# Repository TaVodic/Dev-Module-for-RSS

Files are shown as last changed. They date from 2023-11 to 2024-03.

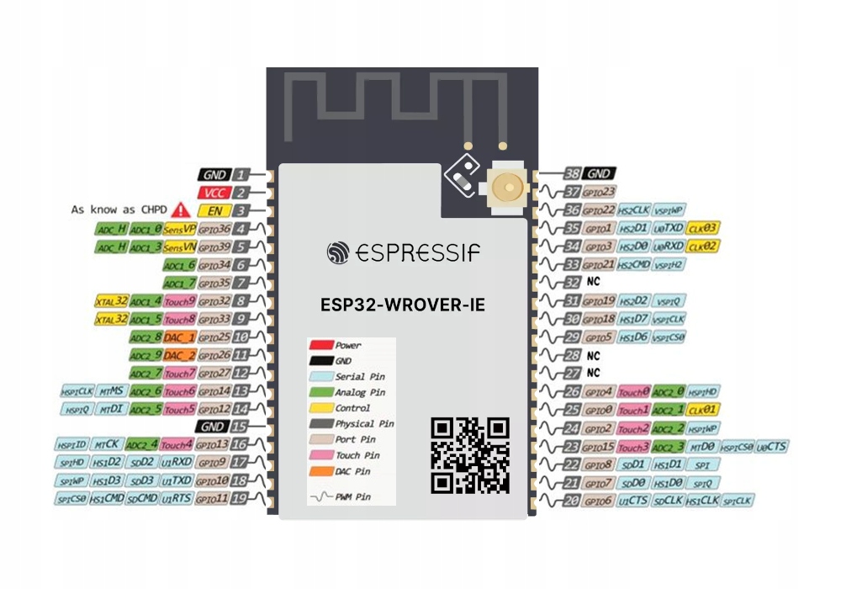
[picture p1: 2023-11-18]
Datasheets/ESP32-WROVER-IE-PINOUT.jpg

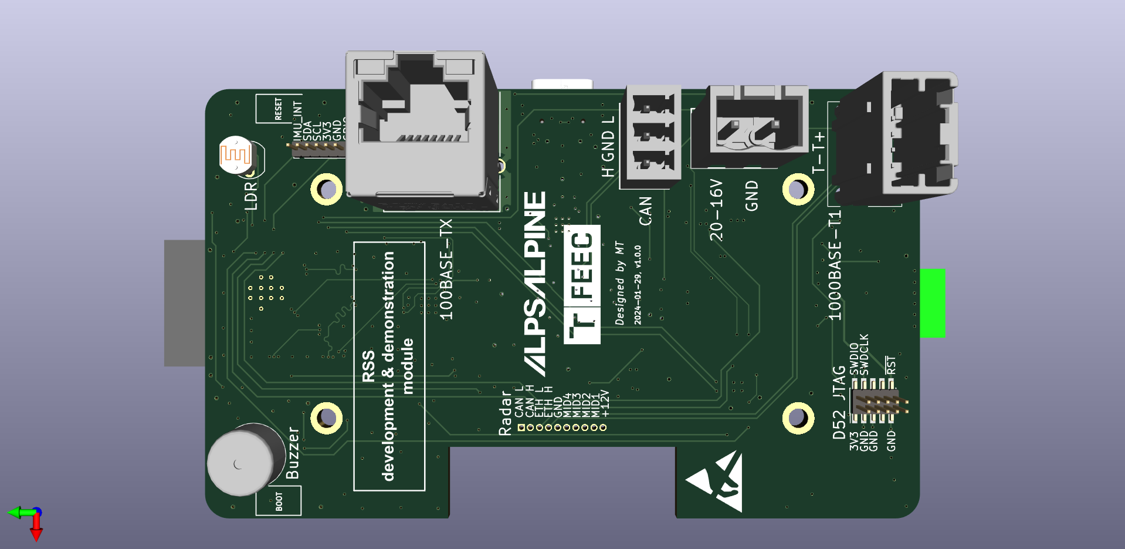
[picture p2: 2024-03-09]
documents/visuals/PCB_3D_BOTTOM_v1.0.0.png

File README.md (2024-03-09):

# Development Module for Safety Radar Sensor in Single-Track Vehicles

<!-- ### Features on PCB
* ESP32
    * BLE
    * MAC
    * 2 UARTs (flashing/debugging + radar interface)
    * $I^2C$ or SPI
* CP2102 USB-UART module
* PHY Ethernet module with connector
* IMU (6+3 DoF)
* Power management
* LED neopixel
* Buzzer
* Pogo pins – board to board connector
* ESP32 GPIO <-> radar pins (FFC conn)
* 100BASE-T1 connector
* ANT+ module -->

The RSS project includes two software repositories:

* ROS2 package as emulation of radar procesing unit and RSS demo module [(RSS_ROS2)](https://gitext.alps.cz/240703/rss_ros2)
* ESP-IDF project for ESP32 implementing uROS and all hardware peripherals [(RSS_uROS)](https://gitext.alps.cz/240703/rss_uros)

### [Schematic design](documents/RSS_schematic_v1.0.0.pdf)

### [Thesis](documents/Tavoda_semestral_thesis.pdf)

### [EEICT article](documents/Development_Module_for_Radar_Safety_Sensor_in_Single_Track_Vehicles.pdf)

### [Photo documentation](documents/visuals/)

### Block diagram



### Power management diagram



### ROS2 graph



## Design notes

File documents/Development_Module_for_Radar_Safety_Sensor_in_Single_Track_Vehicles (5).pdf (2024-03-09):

# Development Module for Radar Safety Sensor in Single-Track Vehicles

Martin Tavoda ˇ

FEEC Department of Radio Electronics Brno University of Technology Brno, Czech Republic
martin.tavoda@vutbr.cz

Abstract—This article describes the hardware and software design of the development module for the Radar Safety Sensor (RSS). RSS uses a Frequency-Modulated Continuous Wave (FMCW) radar to track moving objects behind single-track vehicles. The current radar configuration and antenna have significant object tracking deficiency when the vehicle makes a turn and the radar Field of view (FOV) tilts. The assumed solution is to add an Inertial Measurement Unit (IMU) data to the tracking algorithm. The IMU is implemented in the designed development module, which also provides an efficient development and debugging environment.
Index Terms—embedded device, cyclo-safety equipment, ROS 2, micro-ROS, FMCW radar
I. INTRODUCTION
During the development of firmware for a new product, there is a need for easy debugging and function testing.
The designed module will serve the company ALPS ALPINE Co., Ltd. in the development of Radar Safety Sensor (RSS). Together with the ALPS Generic Radar 5, it should result in a similar device as the already existing Ride Safety System RS 1000 or GARMIN Radar Tail Light. These devices are safety equipment for cyclists that offer information about vehicles behind them. If the vehicle is approaching too quickly or it is driving too close the cyclist and also the driver are warned. [1]
The designed module function is to process data from a IMU and send them to a Single Board Computer (SBC) through a Robot Operating system (ROS) domain. As an output, it collects result data from a ROS domain and triggers an alert. Additionally, it provides robust connectors, power management, ANT+ connection, and physical mount to single-track vehicles, specifically a bicycle. The whole system is supplied from an external 18 V Li-Ion accumulator.

II. PROBLEM FORMULATION
ALPS ALPINE Co., Ltd. is developing a new cyclo product using a proprietary radar system with a new tracking algorithm. However, they ran into a problem. In the default scenario, the radar is mounted under the bicycle seat and the bicycle is moving in a straight line (no tilt). The radar sees multiple points, where some of them are reflections from a static background (the blue dots in Figure 1), and the rest are reflections from actual moving targets behind the bicycle (the green dot in Figure 1).

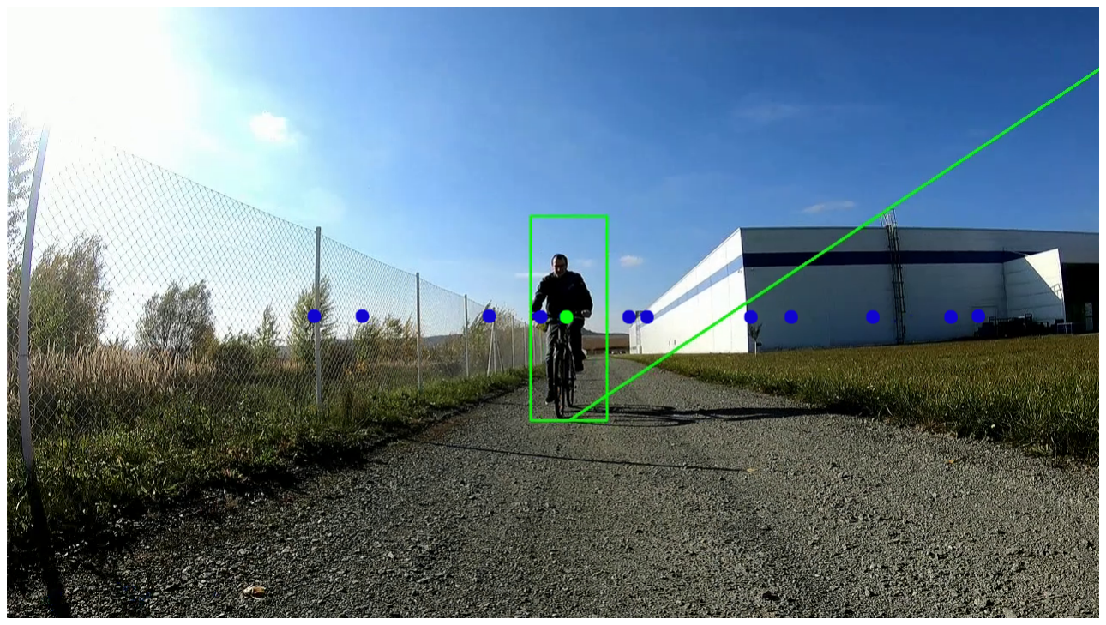
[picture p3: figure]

Fig. 1. Correct tracking - straight ride

In this scenario, these two conditions are easily distinguishable in processed radar data output and the ego-motion vector can be calculated from these reflections of static background. Ego-motion vector describes the motion of an object relative to the rigid scene. [2] In this context it consists of two elements, direction (forward or backward), and speed (approaching or receding). In the current radar configuration, the radar FOV is only a horizontal line, there is no elevation data, and the ego-motion vector is only one-dimensional. The reflections from moving targets are clustered and classified, and a tracking algorithm is used. From these data, it is possible to estimate the moving target trajectory, and speed (approaching or receding),

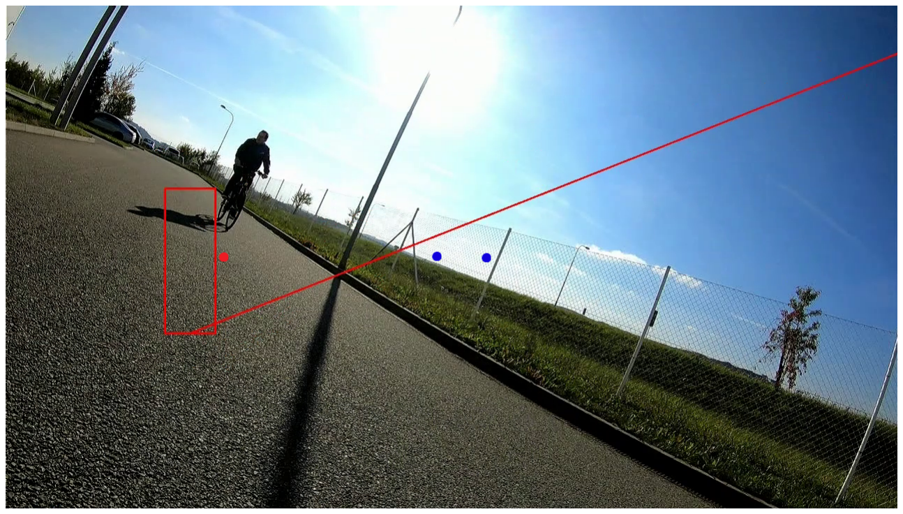
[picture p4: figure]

Fig. 2. Tracking degradation - ride in turn classify if it’s a car or truck, and calculate the possibility of a potential collision.
However, if the bicycle tilts, for example, when turning, the radar FOV also tilts with the same angle and this condition cannot be detected from radar data alone. Since the ego-motion vector is only a single dimensional and the height of the radar from the ground changes, the previously tracked object could be tracked incorrectly (see in Figure 2) or can disappear altogether.
A similar problem is described in [3], but the company requested a simpler approach. One possible solution to this problem seemed to be adjusting the tracking algorithm parameters to be more lenient, but this resulted in insufficient accuracy. The development team decided to try to add to the tracker algorithm some external information about radar tilt and position in space to enhance the tracking estimation. This information can be obtained from an IMU located in a development module.
After the successful implementation of the IMU data into the tracking algorithm by the ALPS team they need to easily show the performance of this product. For this purpose, the development module offers output peripherals such as highly luminous LEDs and loud buzzer and also the ability to connect to external devices such as wireless ANT+ fitness accessories.

III. SYSTEM DESIGN

The system design is shown in Figure 3. The development module for the RSS consists of multiple blocks. The main part is the microcontroller ESP32 which collects the raw data from the IMU using the I²C bus. These data are then processed and sent to the ROS domain via Ethernet. Ethernet connection is provided by Media access control sublayer (MAC) and Physical layer (PHY) interfaces. MAC is included in ESP32 and PHY is an external component. They communicate with each other by Reduced Media-independent interface (RMII). Ethernet was preferred over WiFi due to its lower latency. As IMU is used the MPU5060 chip and the PHY interface is provided by IP101GR.
On the SBC run multiple processes. They are ROS2 graph members, which merge the IMU and radar data and provide

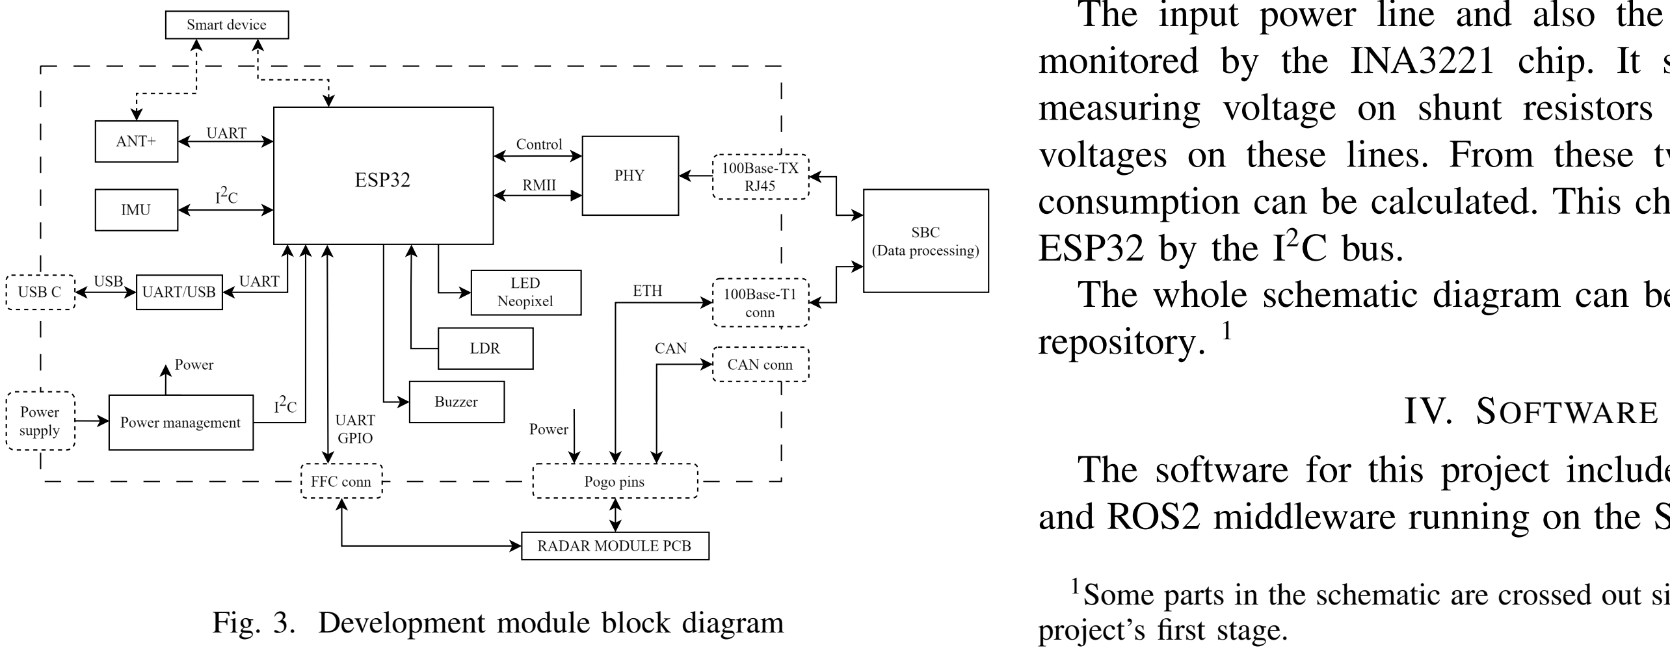
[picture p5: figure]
ESP32 by the I²C bus.; repository. 1; IV. SOFTWARE; project’s first stage.

Fig. 3. Development module block diagram

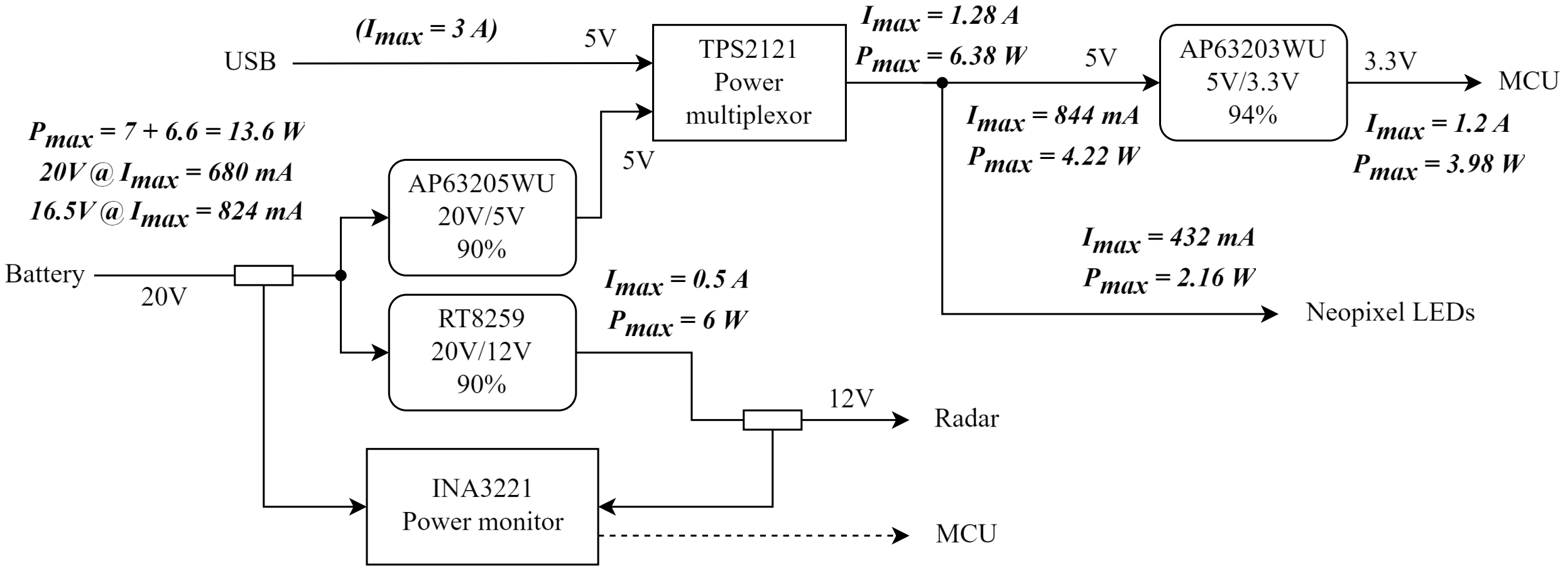
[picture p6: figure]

Fig. 4. Power management block diagram

sensor fusion. This is the tracking algorithm designed by the ALPS development team. The output of this algorithm (a threat level) is sent back to the ESP32, whose task is to provide an alert by visual or sound peripherals.
As visual output the programmable RGB LEDs WS2812B mini are used. They are placed on the perimeter of the Printed circuit board (PCB) and the brightness of these LEDs is adjusted by the software according to the amount of ambient light. This level is read from the external photoresistor by the Analog-to-digital converter (ADC) included in the ESP32. The output threat level from the tracking algorithm can be also wirelessly sent to an external smart device such as a phone or commercially available fitness accessories. This communication is provided by the WiFi peripheral inside ESP32 or the external ANT+ module D52 by GARMIN. The power management block is shown in Figure 4 and it consists of four power lines. The external accumulator has a nominal voltage of V = 18 V but the radar needs to be supplied with a voltage of V = 12 V. Therefore the RT2589 DC/DC step-down converter is used. For supplying LEDs the AP63205 DC/DC converter with fixed output voltage V = 5 V was chosen. The same converter but with a different fixed output voltage of V = 3.3 V is used to supply all chips on the PCB.
Besides the fact that the USB connector serves as a programming interface for the ESP32, it also serves as a second power source. The seamless transition between 5 V converted from the battery voltage and the voltage from the USB is provided by the TPS2121 power multiplexer. When both sources are available the USB source has priority, but when it’s not present the module is powered by the battery.
The input power line and also the 12 V power line are monitored by the INA3221 chip. It senses the current by measuring voltage on shunt resistors and it also measures voltages on these lines. From these two values, the power consumption can be calculated. This chip communicates with

The whole schematic diagram can be found in the GitHub

The software for this project includes firmware in ESP32 and ROS2 middleware running on the SBC. The whole ROS2

1Some parts in the schematic are crossed out since they are not used in the

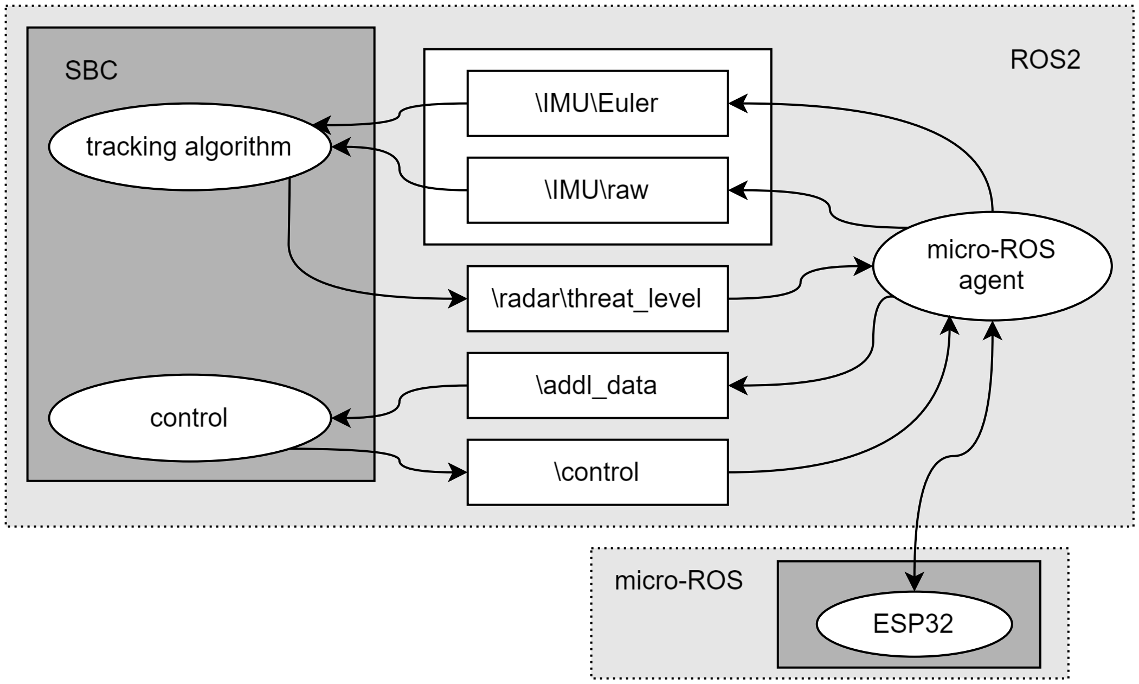
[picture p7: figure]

Fig. 5. RSS ROS2 graph (nodes are in ellipses, topics are in rectangles)

graph can be seen in Figure 5. The SBC runs two ROS2 nodes. One of them, the tracking algorithm, subscribes to topics containing the Euler angles and raw data from the IMU. As an output, it publishes the threat level. The other node, the control node, subscribes to additional information, such as temperature, power consumption, and amount of ambient light, and publishes instructions for power management ICs. All the topics use standard ROS2 messages. Development of this system was done on Microsoft WSL with running the Ubuntu distribution. All ROS2 principles were sourced from the ROS2 wiki. [4]
The firmware for ESP32 was written in C using the ESP-IDF framework. While ROS2 is a powerful tool for nonresource-constrained devices, for embedded devices it cannot be used. Fortunately, there exists a lightweight version of ROS2 for microcontrollers, called the micro-ROS. [5] It can be compiled for ESP32 but to communicate with the ROS2 graph it needs an agent, which runs also on SBC. The micro-ROS libraries were imported to the ESP-IDF environment as a component and were used to create the only node on ESP32. The whole firmware is supported by the FreeRTOS system. The ESP32 takes the raw data from the IMU as linear acceleration and angular velocity and transforms them using the Kalman filter to Euler angles. This method is described in [6]. The node publishes both the raw data and the Euler angles. On the other hand, the subscribed threat level is used to light up the LEDs or beep the buzzer. The additional information on power consumption is calculated from voltage and current values obtained from the power monitor IC. This information together with others previously mentioned is published to the \addl data topic. The voltage converter for the radar can be disabled according to the message from the \control topic.
V. HARDWARE DESIGN

The PCB was designed in KiCad freeware software. Since the design includes 50 MHz clock lines and differential pairs, the impedance control and delay matching principles had to be followed when designing the PCB. The PCB has four layers with the following stack-up: high-speed traces, GND plane,

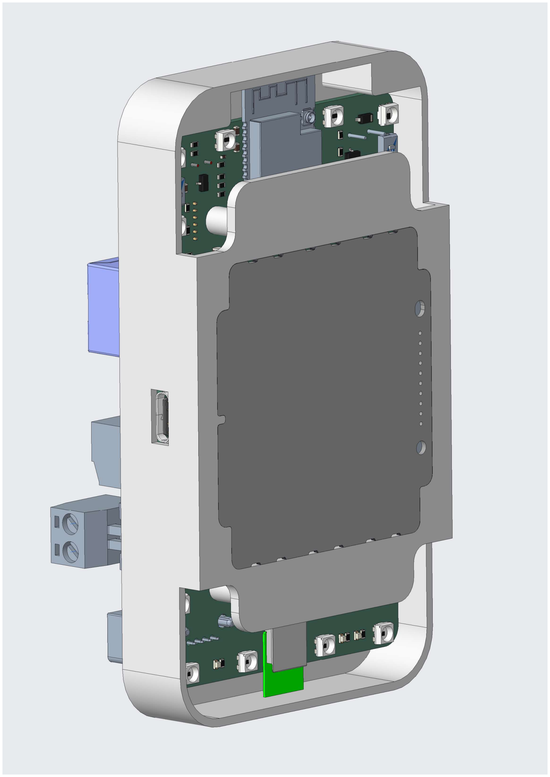
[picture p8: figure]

Fig. 6. 3D design of the enclosure with the module and radar board

power domains, and low-speed signals. The visuals of the PCB can be found in the GitHub repository. (https://github.com/TaVodic/Dev-Module-for-RSS/tree/public_files/documents/visuals)
The ALPS Generic Radar 5 is connected to the development module by spring-loaded pins and Flexible flat cable (FFC) used for future debugging. Both boards are enclosed in 3D printed covering mounted on the seat pole of a bicycle. The design of the complete device is shown in Figure 6.

VI. CONCLUSION
The development module was designed, manufactured, and assembled according to the needs of the company. The software concept was presented and needs to be programmed and verified. Finally, the ALPS development team can use this module for future development of the ALPS Generic Radar 5, but mainly to prove the concept of enhancing the tracking algorithm by the external IMU data.

REFERENCES

[1] P. Norman, “What are rearview radar bike lights and should you use one?”, Bike Radar, 2023.
[2] N. H. Khan and A. Adnan, “Ego-motion estimation concepts, algorithms and challenges: an overview”, Multimedia Tools and Applications, vol. 76, no. 15, pp. 16581-16603, 2017.
[3] L. Seongwook, S. Lee, S. Lim, and S. -C. Kim, “Machine Learning-Based Estimation for Tilted Mounting Angle of Automotive Radar Sensor”, EEE Sensors Journal, vol. 20, no. 6, pp. 2928-2937, 2020.
[4] S. Macenski, T. Foote, B. Gerkey, C. Lalancette, and W. Woodall, “Robot Operating System 2: Design, architecture, and uses in the wild”, Science Robotics, vol. 7, no. 66, May 2022.
[5] P. Nguyen, “MICRO-ROS FOR MOBILE ROBOTICS SYSTEMS”, Master thesis, Vaster ¨ as, 2022. ˚
[6] H. Ferdinando, H. Khoswanto, and D. Purwanto, “Embedded Kalman Filter for Inertial Measurement Unit (IMU) on the ATMega8535”, in 2012 International Symposium on Innovations in Intelligent Systems and Applications, 2012, pp. 1-5.

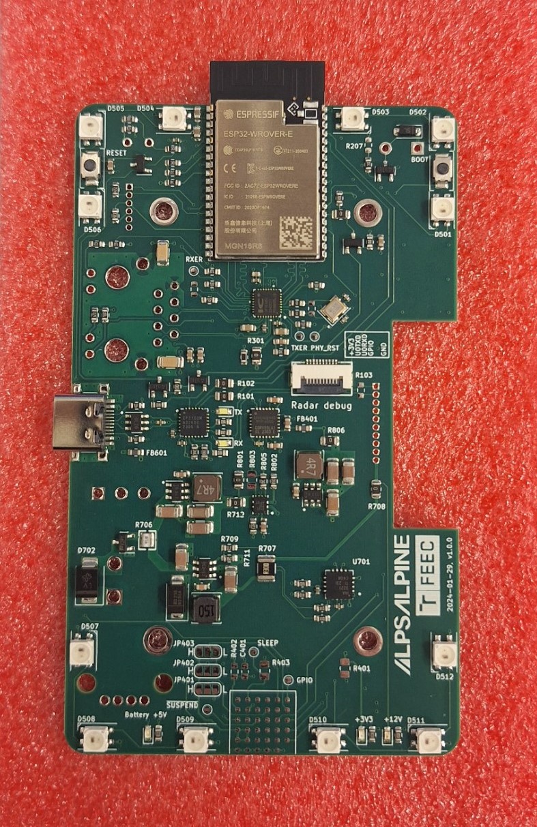
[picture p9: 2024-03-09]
documents/visuals/TOP.jpeg

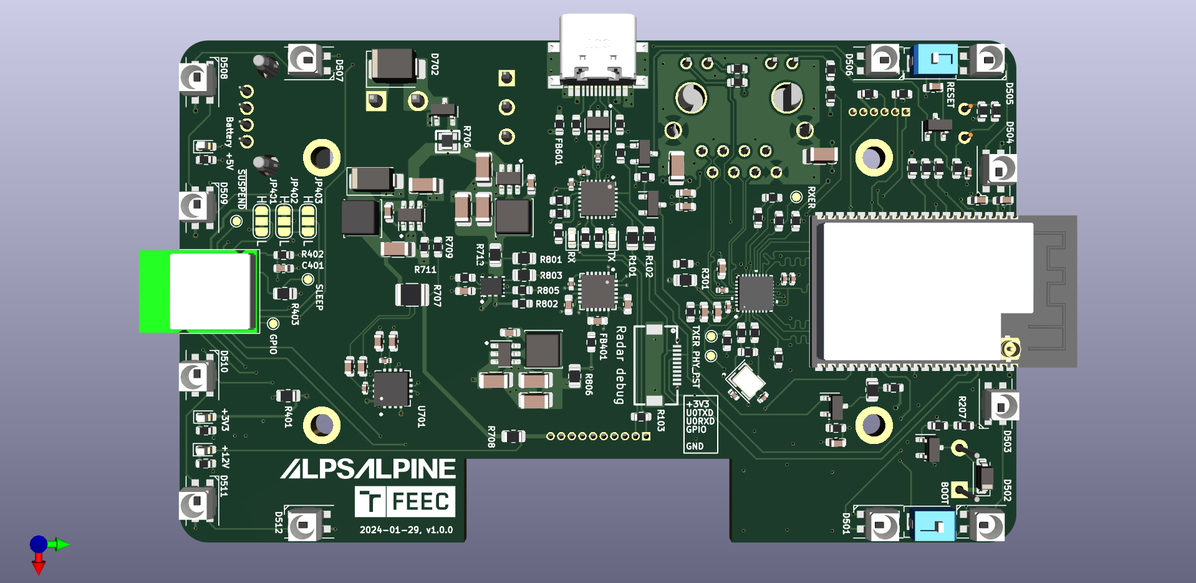
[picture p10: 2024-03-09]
documents/visuals/PCB_3D_TOP_v1.0.0.png

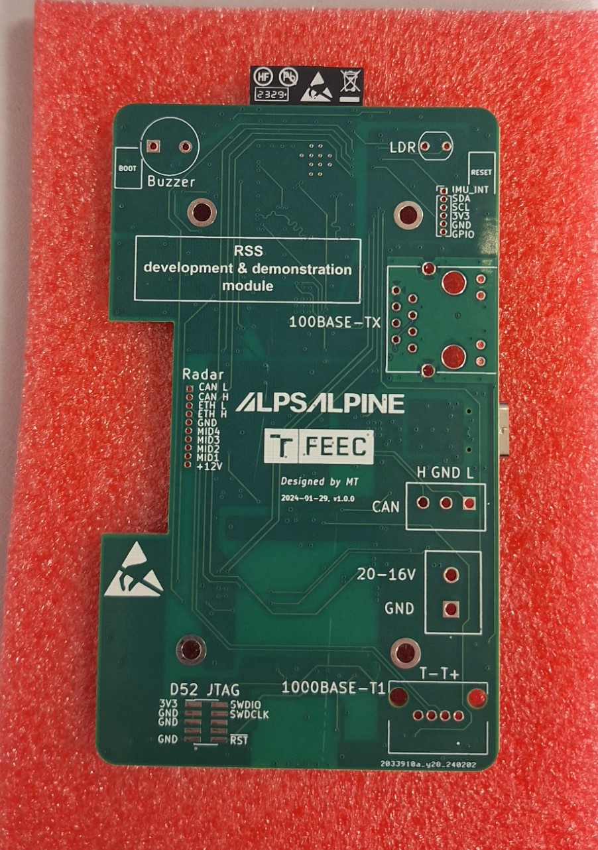
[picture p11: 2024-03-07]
documents/visuals/BOTTOM.jpeg

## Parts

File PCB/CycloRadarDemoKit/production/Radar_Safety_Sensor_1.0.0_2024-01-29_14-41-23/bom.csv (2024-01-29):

Designator | Footprint | Quantity | Value | LCSC Part #
BZ501 | Buzzer_D9mm_P5mm | 1 | Buzzer
C201, C202 | 0603 | 2 | 10uF | C19702
C203, C303, C304, C306, C601, C602, C701, C702 | 0402 | 8 | 1uF/25V(10%) | C52923
C204, C205, C301, C310, C311, C403, C404, C706, C801, C802 | 0603 | 10 | 100nF/50V(10%) | C14663
C302 | 0402 | 1 | 10uF/25V(20%) | C15525
C305, C307 | 0603 | 2 | 10uF/25V(20%) | C96446
C308, C309 | 0402 | 2 | 20pF/50V(5%) | C182483
C312, C313 | 1206 | 2 | 4.7nF/2kV(10%) | C41017
C402 | 0402 | 1 | 10nF/50V(10%) | C15195
C405 | 0603 | 1 | 2.2nF/50V(10%) | C1604
C603 | 0402 | 1 | 100nF
C703 | 0603 | 1 | 10nF/50V(10%) | C57112
C704, C707, C709, C803, C805 | 1206 | 5 | 22uF/16V(20%) | C12891
C705, C708, C804 | 1206 | 3 | 10uF/50V(20%) | C13585
D201, D202 | SOT-23 | 2 | BAT54A | C283256
D501, D502, D503, D504, D505, D506, D507, D508, D509, D510, D511, D512 | LED_SK6812MINI_PLCC4_3.5x3.5mm_P1.75mm | 12 | WS2812B | C527089
D513 | D_SOD-123 | 1 | B5819W | C8598
D601, D602 | 0603 | 2 | LED_TX | C3028830
D701 | 0603 | 1 | LED_12V | C284922
D702 | D_SMB | 1 | SMBJ20A | C3001979
D703 | D_SMA | 1 | B230A-13-F | C12889
D704 | 0603 | 1 | LED_5V | C87326
D801 | 0603 | 1 | LED_3V3 | C497937
FB401, FB601 | 0603 | 2 | YI160808Z101-3R0T | C3011210
J101 | PinHeader_1x06_P1.27mm_Vertical | 1 | I2C conn
J103 | Molex_39501-1003 | 1 | CAN
J104 | Molex_347920040 | 1 | 100BASE-T1
J105 | AFC30-S10FCC-00 | 1 | Radar debug | C395235
J301 | RJ45_Taoglas_TMJD0012BENL | 1 | TMJD0012BENL
J601 | TYPE-C-SMD_YIYUAN_YTC-TC16-273A1 | 1 | USB_C_Receptacle_USB2.0 | C5260486
J701 | Molex_39521-1002 | 1 | 20-16V Supply Voltage
L701 | L_Changjiang_FNR4018S | 1 | 15uH/1A | C167809
L702, L801 | L_Sunlord_SWPA4020S | 2 | 4.7uH/2.85A | C98363
Q501, Q601, Q602 | SOT-23 | 3 | L8050QLT1G | C49581
Q701 | SOT-23 | 1 | SI2309CDS | C3021112
R101, R102, R301, R505, R708, R712, R801, R806 | 0805 | 8 | 0R | C17477
R201, R502 | 0603 | 2 | 20K(1%) | C4184
R202, R203, R204, R307, R503, R701, R805 | 0603 | 7 | 10K(1%) | C25804
R205, R206 | 0603 | 2 | 4.7K | C23162
R208, R601 | 0603 | 2 | 1K(1%) | C21190
R302, R303, R304, R305, R306, R309, R315, R608, R609 | 0603 | 9 | 5.1K(1%) | C23186
R308 | 0603 | 1 | 6.19K(1%) | C403300
R310, R314 | 0603 | 2 | 0R | C21189
R311 | 0603 | 1 | 270R | C22966
R313 | 0603 | 1 | 220R | C22962
R501 | R_LDR_5.1x4.3mm_P3.4mm_Vertical | 1 | LDR
R504 | 0603 | 1 | 820R | C23253
R602, R604 | 0603 | 2 | 100K(1%) | C25803
R603 | 0603 | 1 | 22.1K(1%) | C25961
R605 | 0603 | 1 | 47.5K(1%) | C23061
R606, R607 | 0603 | 2 | 100R | C22775
R702, R703, R704, R705 | 0603 | 4 | 10R(1%) | C22859
R706 | R_Shunt_LTR10EVHJLR18 | 1 | 0.18R(5%) | C253348
R707 | 1210 | 1 | 0.3R(5%) | C188102
R709 | 0603 | 1 | 51K(1%) | C23196
R710, R713 | 0603 | 2 | 2K | C22975
R711 | 0603 | 1 | 3.6K(1%) | C22980
R802 | 0603 | 1 | 1.1K(1%) | C22764
R804 | 0603 | 1 | 47k(1%) | C25819
R807 | 0603 | 1 | 200R | C8218
SW201 | SW_SPST_TS-1088R | 1 | RESET | C455280
SW202 | SW_SPST_TS-1088R | 1 | BOOT MODE | C455280
U201 | ESP32-WROVER-E_ThermalVias | 1 | ESP32-WROVER-E-N16R8 | C529589
U301 | QFN_IP101GRI_WIZ | 1 | IP101GRI | C703537
U402 | InvenSense_QFN-24_4x4mm_P0.5mm | 1 | MPU-6050 | C24112
U601 | QFN-24-1EP_4x4mm_P0.5mm_EP2.6x2.6mm | 1 | CP2102N-Axx-xQFN24 | C969151
U602 | SOT-23-6 | 1 | USBLC6-2SC6 | C7519
U701 | Texas_RGV_S-PVQFN-N16_EP2.1x2.1mm | 1 | INA3221 | C181255
U702 | TSOT-23-6 | 1 | RT8259 | C425775
U703 | TSOT-23-6 | 1 | AP63205WU | C2071056
U801 | TPS2121 | 1 | TPS2121RUXR | C485916
U802 | TSOT-23-6 | 1 | AP63203WU | C780769
Y301 | Crystal_SMD_3225-4Pin_3.2x2.5mm | 1 | 25MHz | C3003239

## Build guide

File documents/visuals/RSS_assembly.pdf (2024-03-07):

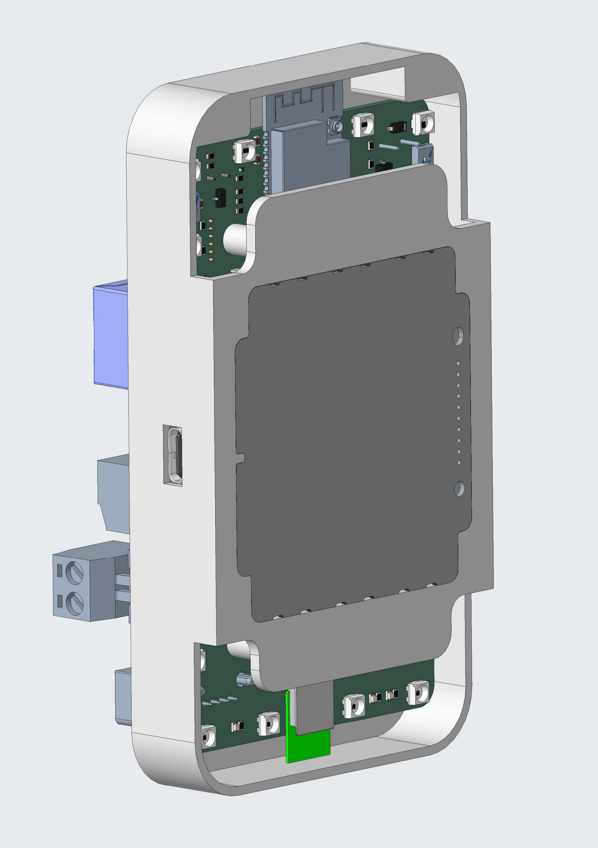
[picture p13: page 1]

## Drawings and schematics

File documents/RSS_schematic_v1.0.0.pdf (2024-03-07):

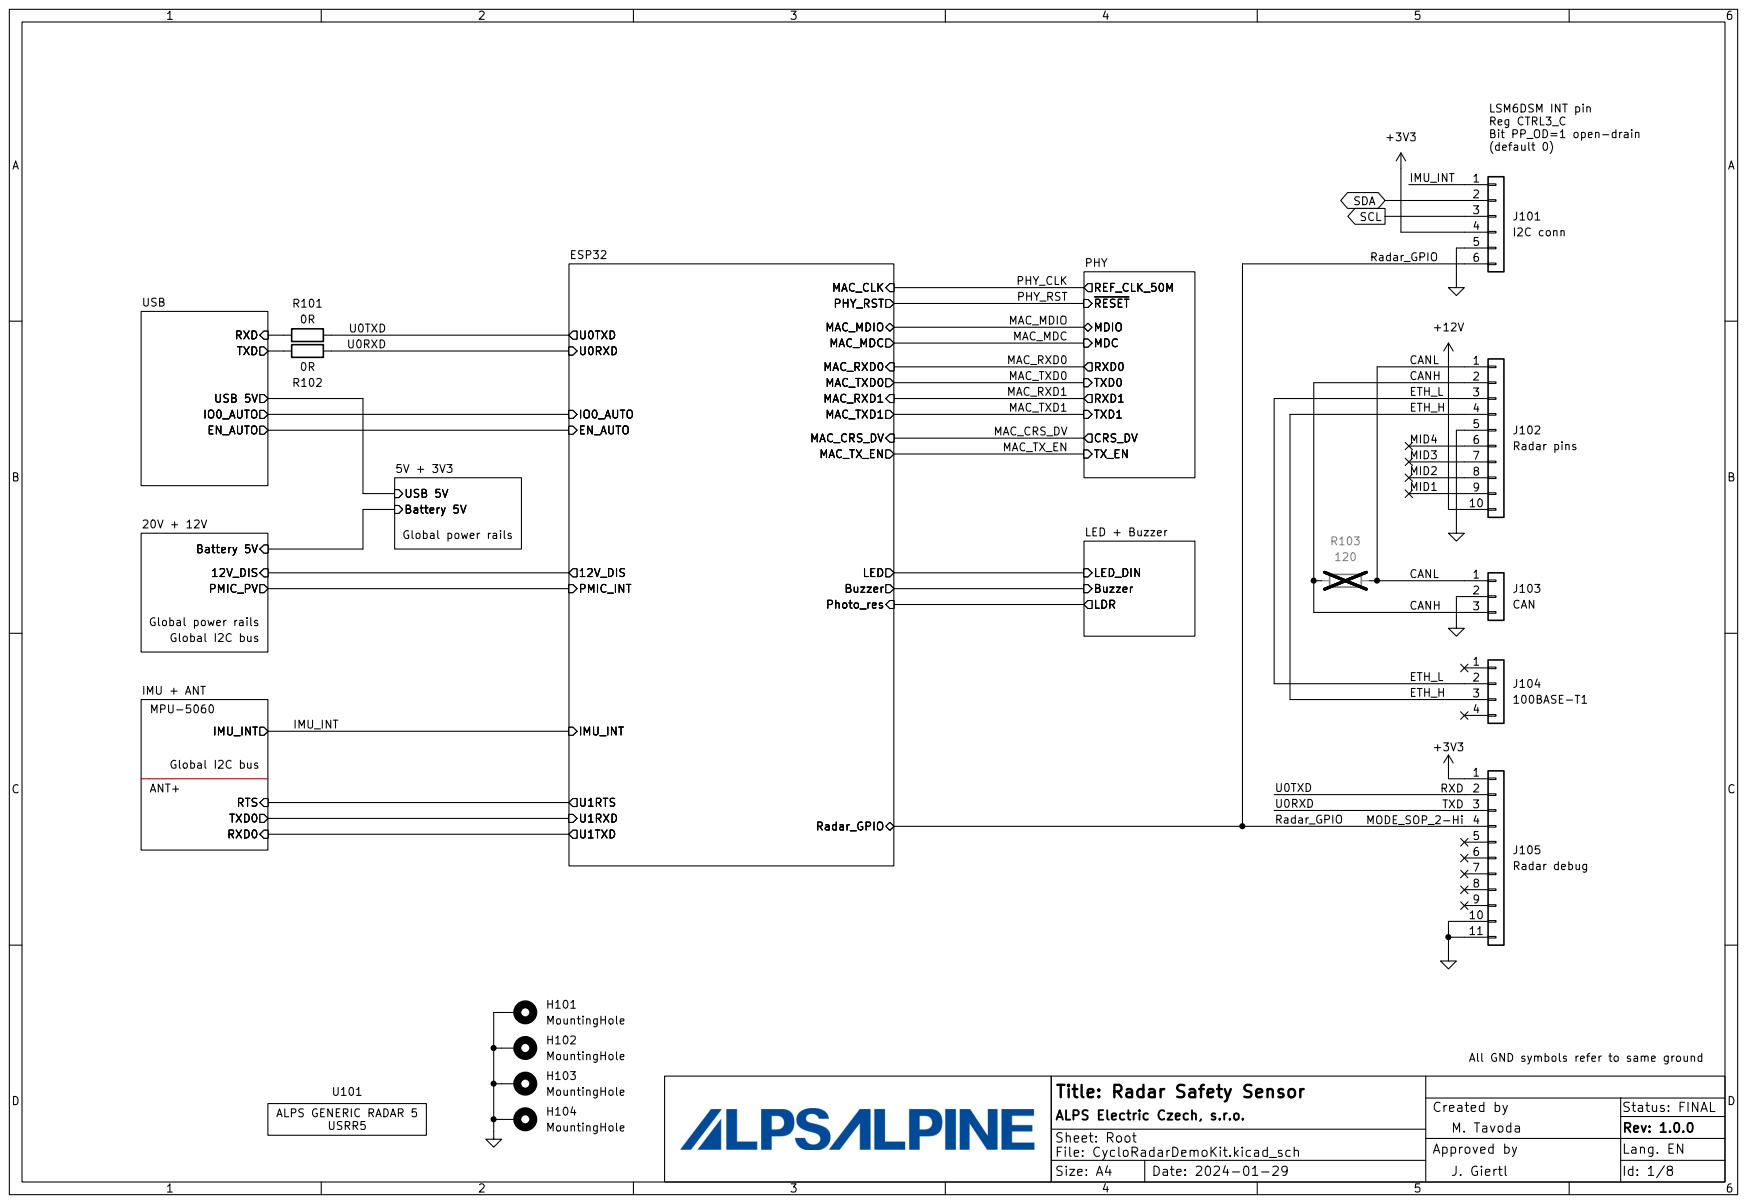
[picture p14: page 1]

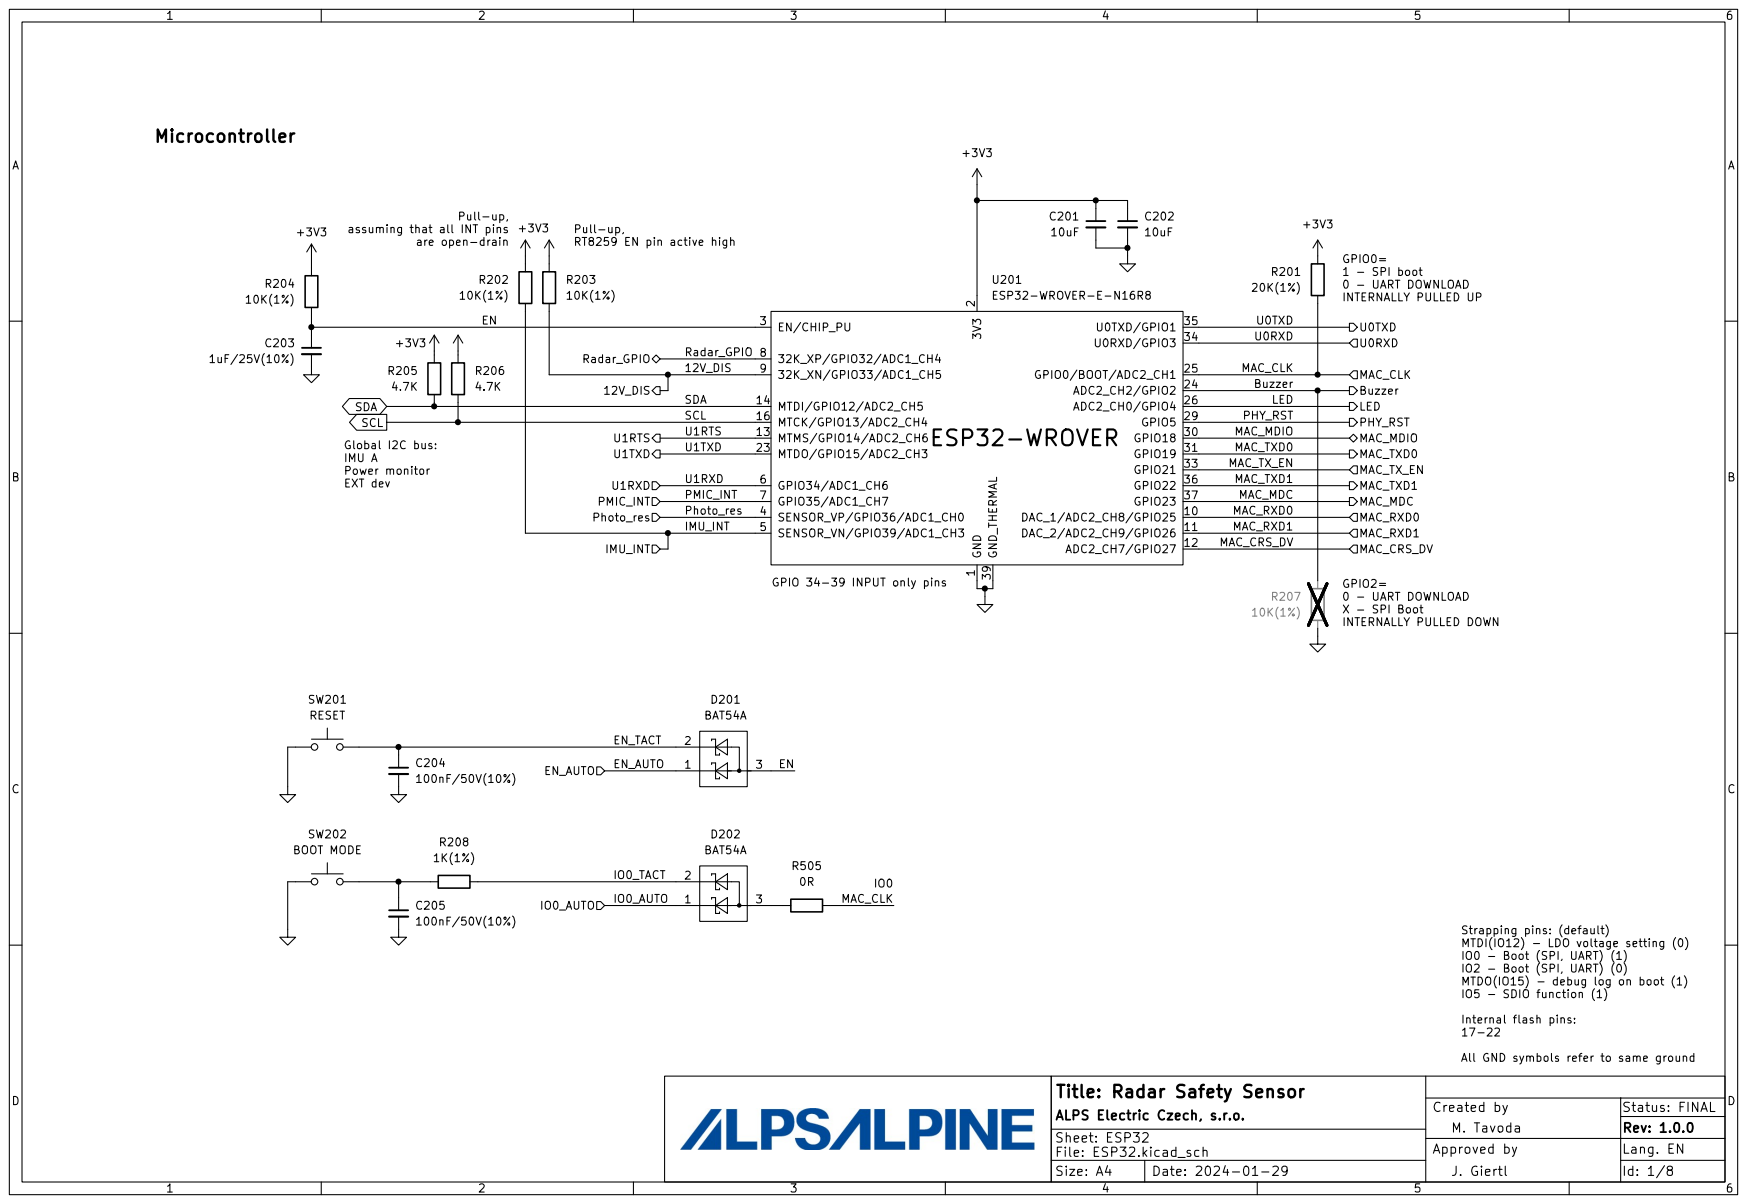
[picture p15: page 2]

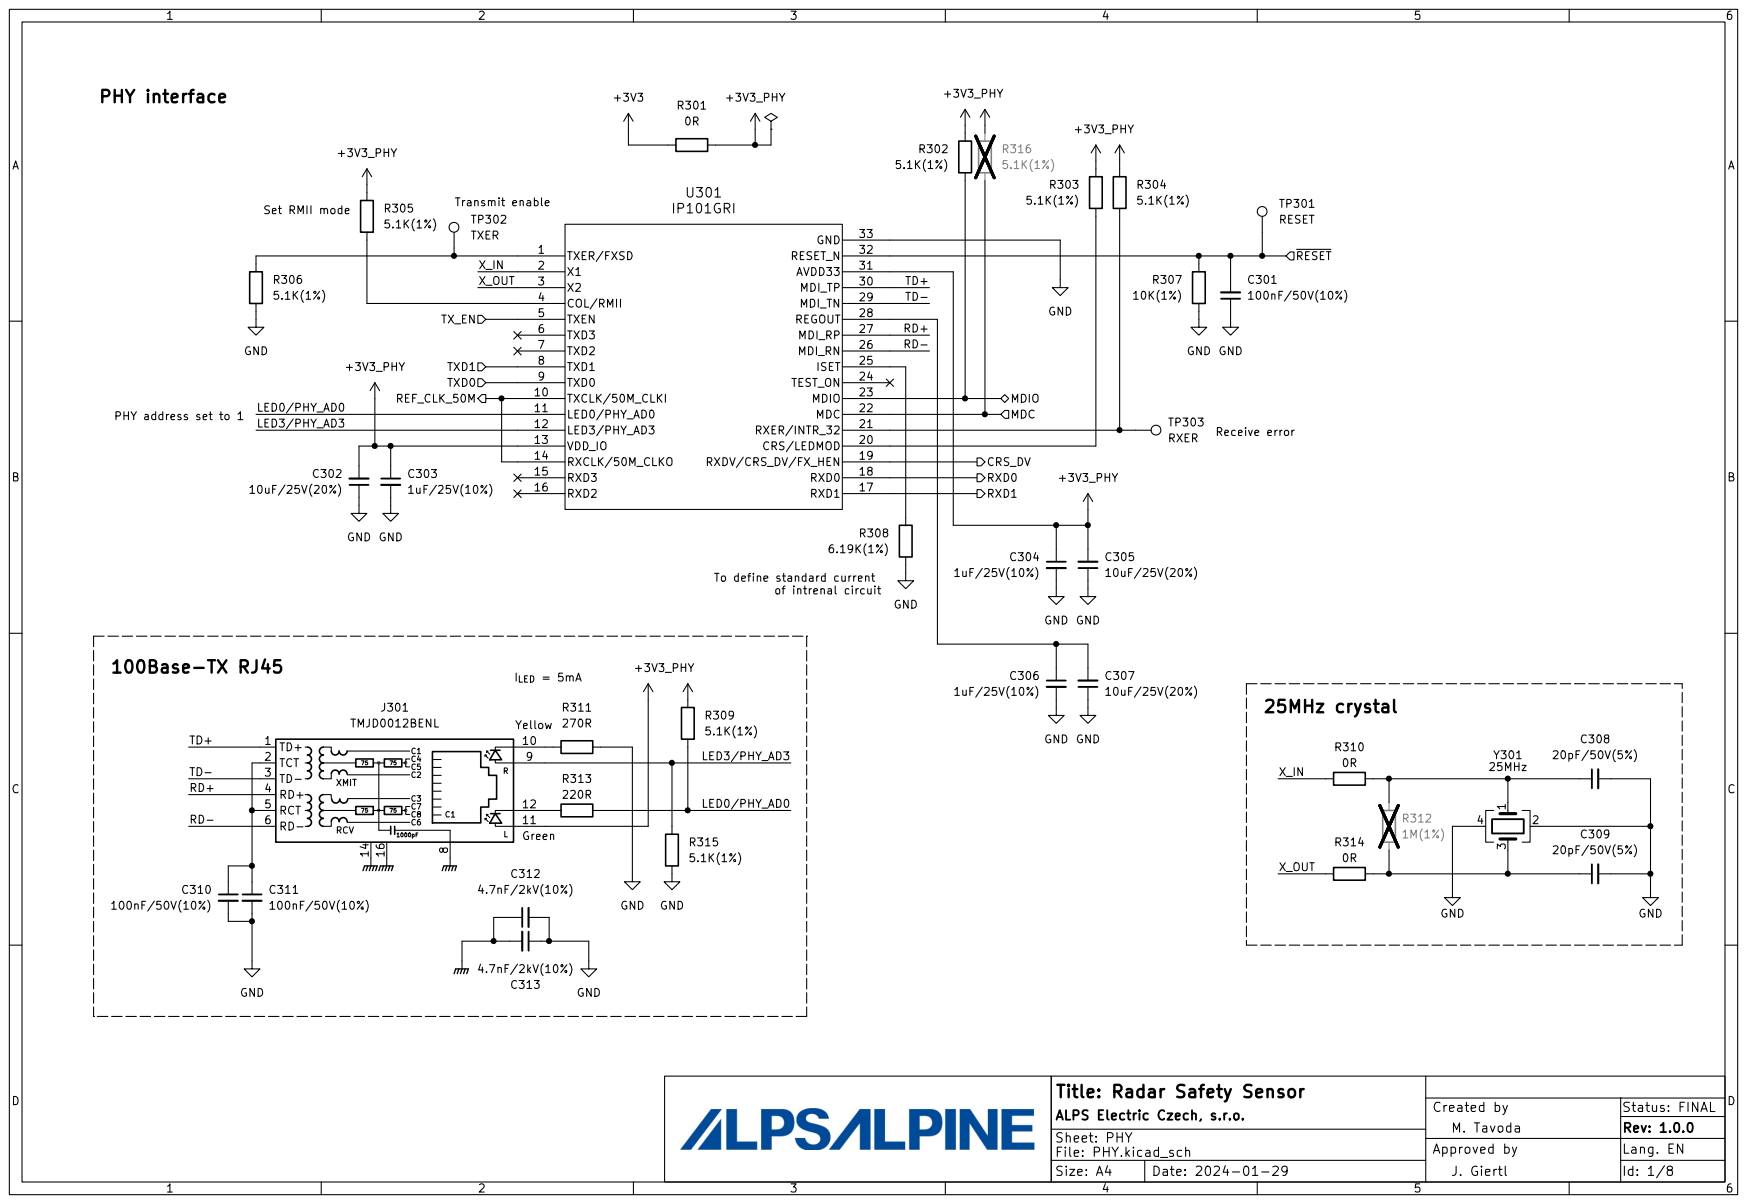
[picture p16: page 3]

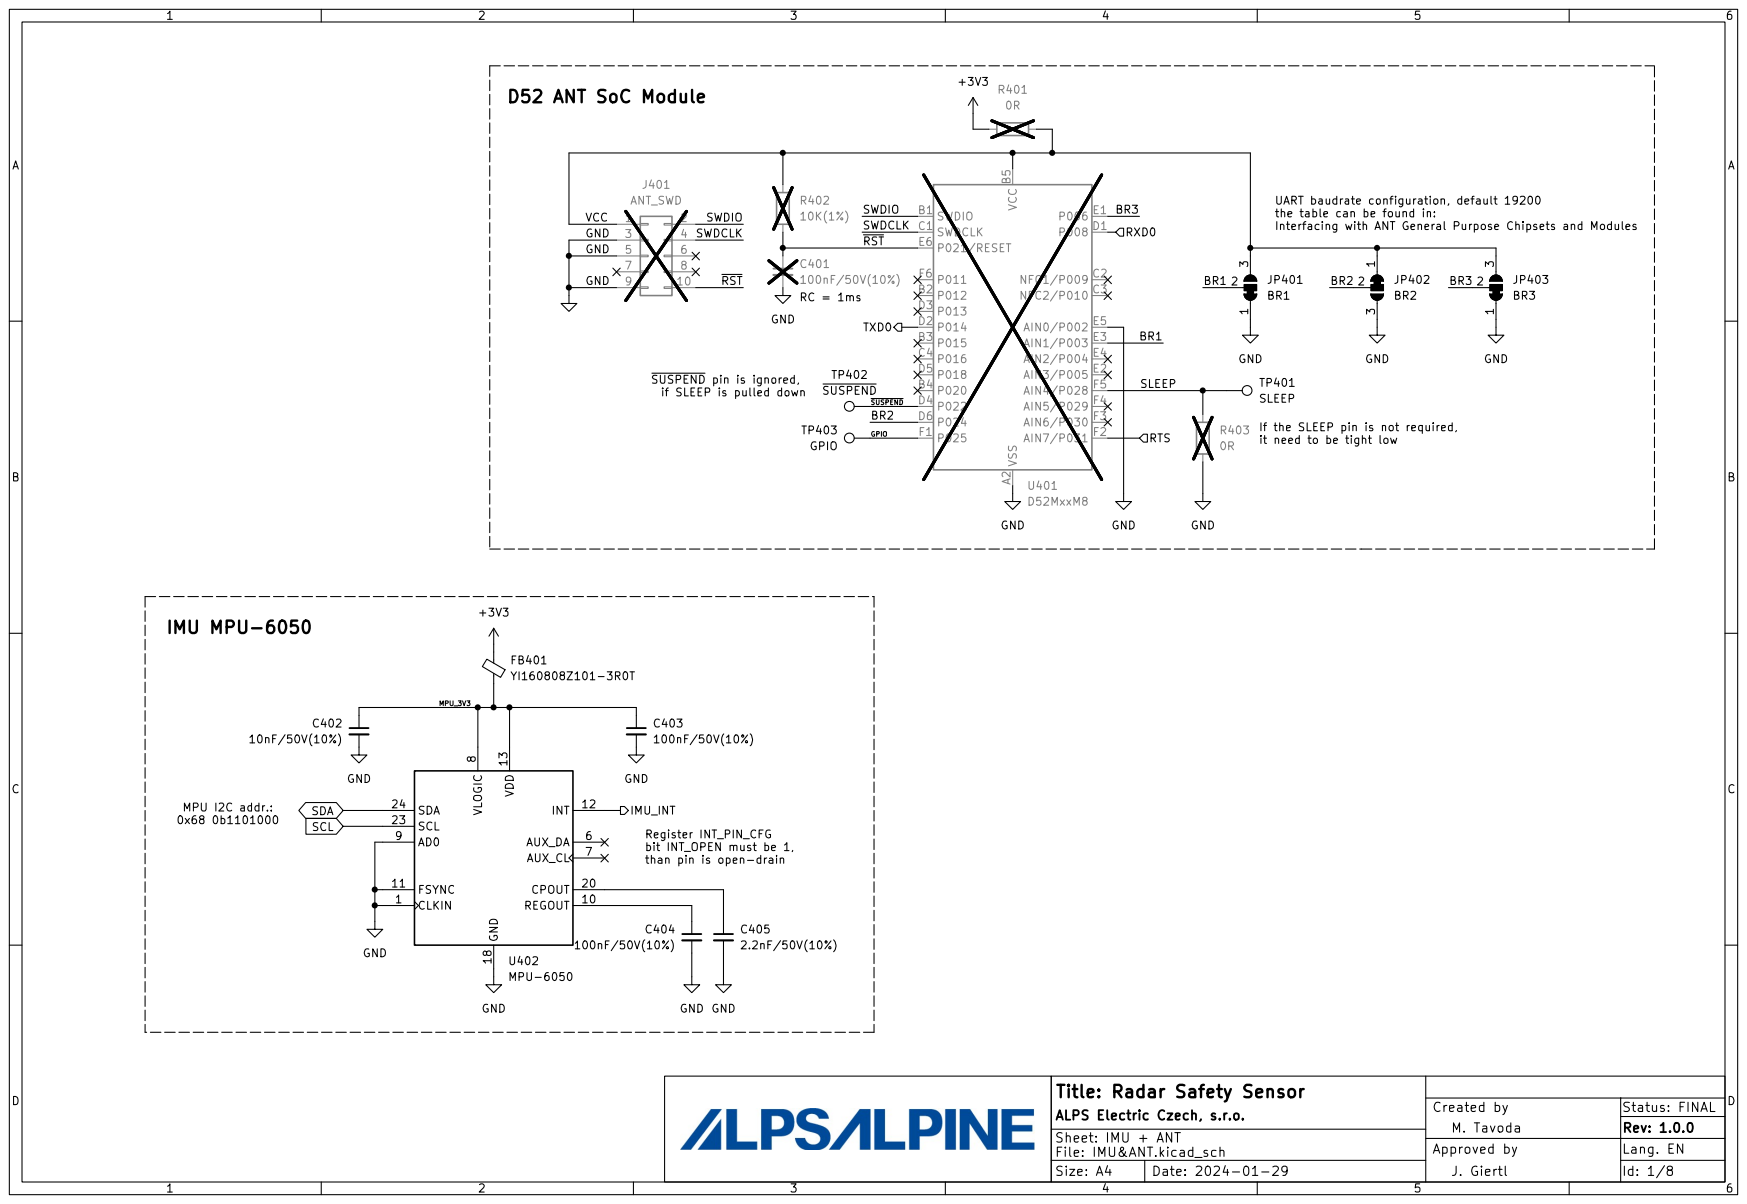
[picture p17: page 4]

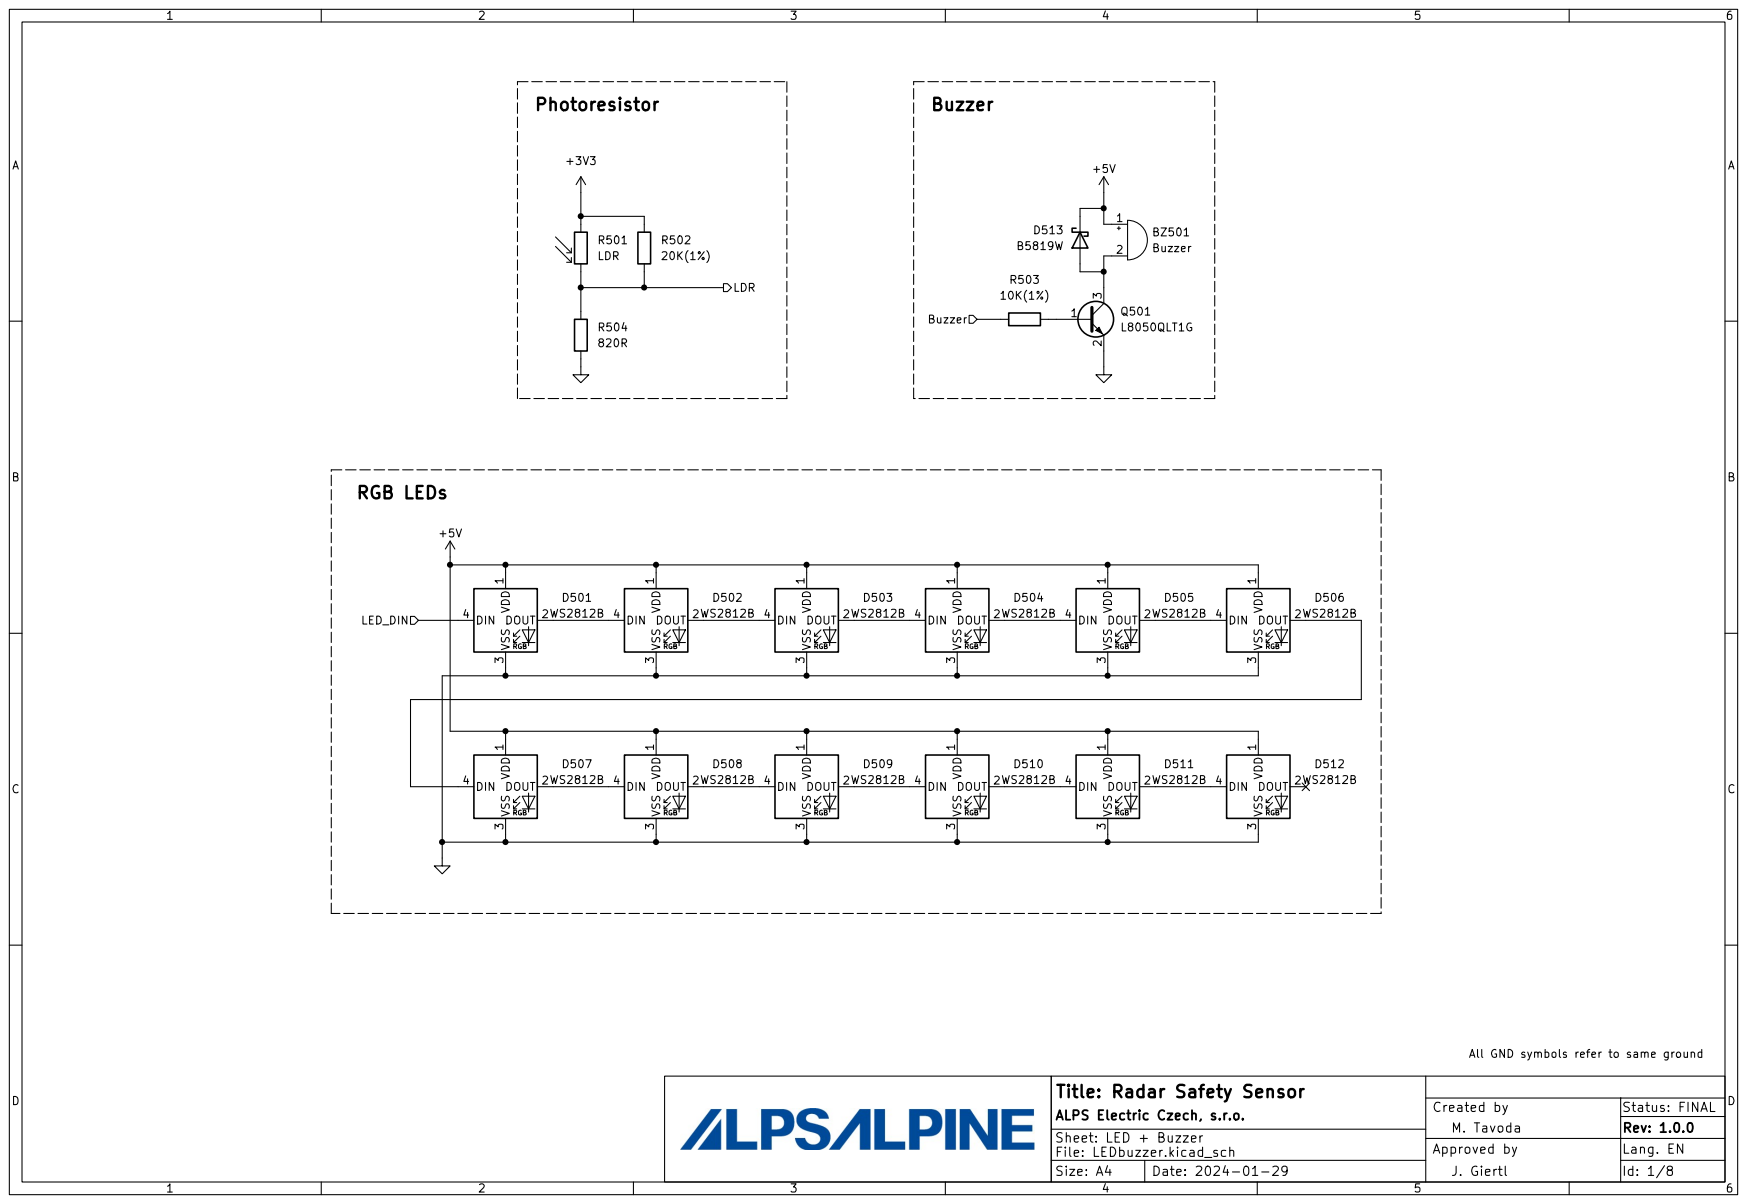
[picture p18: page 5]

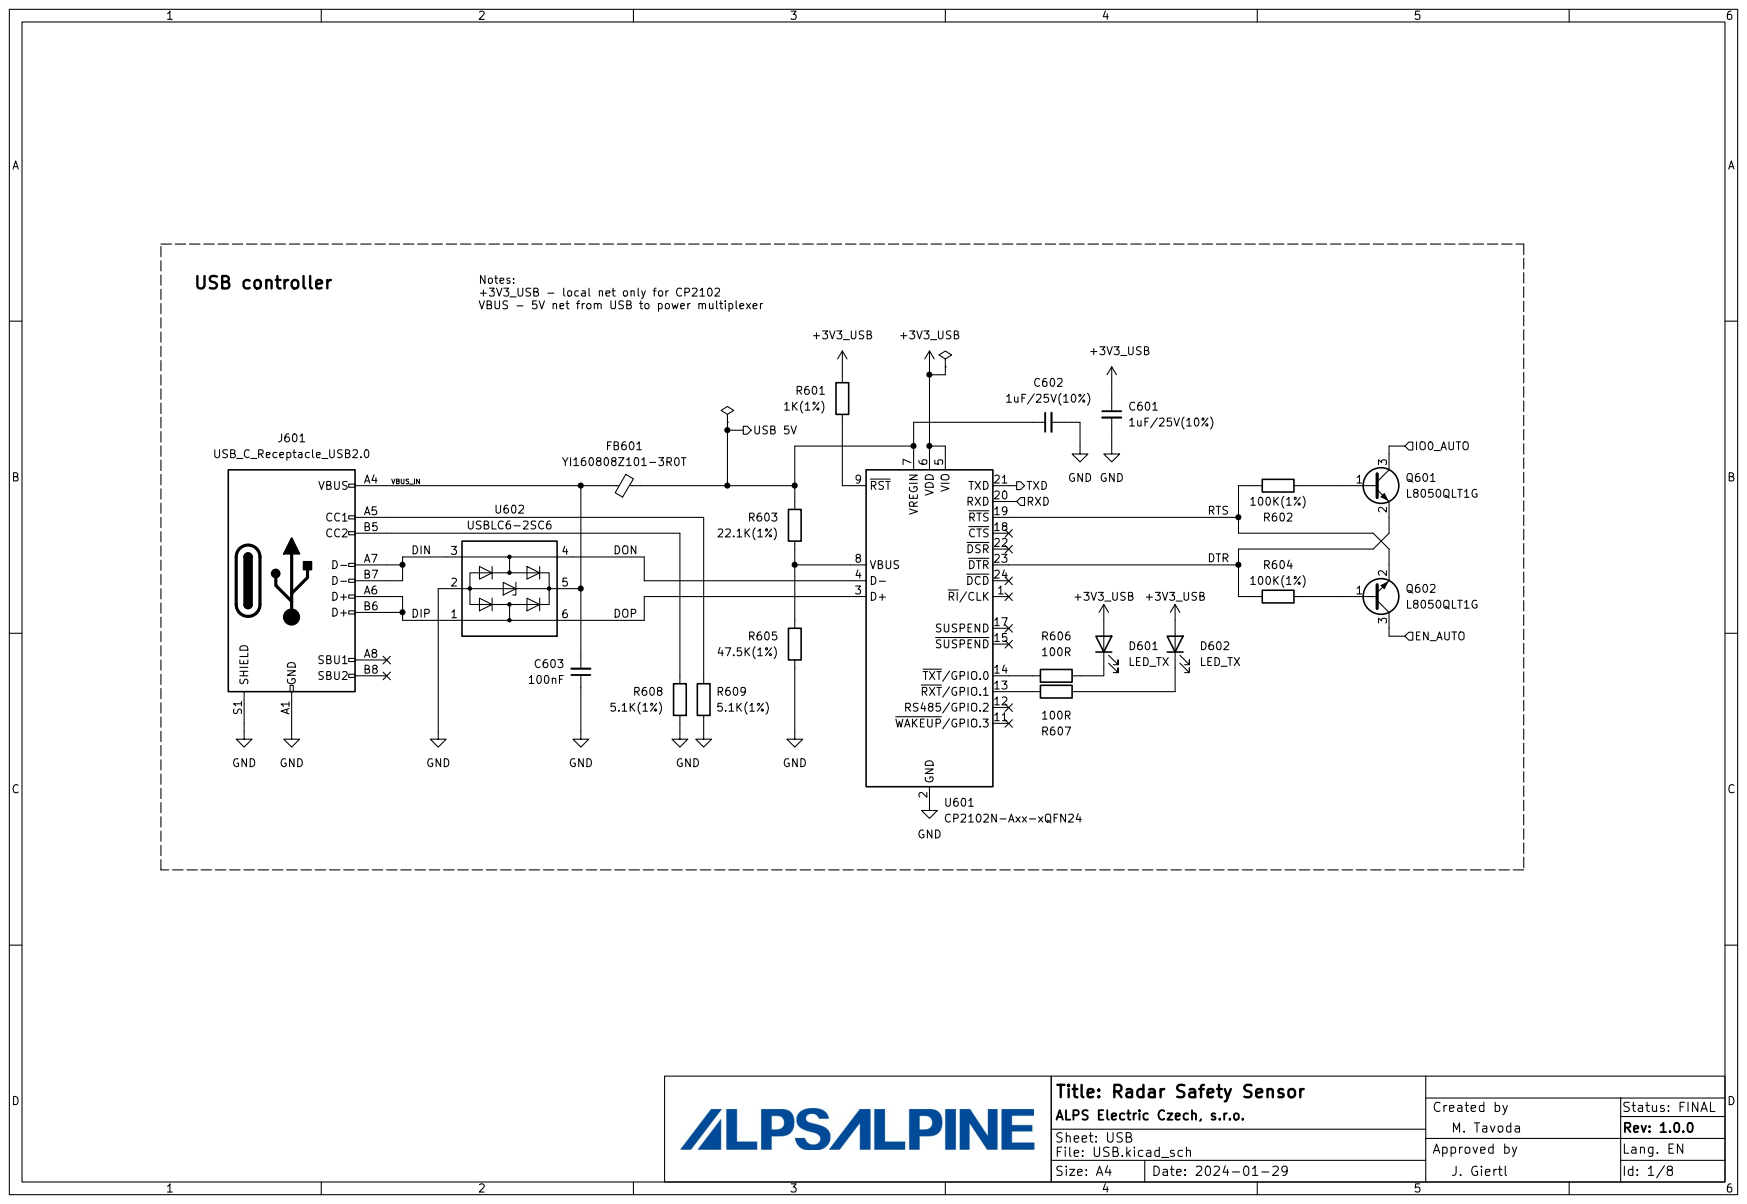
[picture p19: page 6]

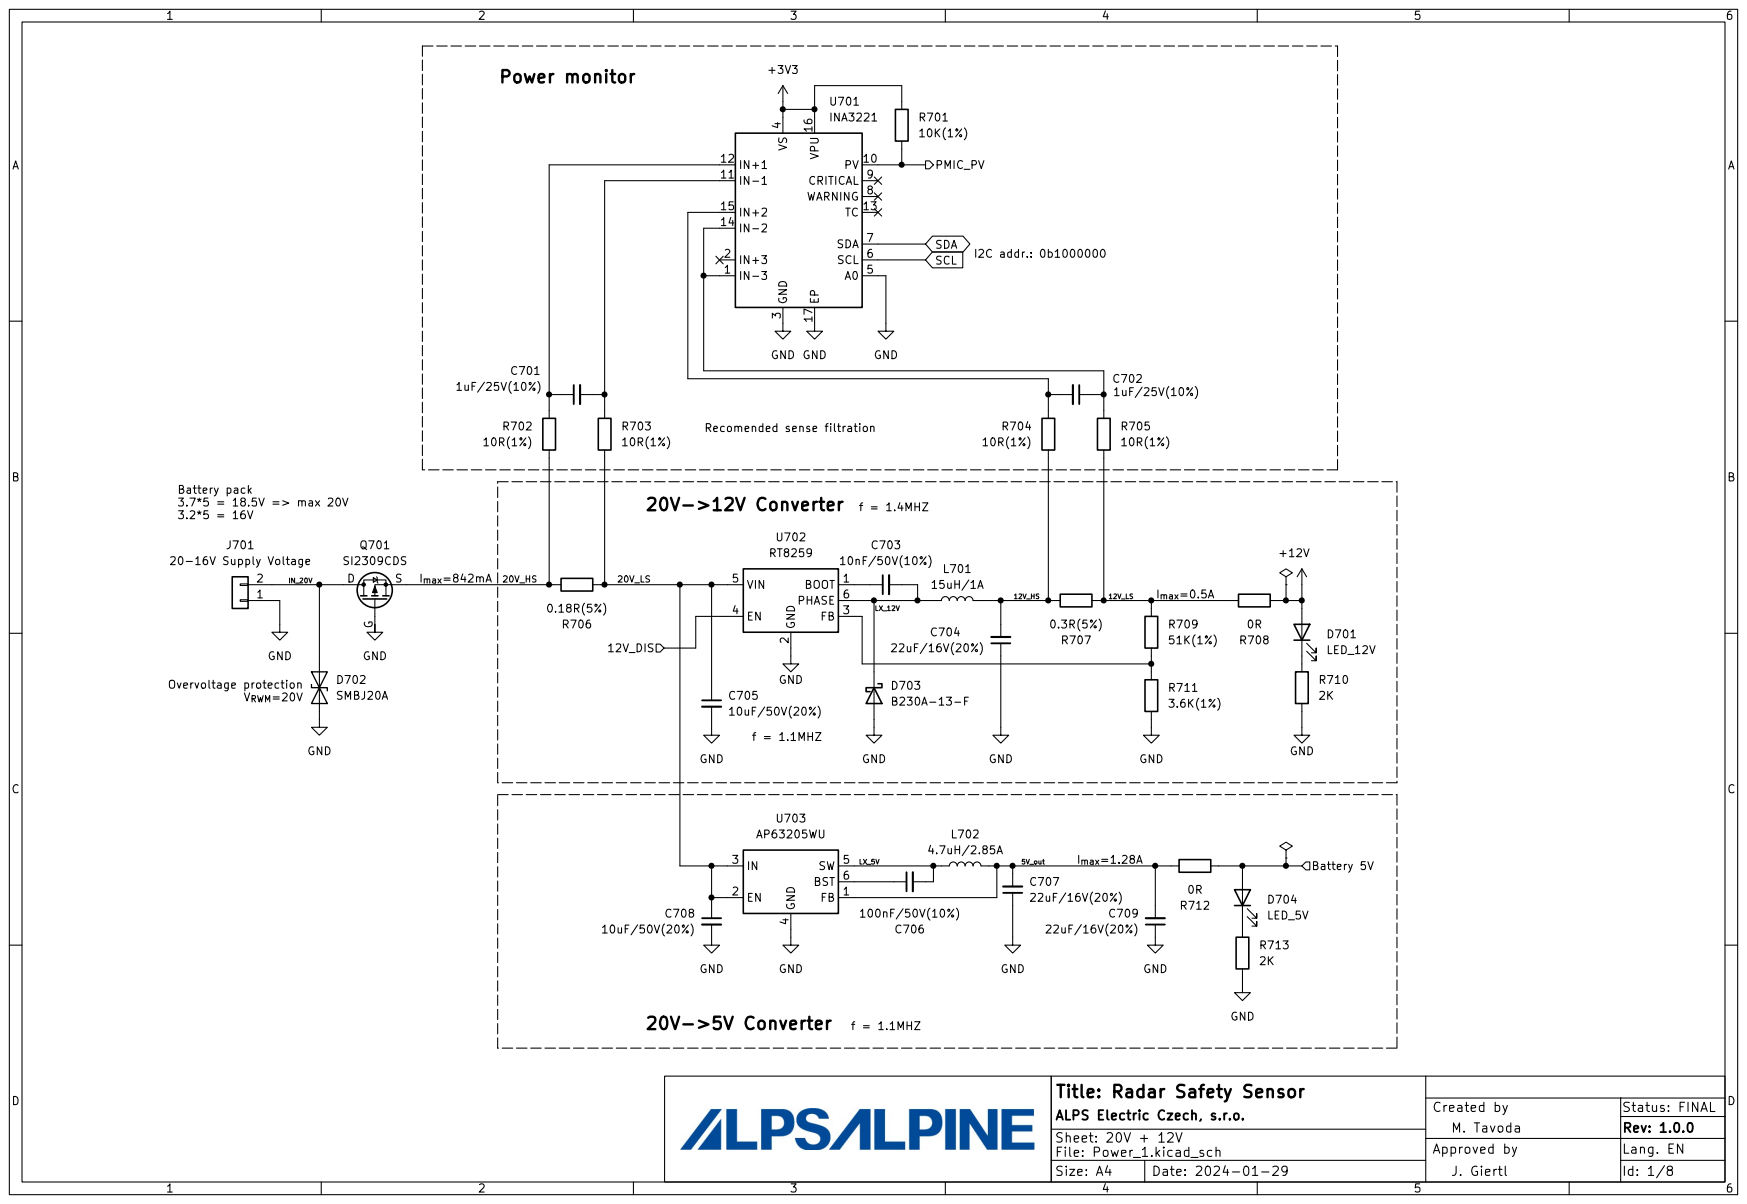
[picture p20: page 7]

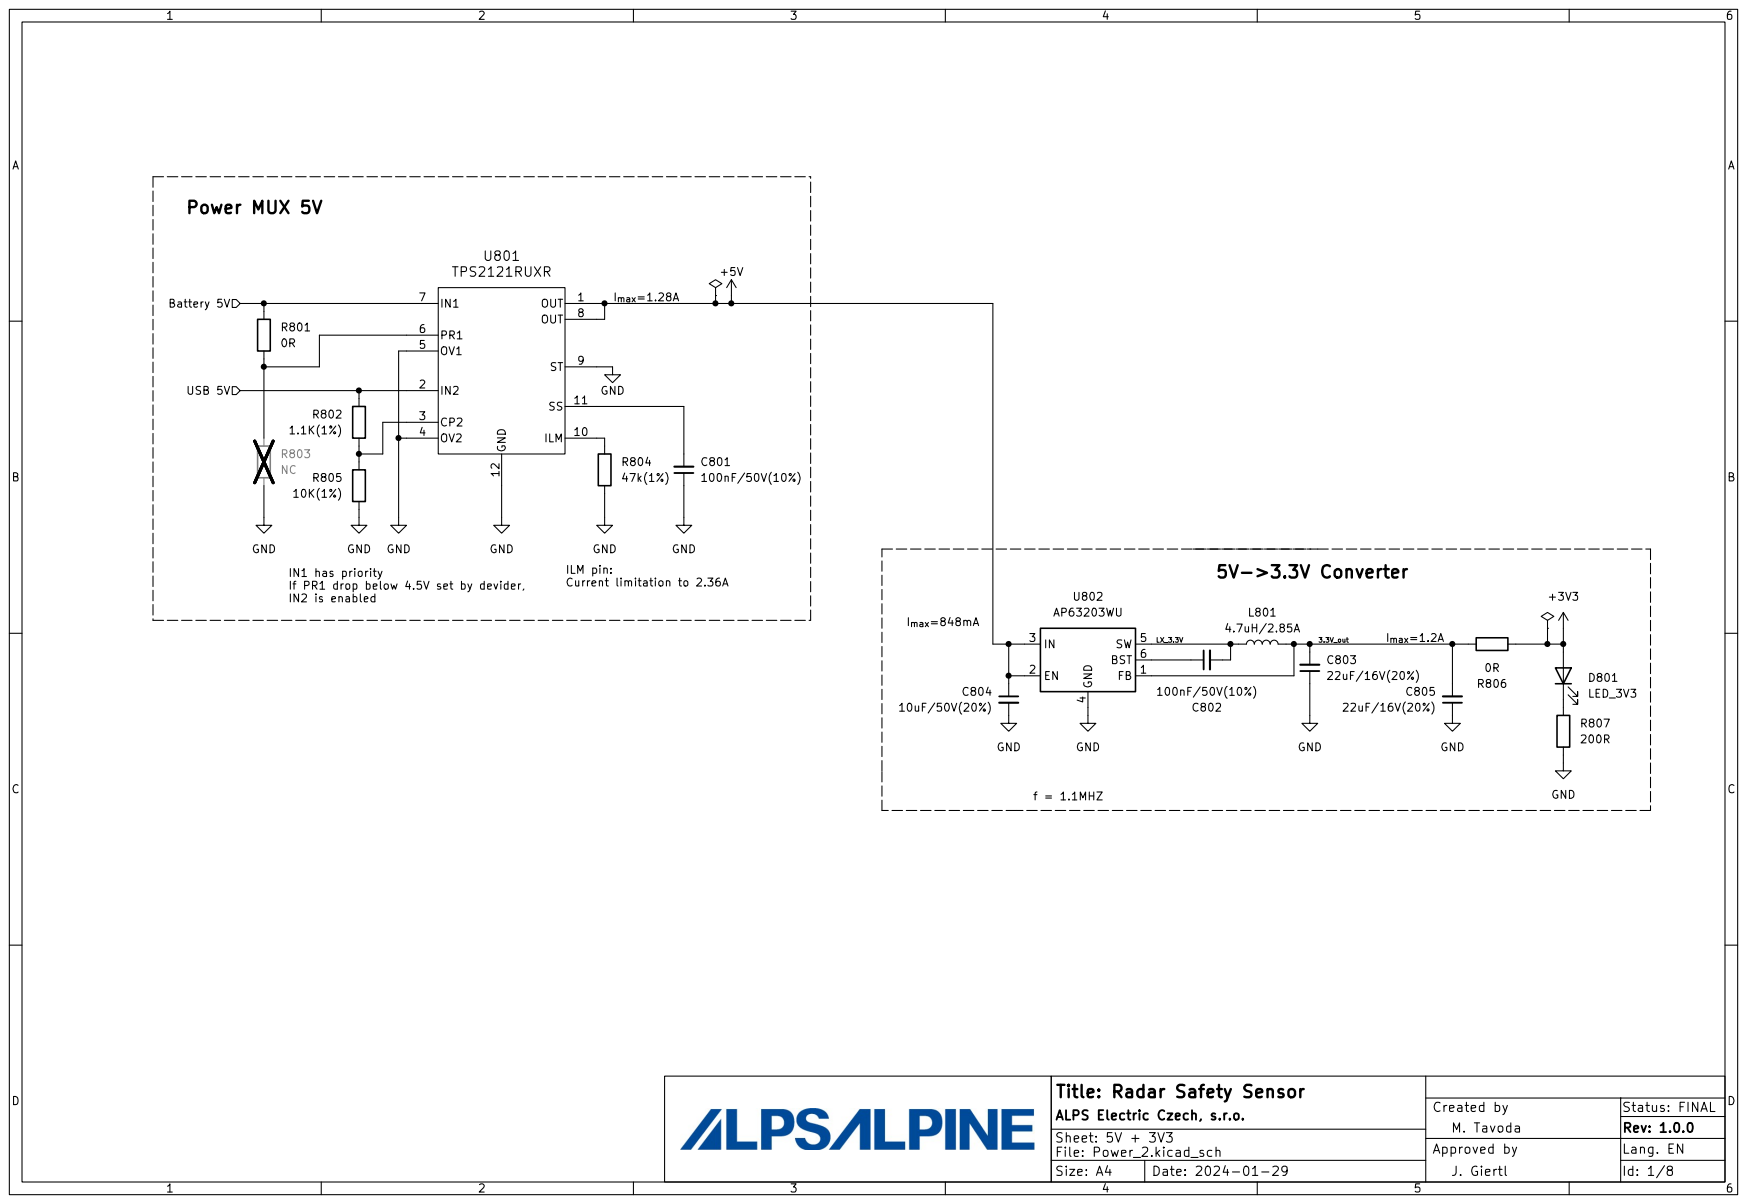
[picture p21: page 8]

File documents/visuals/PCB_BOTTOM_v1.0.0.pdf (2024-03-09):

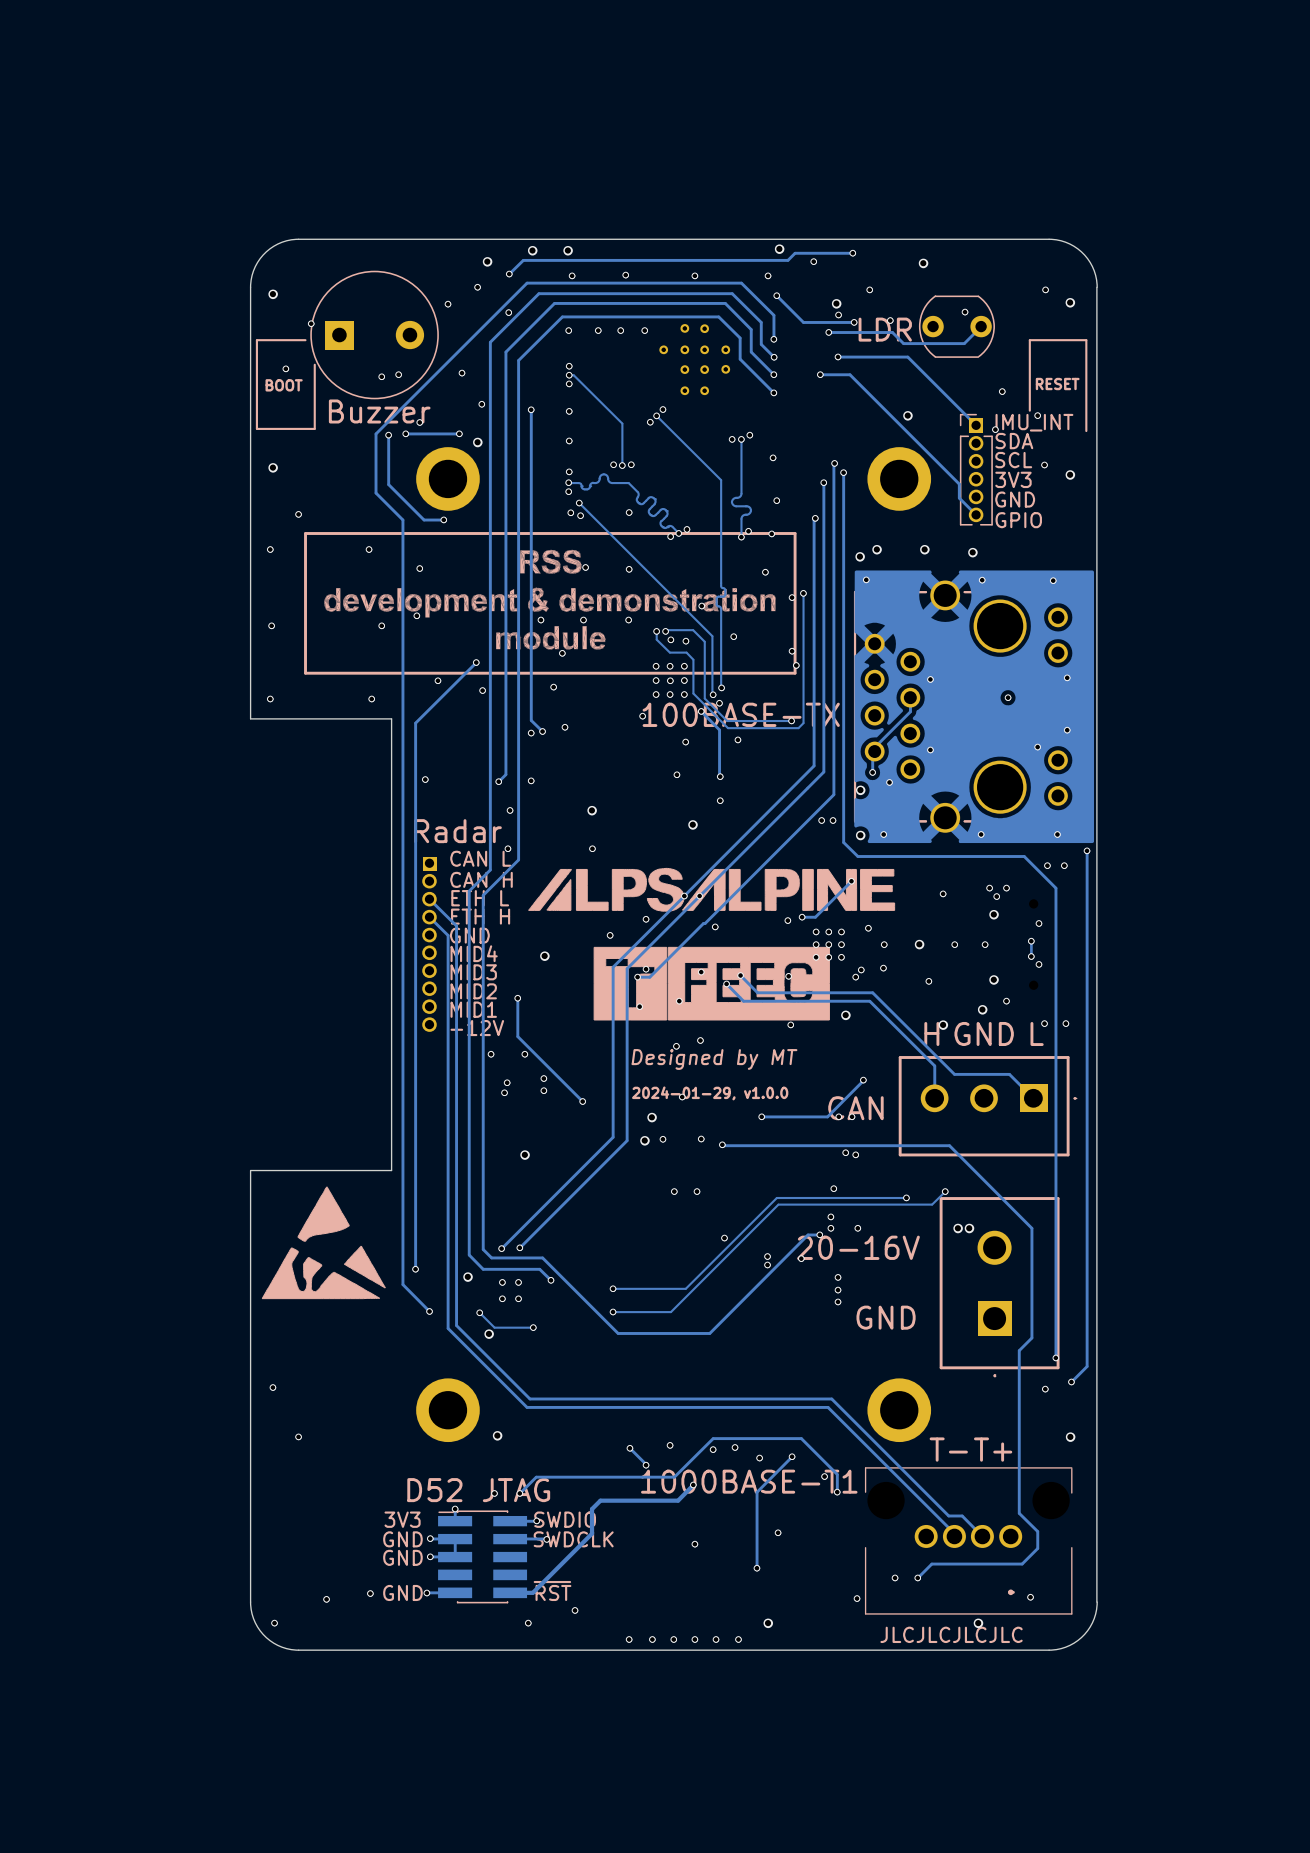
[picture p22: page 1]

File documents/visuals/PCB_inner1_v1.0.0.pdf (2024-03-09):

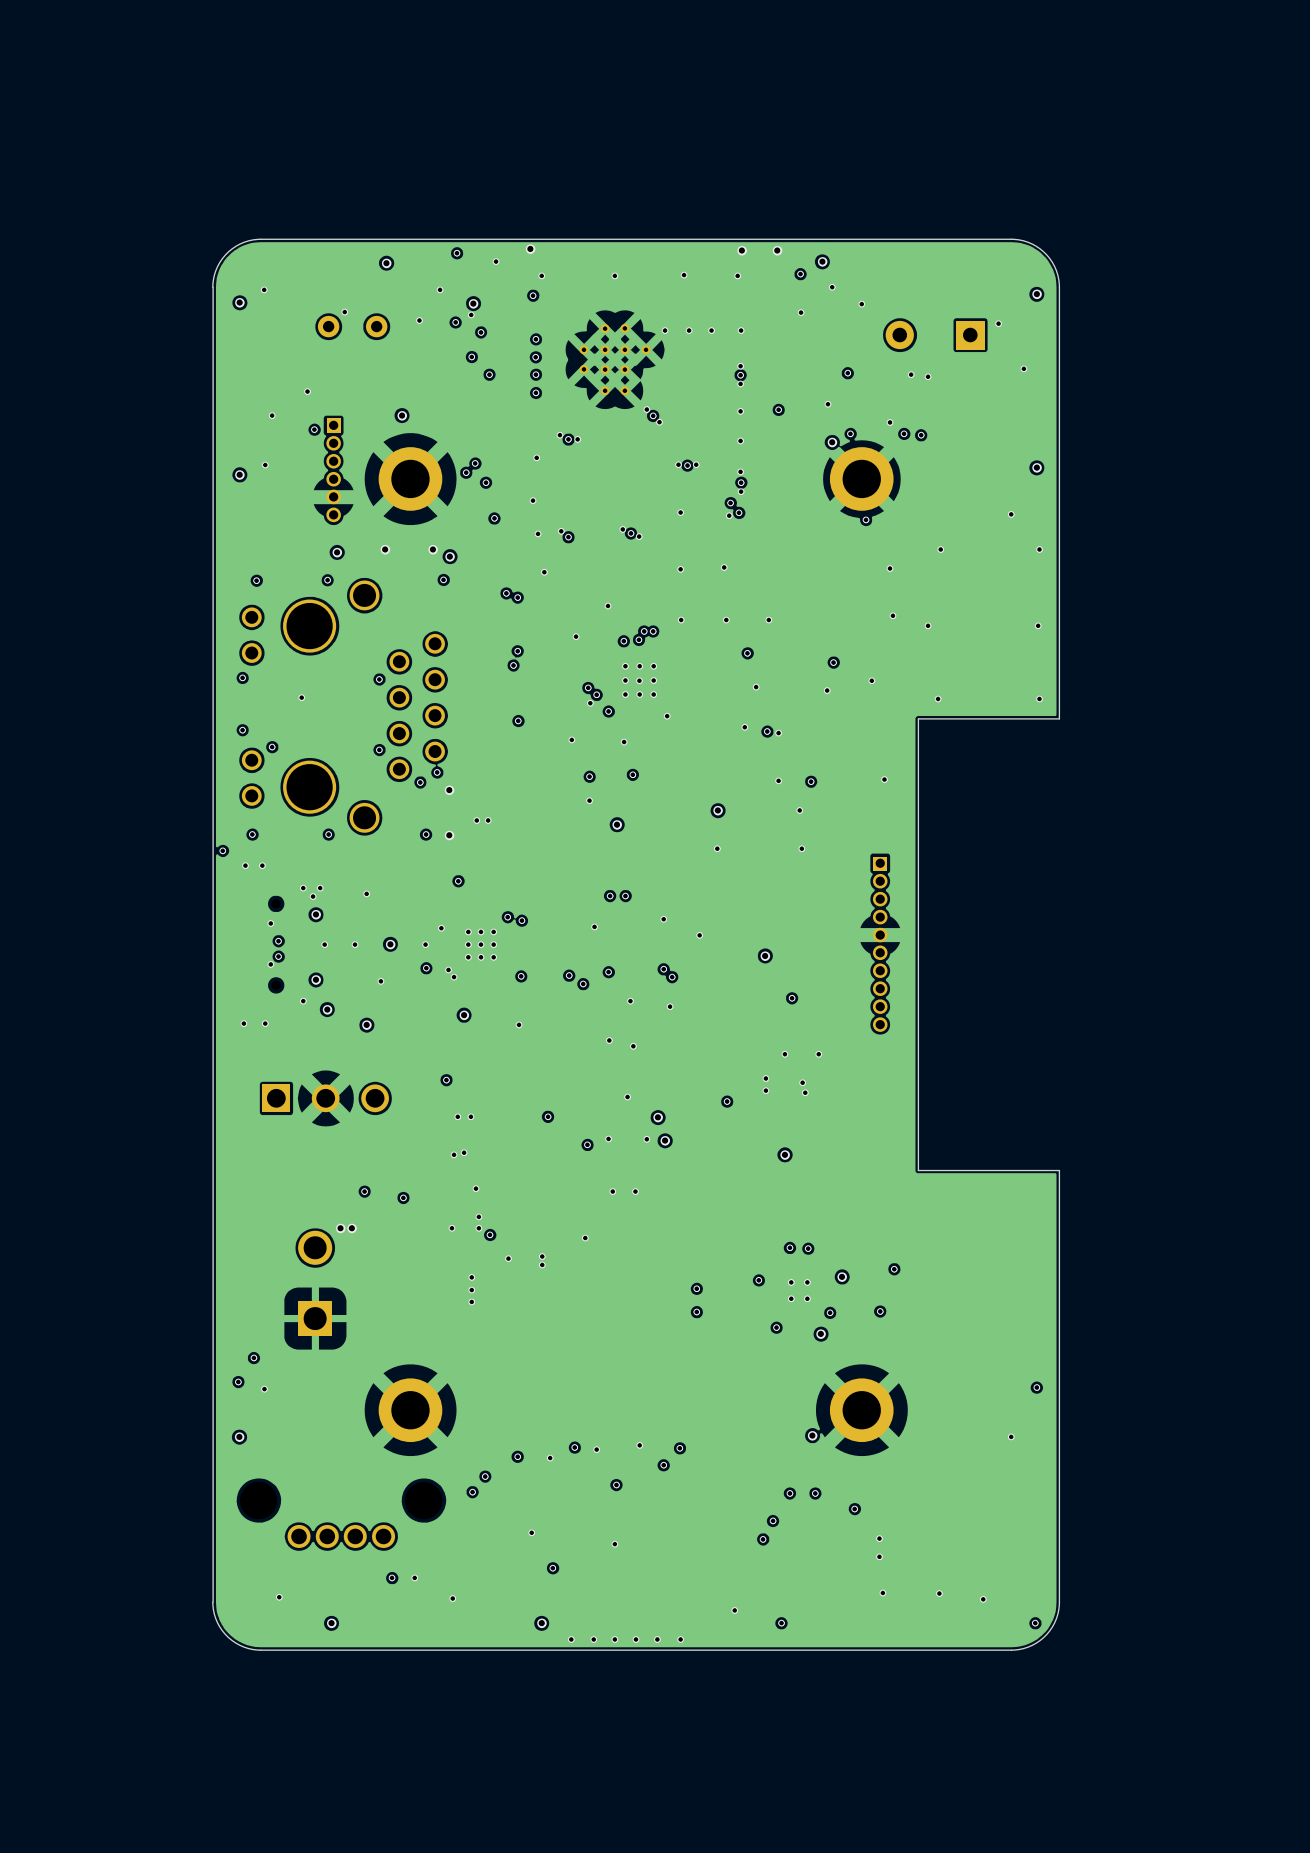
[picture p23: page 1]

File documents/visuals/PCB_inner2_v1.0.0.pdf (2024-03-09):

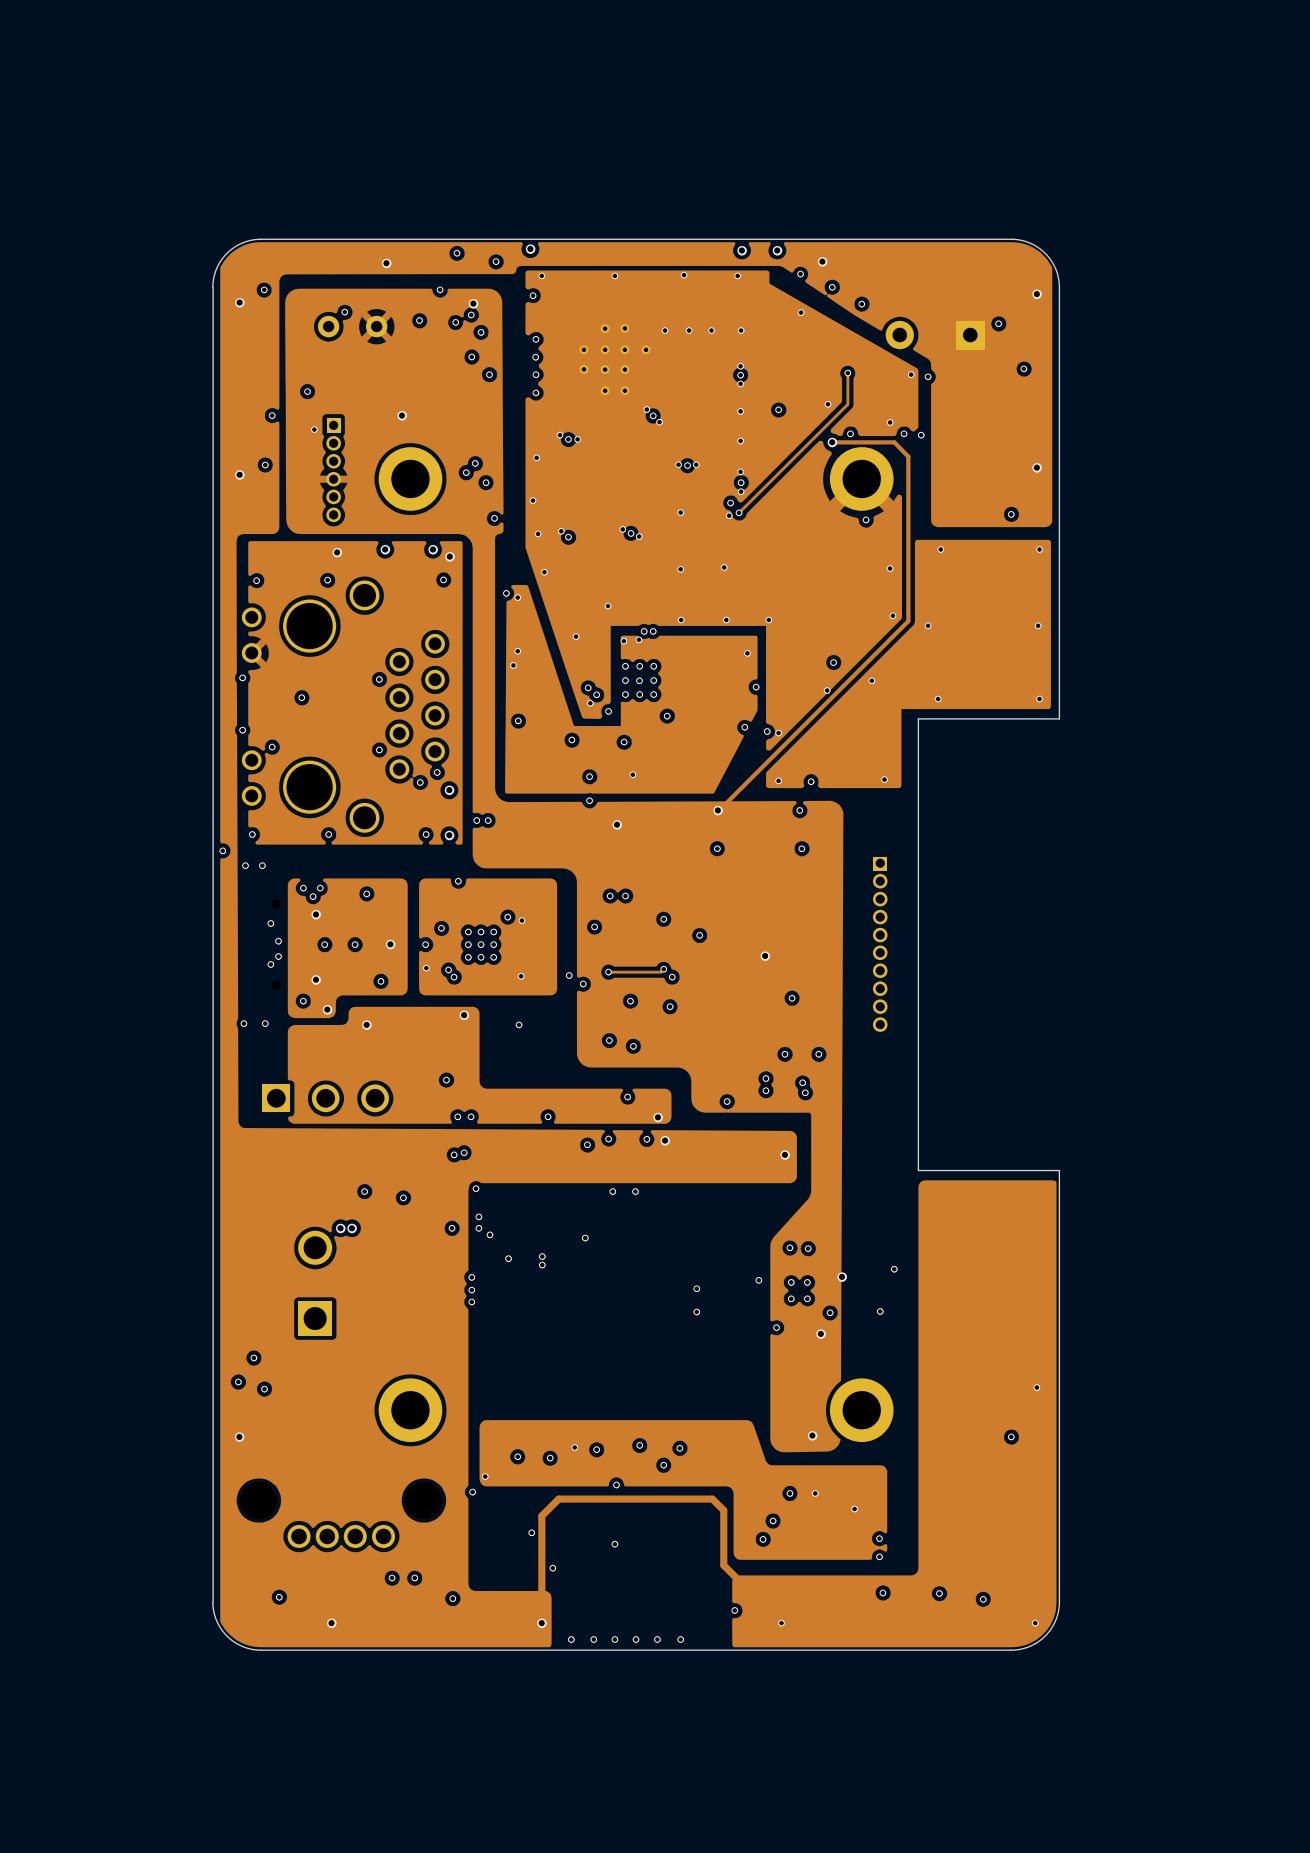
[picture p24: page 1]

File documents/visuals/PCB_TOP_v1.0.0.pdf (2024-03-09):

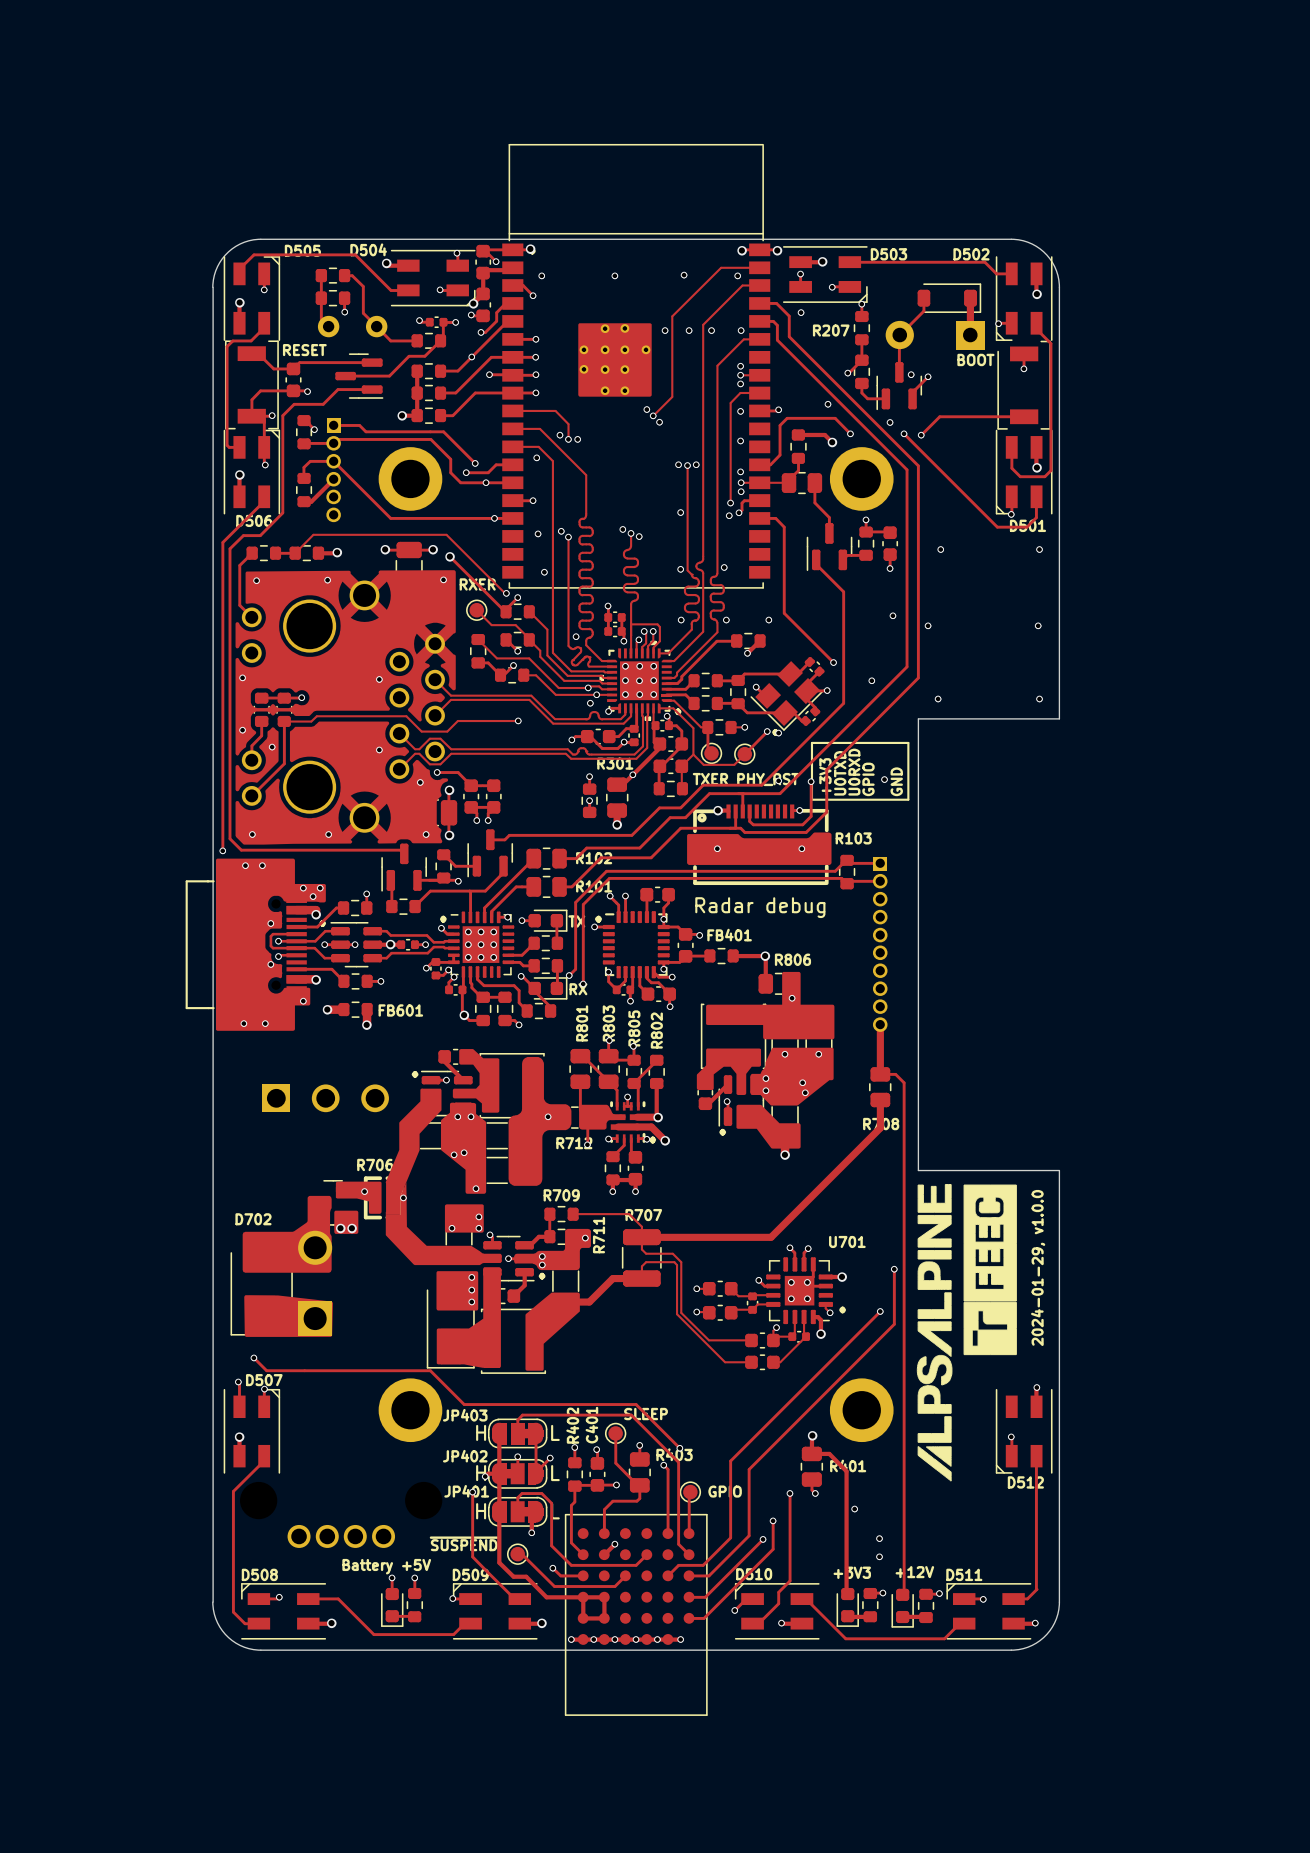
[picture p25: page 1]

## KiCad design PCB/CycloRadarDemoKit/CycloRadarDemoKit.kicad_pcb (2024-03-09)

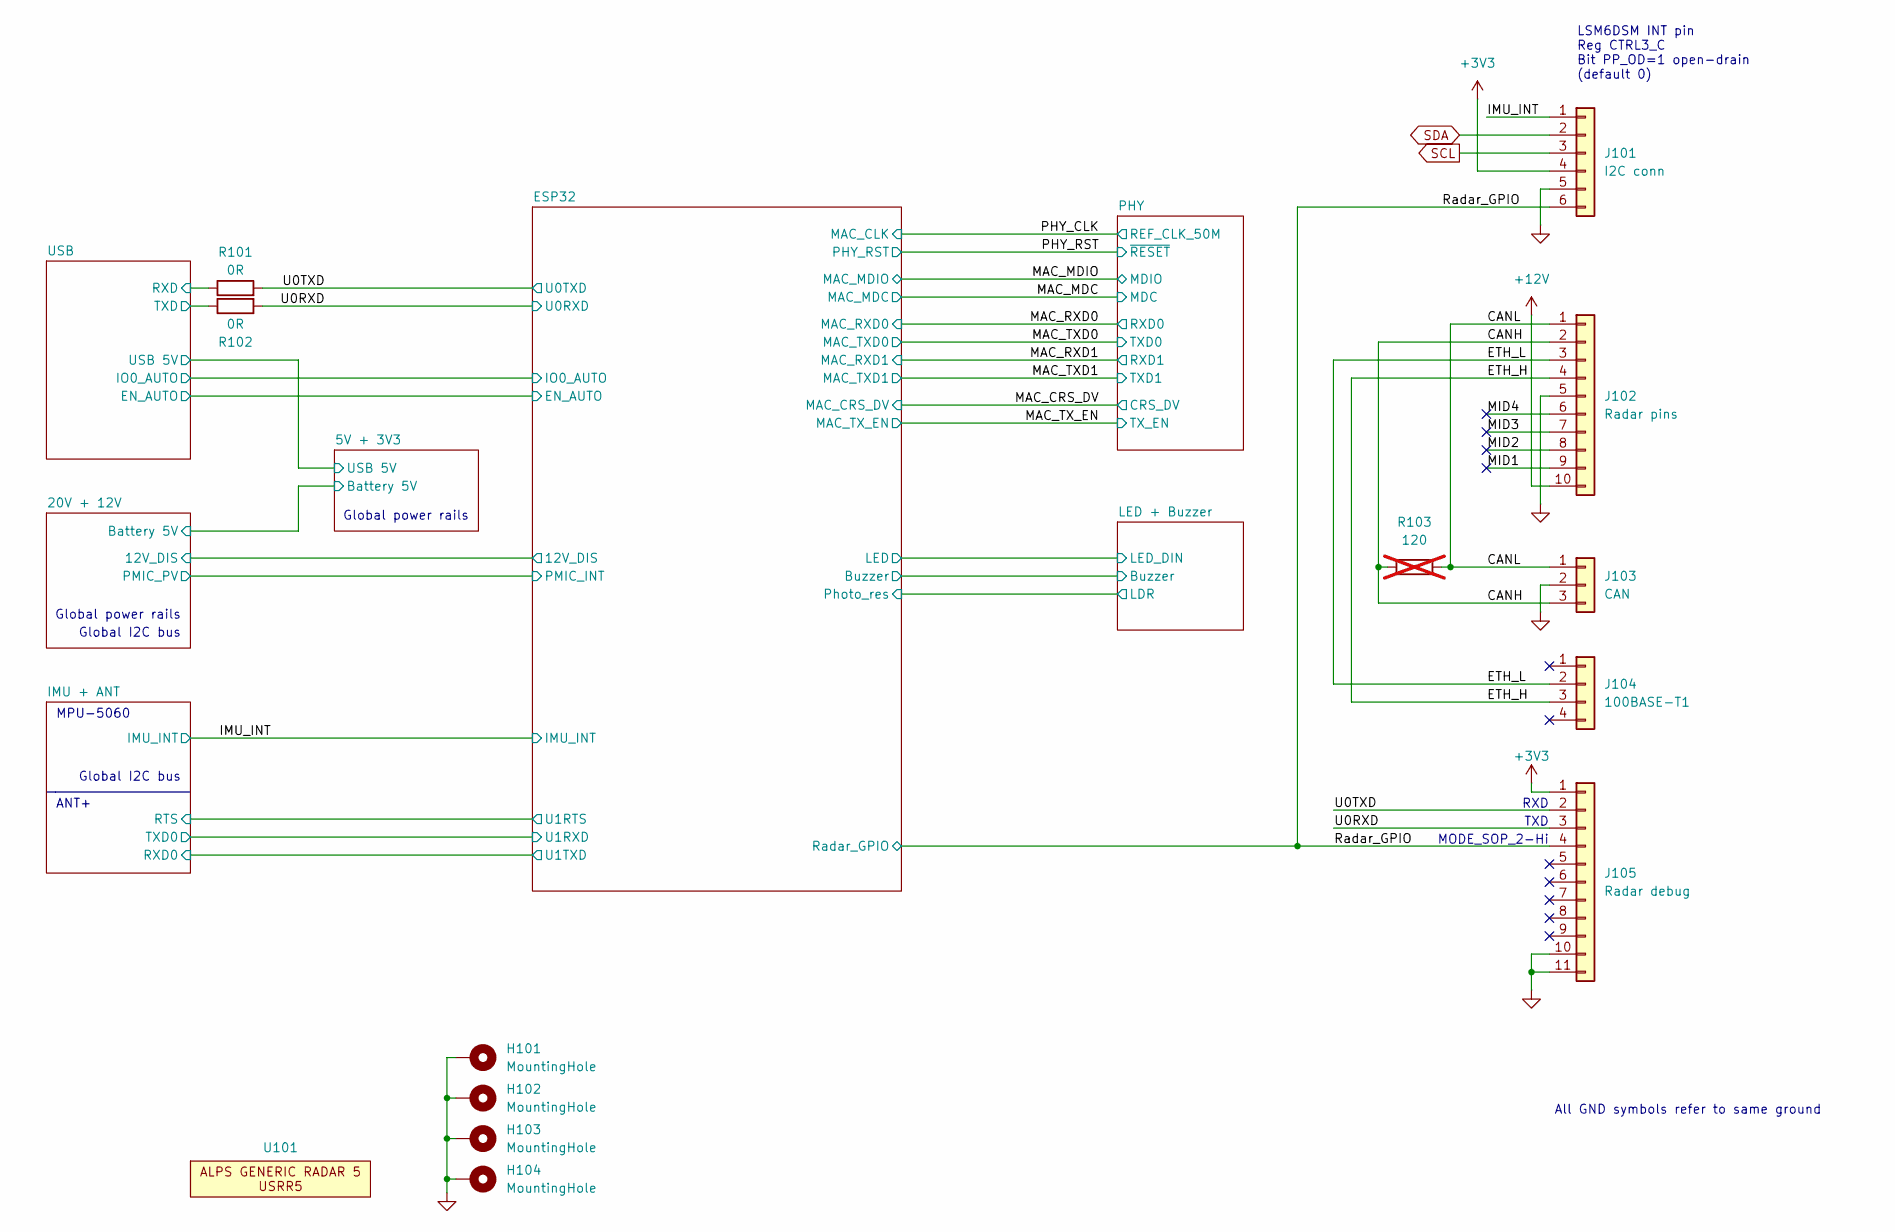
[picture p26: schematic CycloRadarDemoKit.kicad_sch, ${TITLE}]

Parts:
H101, H102, H103, H104: MountingHole; MountingHole_2.7mm_M2.5_ISO7380_Pad
J101: I2C conn; PinHeader_1x06_P1.27mm_Vertical
J102: Radar pins; PinHeader_1x10_P1.27mm_Vertical
J103: CAN; Molex_39501-1003; Mouser 538-39501-1003
J104: 100BASE-T1; Molex_347920040; Mouser 538-34792-0040
J105: Radar debug; AFC30-S10FCC-00; LCSC C395235
R101, R102: 0R; R_0805_2012Metric; LCSC C17477
R103: 120; R_0603_1608Metric; not fitted
U101: ALPS_USRR5_woPins

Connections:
+3V3: J101.4, J105.1; also elsewhere on the board
+12V: J102.10; also elsewhere on the board
/CANH: J102.2, J103.3, R103.1
/CANL: J102.1, J103.1, R103.2
/ETH_H: J102.4, J104.3
/ETH_L: J102.3, J104.2
/IMU_INT: J101.1; also elsewhere on the board
/MID1: J102.9
/MID2: J102.8
/MID3: J102.7
/MID4: J102.6
/Radar_GPIO: J101.6, J105.4; also elsewhere on the board
/U0RXD: J105.3, R102.2; also elsewhere on the board
/U0TXD: J105.2, R101.2; also elsewhere on the board
/USB/RXD: R101.1; also elsewhere on the board
/USB/TXD: R102.1; also elsewhere on the board
GND: H101.1, H102.1, H103.1, H104.1, J101.5, J102.5, J103.2, J105.10, J105.11; also elsewhere on the board
SCL: J101.3; also elsewhere on the board
SDA: J101.2; also elsewhere on the board

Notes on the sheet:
RXD
MPU-5060
ANT+
Global I2C bus
LSM6DSM INT pin Reg CTRL3_C Bit PP_OD=1 open-drain (default 0)
Global power rails
TXD
MODE_SOP_2-Hi
All GND symbols refer to same ground

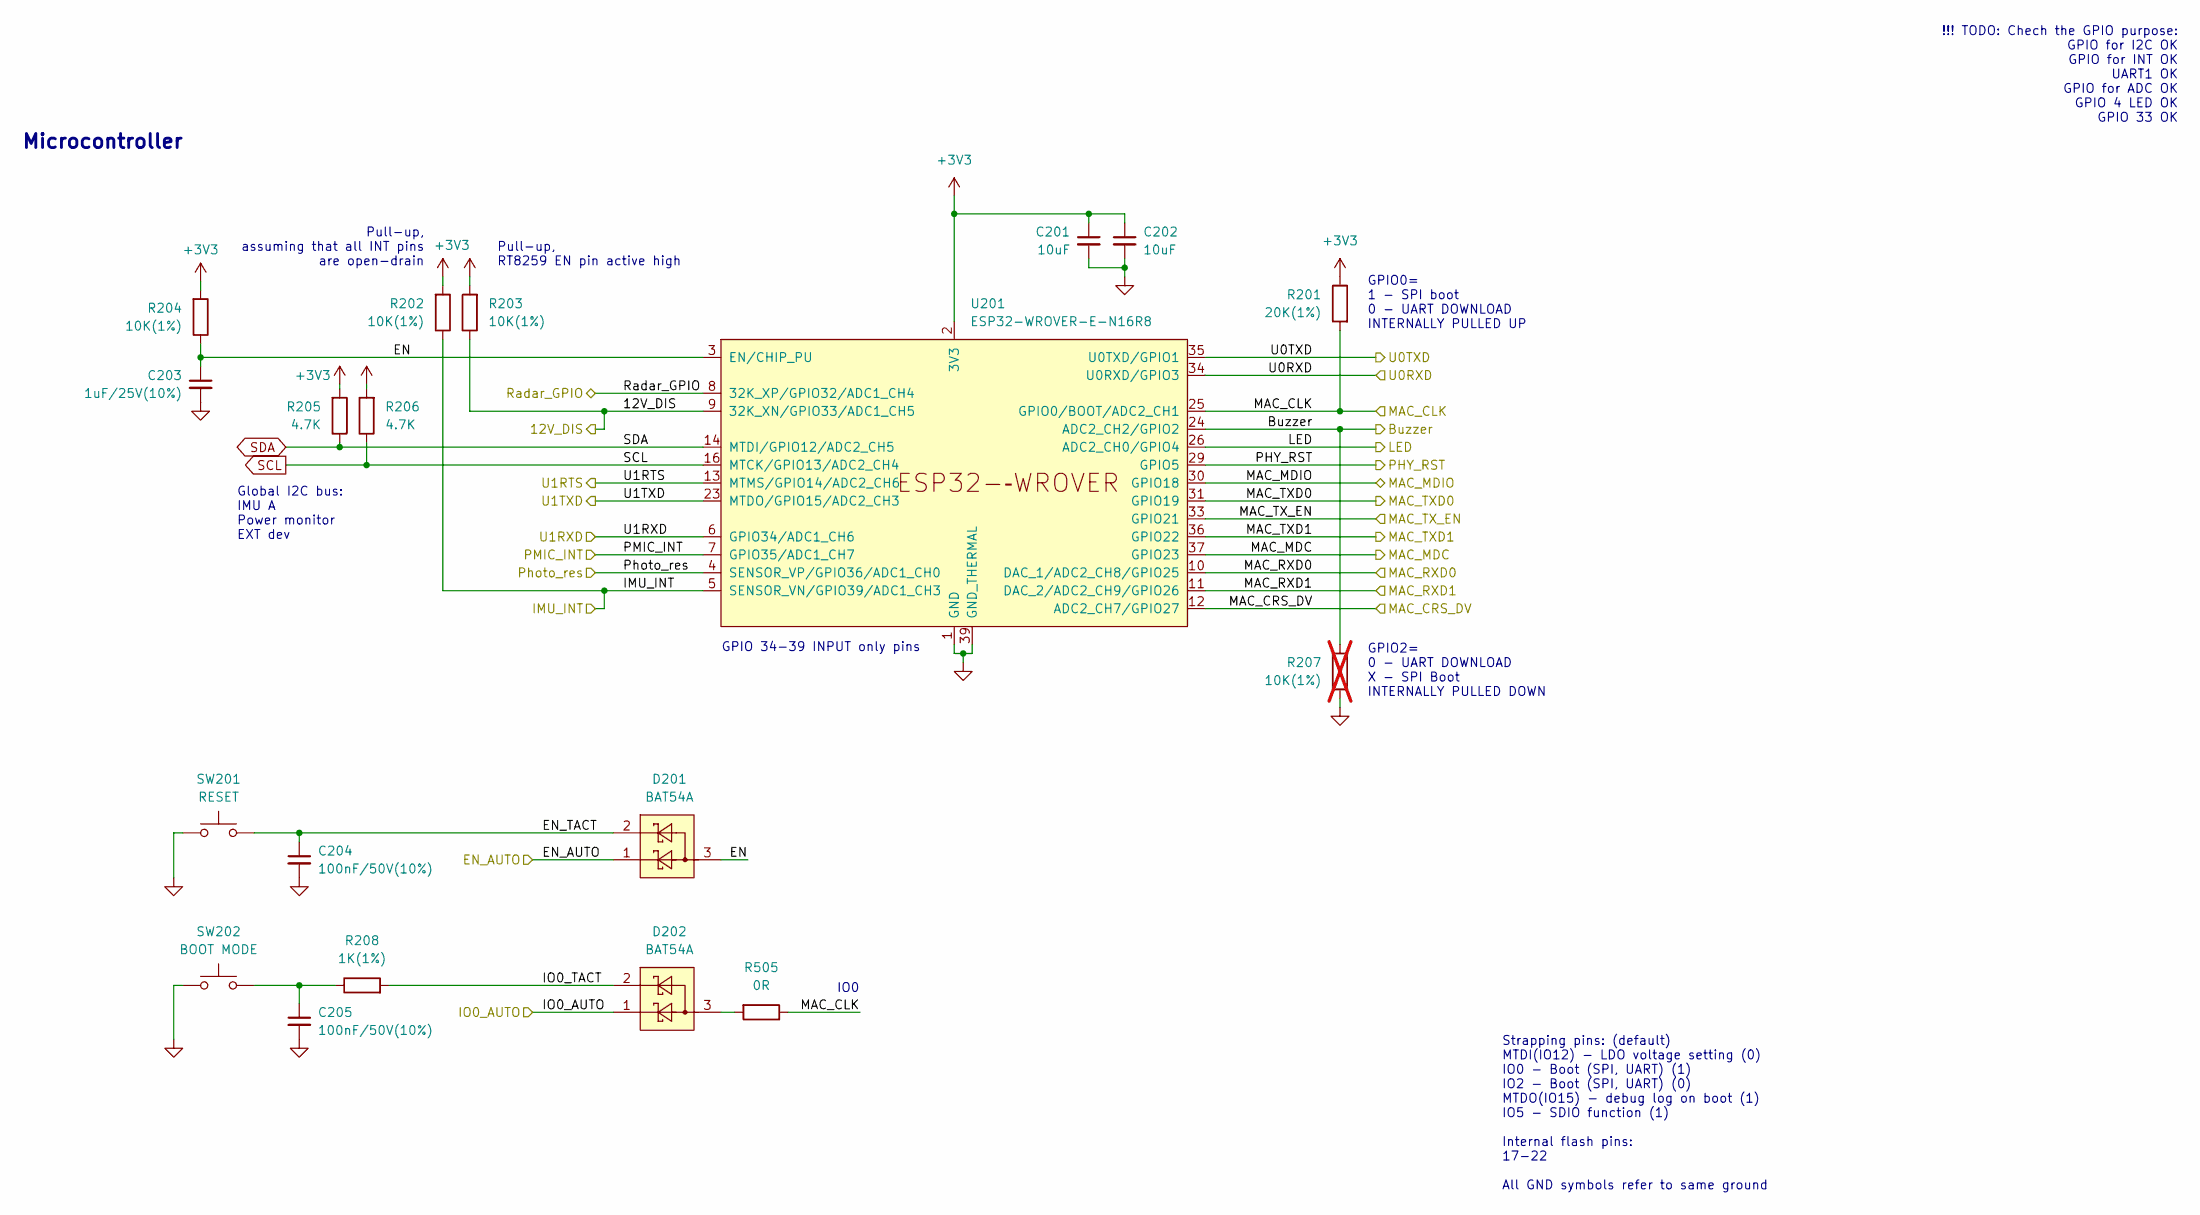
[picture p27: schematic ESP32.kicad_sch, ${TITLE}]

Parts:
C201, C202: 10uF; C_0603_1608Metric; LCSC C19702
C203: 1uF/25V(10%); C_0402_1005Metric; LCSC C52923
C204, C205: 100nF/50V(10%); C_0603_1608Metric; LCSC C14663
D201, D202: BAT54A; SOT-23; LCSC C283256
R201: 20K(1%); R_0603_1608Metric; LCSC C4184
R202, R203, R204: 10K(1%); R_0603_1608Metric; LCSC C25804
R205, R206: 4.7K; R_0603_1608Metric; LCSC C23162
R207: 10K(1%); R_0603_1608Metric; not fitted
R208: 1K(1%); R_0603_1608Metric; LCSC C21190
R505: 0R; R_0805_2012Metric; LCSC C17477
SW201: RESET; SW_SPST_TS-1088R; LCSC C455280
SW202: BOOT MODE; SW_SPST_TS-1088R; LCSC C455280
U201: ESP32-WROVER-E-N16R8; ESP32-WROVER-E_ThermalVias; LCSC C529589

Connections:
+3V3: C201.1, C202.1, R201.1, R202.2, R203.2, R204.2, R205.2, R206.2, U201.2 (3V3); also elsewhere on the board
/ESP32/12V_DIS: R203.1, U201.9 (32K_XN/GPIO33/ADC1_CH5); also elsewhere on the board
/ESP32/Buzzer: R207.1, U201.24 (ADC2_CH2/GPIO2); also elsewhere on the board
/ESP32/EN: C203.1, D201.3, R204.1, U201.3 (EN/CHIP_PU)
/ESP32/EN_AUTO: D201.1; also elsewhere on the board
/ESP32/EN_TACT: C204.1, D201.2, SW201.2
/ESP32/IO0_AUTO: D202.1; also elsewhere on the board
/ESP32/IO0_TACT: D202.2, R208.2
/ESP32/LED: U201.26 (ADC2_CH0/GPIO4); also elsewhere on the board
/ESP32/PMIC_INT: U201.7 (GPIO35/ADC1_CH7); also elsewhere on the board
/ESP32/Photo_res: U201.4 (SENSOR_VP/GPIO36/ADC1_CH0); also elsewhere on the board
/ESP32/U1RTS: U201.13 (MTMS/GPIO14/ADC2_CH6); also elsewhere on the board
/ESP32/U1RXD: U201.6 (GPIO34/ADC1_CH6); also elsewhere on the board
/ESP32/U1TXD: U201.23 (MTDO/GPIO15/ADC2_CH3); also elsewhere on the board
/IMU_INT: R202.1, U201.5 (SENSOR_VN/GPIO39/ADC1_CH3); also elsewhere on the board
/MAC_CRS_DV: U201.12 (ADC2_CH7/GPIO27); also elsewhere on the board
/MAC_MDC: U201.37 (GPIO23); also elsewhere on the board
/MAC_MDIO: U201.30 (GPIO18); also elsewhere on the board
/MAC_RXD0: U201.10 (DAC_1/ADC2_CH8/GPIO25); also elsewhere on the board
/MAC_RXD1: U201.11 (DAC_2/ADC2_CH9/GPIO26); also elsewhere on the board
/MAC_TXD0: U201.31 (GPIO19); also elsewhere on the board
/MAC_TXD1: U201.36 (GPIO22); also elsewhere on the board
/MAC_TX_EN: U201.33 (GPIO21); also elsewhere on the board
/PHY_CLK: R201.2, R505.1, U201.25 (GPIO0/BOOT/ADC2_CH1); also elsewhere on the board
/PHY_RST: U201.29 (GPIO5); also elsewhere on the board
/Radar_GPIO: U201.8 (32K_XP/GPIO32/ADC1_CH4); also elsewhere on the board
/U0RXD: U201.34 (U0RXD/GPIO3); also elsewhere on the board
/U0TXD: U201.35 (U0TXD/GPIO1); also elsewhere on the board
GND: C201.2, C202.2, C203.2, C204.2, C205.2, R207.2, SW201.1, SW202.1, U201.1 (GND), U201.15 (GND), U201.38 (GND), U201.39 (GND_THERMAL); also elsewhere on the board
unnamed: C205.1, R208.1, SW202.2
unnamed: D202.3, R505.2
SCL: R206.1, U201.16 (MTCK/GPIO13/ADC2_CH4); also elsewhere on the board
SDA: R205.1, U201.14 (MTDI/GPIO12/ADC2_CH5); also elsewhere on the board

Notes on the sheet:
GPIO2= 0 - UART DOWNLOAD X - SPI Boot INTERNALLY PULLED DOWN
Microcontroller
!!! TODO: Chech the GPIO purpose: GPIO for I2C OK GPIO for INT OK UART1 OK GPIO for ADC OK GPIO 4 LED OK GPIO 33 OK
Pull-up, RT8259 EN pin active high
GPIO0= 1 - SPI boot 0 - UART DOWNLOAD INTERNALLY PULLED UP
GPIO 34-39 INPUT only pins
Global I2C bus: IMU A Power monitor EXT dev
IO0
Strapping pins: (default) MTDI(IO12) - LDO voltage setting (0) IO0 - Boot (SPI, UART) (1) IO2 - Boot (SPI, UART) (0) MTDO(IO15) - debug log on boot (1) IO5 - SDIO function (1) Internal flash pins: 17-22 All GND symbols refer to same ground
Pull-up, assuming that all INT pins are open-drain

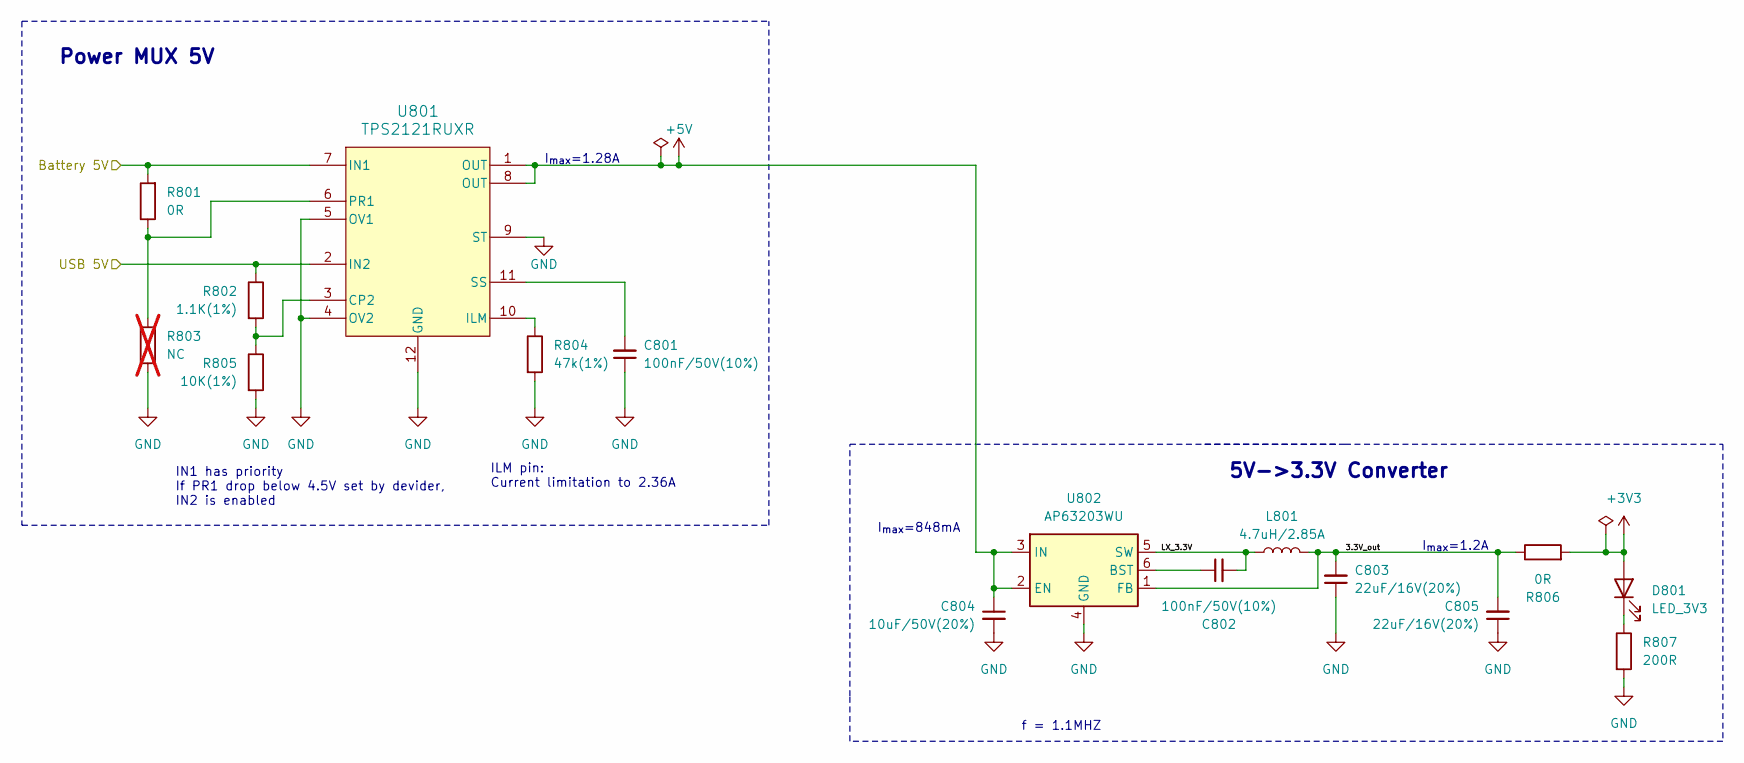
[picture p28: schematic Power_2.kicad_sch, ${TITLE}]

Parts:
C801, C802: 100nF/50V(10%); C_0603_1608Metric; LCSC C14663
C803, C805: 22uF/16V(20%); C_1206_3216Metric; LCSC C12891
C804: 10uF/50V(20%); C_1206_3216Metric; LCSC C13585
D801: LED_3V3; LED_0603_1608Metric; LCSC C497937
L801: 4.7uH/2.85A; L_Sunlord_SWPA4020S; LCSC C98363
R801, R806: 0R; R_0805_2012Metric; LCSC C17477
R802: 1.1K(1%); R_0603_1608Metric; LCSC C22764
R803: NC; R_0805_2012Metric; not fitted
R804: 47k(1%); R_0603_1608Metric; LCSC C25819
R805: 10K(1%); R_0603_1608Metric; LCSC C25804
R807: 200R; R_0603_1608Metric; LCSC C8218
U801: TPS2121RUXR; TPS2121; LCSC C485916
U802: AP63203WU; TSOT-23-6; LCSC C780769

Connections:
+3V3: D801.2 (A), R806.2; also elsewhere on the board
+5V: C804.1, U801.1 (OUT), U801.8 (OUT), U802.2 (EN), U802.3 (IN); also elsewhere on the board
/5V + 3V3/3.3V_out: C803.2, C805.2, L801.2, R806.1, U802.1 (FB)
/5V + 3V3/LX_3.3V: C802.2, L801.1, U802.5 (SW)
/5V + 3V3/USB 5V: R802.1, U801.2 (IN2); also elsewhere on the board
/20V + 12V/Battery 5V: R801.2, U801.7 (IN1); also elsewhere on the board
GND: C801.1, C803.1, C804.2, C805.1, R803.1, R804.2, R805.2, R807.2, U801.4 (OV2), U801.5 (OV1), U801.9 (ST), U801.12 (GND), U802.4 (GND); also elsewhere on the board
unnamed: D801.1 (K), R807.1
unnamed: R802.2, R805.1, U801.3 (CP2)
unnamed: R804.1, U801.10 (ILM)
unnamed: R801.1, R803.2, U801.6 (PR1)
unnamed: C801.2, U801.11 (SS)
unnamed: C802.1, U802.6 (BST)

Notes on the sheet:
ILM pin: Current limitation to 2.36A
IN1 has priority If PR1 drop below 4.5V set by devider, IN2 is enabled
I_{max}=1.2A
I_{max}=848mA
5V->3.3V Converter
I_{max}=1.28A
Power MUX 5V
f = 1.1MHZ

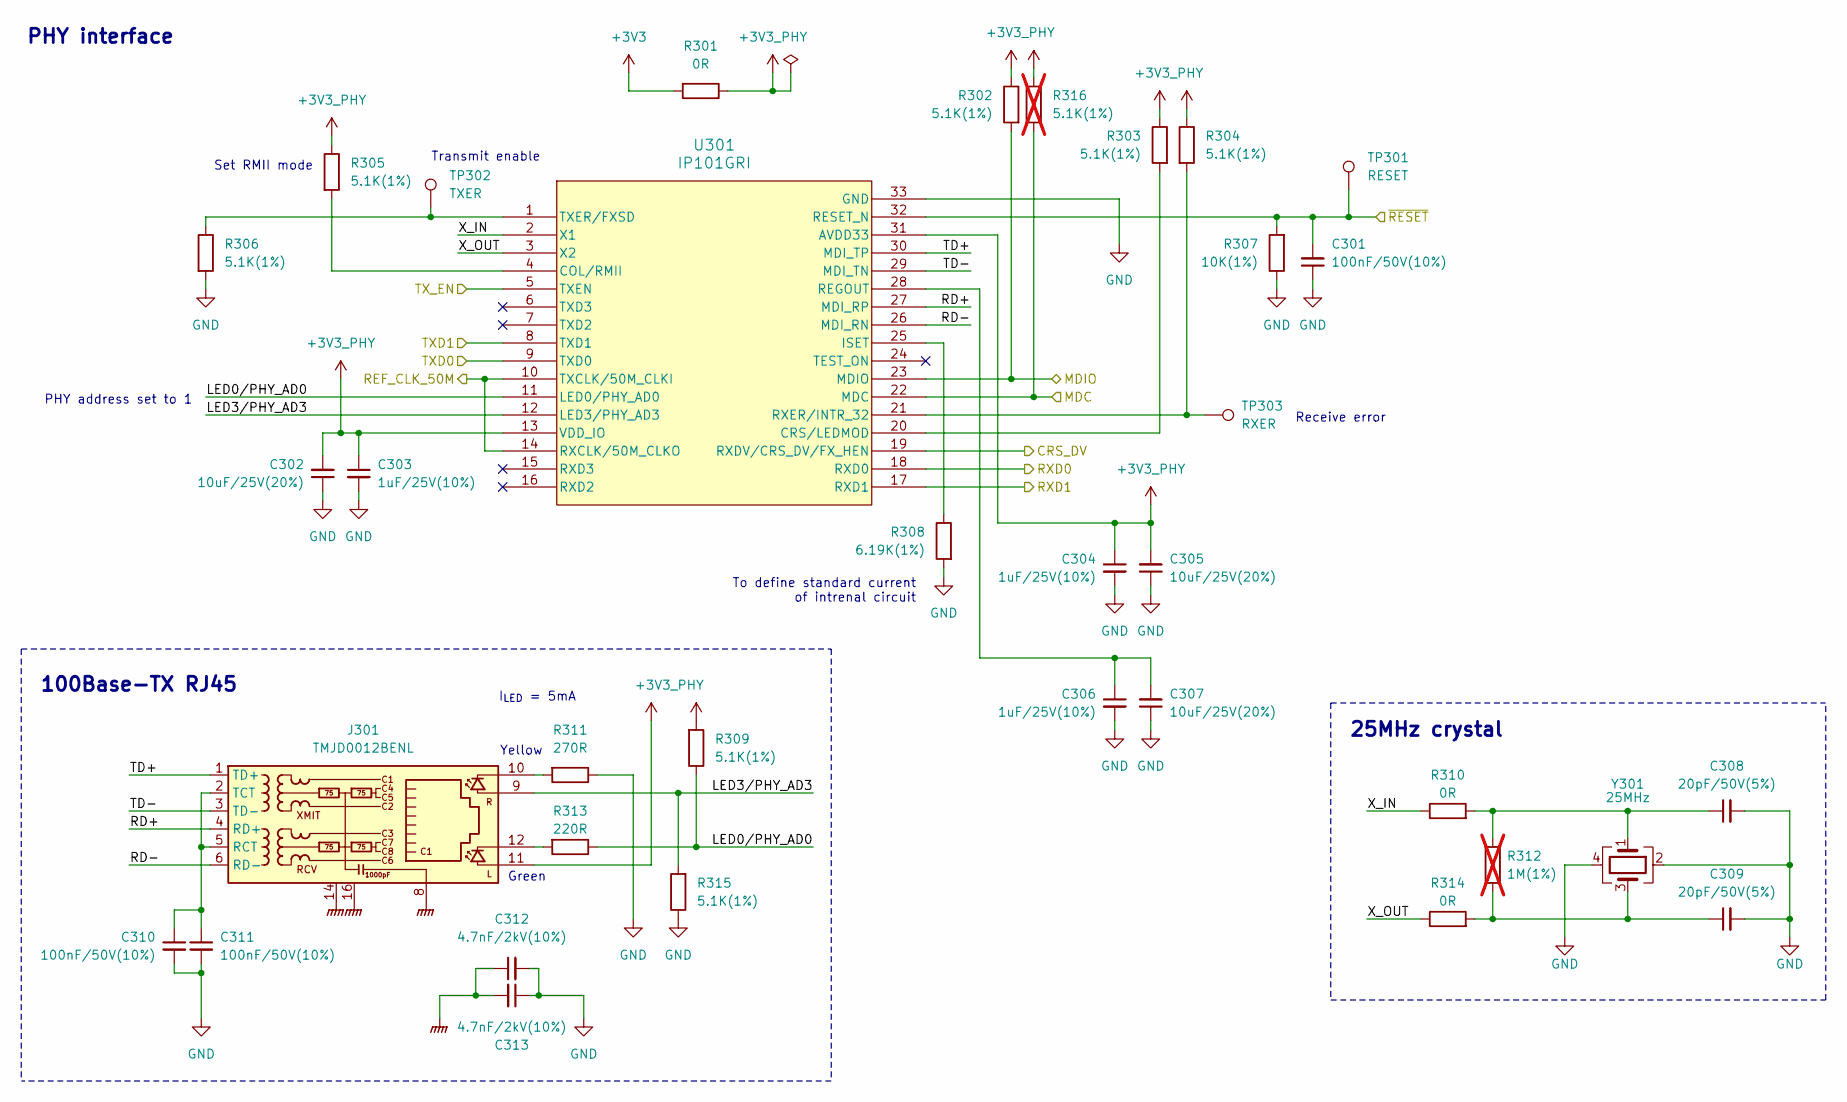
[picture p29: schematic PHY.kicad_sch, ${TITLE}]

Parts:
C301, C310, C311: 100nF/50V(10%); C_0603_1608Metric; LCSC C14663
C302: 10uF/25V(20%); C_0402_1005Metric; LCSC C15525
C303, C304, C306: 1uF/25V(10%); C_0402_1005Metric; LCSC C52923
C305, C307: 10uF/25V(20%); C_0603_1608Metric; LCSC C96446
C308, C309: 20pF/50V(5%); C_0402_1005Metric; LCSC C182483
C312, C313: 4.7nF/2kV(10%); C_1206_3216Metric; LCSC C41017
J301: TMJD0012BENL; RJ45_Taoglas_TMJD0012BENL; Mouser 960-TMJD0012BENL
R301: 0R; R_0805_2012Metric; LCSC C17477
R302, R303, R304, R305, R306, R309, R315: 5.1K(1%); R_0603_1608Metric; LCSC C23186
R307: 10K(1%); R_0603_1608Metric; LCSC C25804
R308: 6.19K(1%); R_0603_1608Metric; LCSC C403300
R310, R314: 0R; R_0603_1608Metric; LCSC C21189
R311: 270R; R_0603_1608Metric; LCSC C22966
R312: 1M(1%); R_0603_1608Metric; not fitted
R313: 220R; R_0603_1608Metric; LCSC C22962
R316: 5.1K(1%); R_0603_1608Metric; not fitted
TP301: RESET; TestPoint_Pad_D1.0mm
TP302: TXER; TestPoint_Pad_D1.0mm
TP303: RXER; TestPoint_Pad_D1.0mm
U301: IP101GRI; QFN_IP101GRI_WIZ; LCSC C703537
Y301: 25MHz; Crystal_SMD_3225-4Pin_3.2x2.5mm; LCSC C3003239

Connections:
+3V3: R301.2; also elsewhere on the board
+3V3_PHY: C302.2, C303.1, C304.1, C305.2, J301.11, R301.1, R302.1, R303.1, R304.1, R305.1, R309.2, R316.1, U301.13 (VDD_IO), U301.31 (AVDD33)
/MAC_CRS_DV: U301.19 (RXDV/CRS_DV/FX_HEN); also elsewhere on the board
/MAC_MDC: R316.2, U301.22 (MDC); also elsewhere on the board
/MAC_MDIO: R302.2, U301.23 (MDIO); also elsewhere on the board
/MAC_RXD0: U301.18 (RXD0); also elsewhere on the board
/MAC_RXD1: U301.17 (RXD1); also elsewhere on the board
/MAC_TXD0: U301.9 (TXD0); also elsewhere on the board
/MAC_TXD1: U301.8 (TXD1); also elsewhere on the board
/MAC_TX_EN: U301.5 (TXEN); also elsewhere on the board
/PHY/LED0/PHY_AD0: R309.1, R313.1, U301.11 (LED0/PHY_AD0)
/PHY/LED3/PHY_AD3: J301.9, R315.2, U301.12 (LED3/PHY_AD3)
/PHY/RD+: J301.4 (RD+), U301.27 (MDI_RP)
/PHY/RD-: J301.6 (RD-), U301.26 (MDI_RN)
/PHY/TD+: J301.1 (TD+), U301.30 (MDI_TP)
/PHY/TD-: J301.3 (TD-), U301.29 (MDI_TN)
/PHY/X_IN: R310.1, U301.2 (X1)
/PHY/X_OUT: R314.1, U301.3 (X2)
/PHY_CLK: U301.10 (TXCLK/50M_CLKI), U301.14 (RXCLK/50M_CLKO); also elsewhere on the board
/PHY_RST: C301.2, R307.2, TP301.1, U301.32 (RESET_N); also elsewhere on the board
GND: C301.1, C302.1, C303.2, C304.2, C305.1, C306.2, C307.1, C308.2, C309.2, C310.2, C311.2, C312.2, C313.1, R306.2, R307.1, R308.2, R311.1, R315.1, U301.33 (GND), Y301.2, Y301.4; also elsewhere on the board
GNDPWR: C312.1, C313.2, J301.8, J301.14, J301.16
unnamed: C308.1, R310.2, R312.2, Y301.1
unnamed: C309.1, R312.1, R314.2, Y301.3
unnamed: J301.10, R311.2
unnamed: J301.12, R313.2
unnamed: C310.1, C311.1, J301.2 (TCT), J301.5 (RCT)
unnamed: R305.2, U301.4 (COL/RMII)
unnamed: R303.2, U301.20 (CRS/LEDMOD)
unnamed: R308.1, U301.25 (ISET)
unnamed: C306.1, C307.2, U301.28 (REGOUT)
unnamed: R304.2, TP303.1, U301.21 (RXER/INTR_32)
unnamed: R306.1, TP302.1, U301.1 (TXER/FXSD)

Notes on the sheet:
Green
100Base-TX RJ45
I_{LED} = 5mA
25MHz crystal
PHY interface
Receive error
Set RMII mode
Yellow
Transmit enable
PHY address set to 1
To define standard current of intrenal circuit

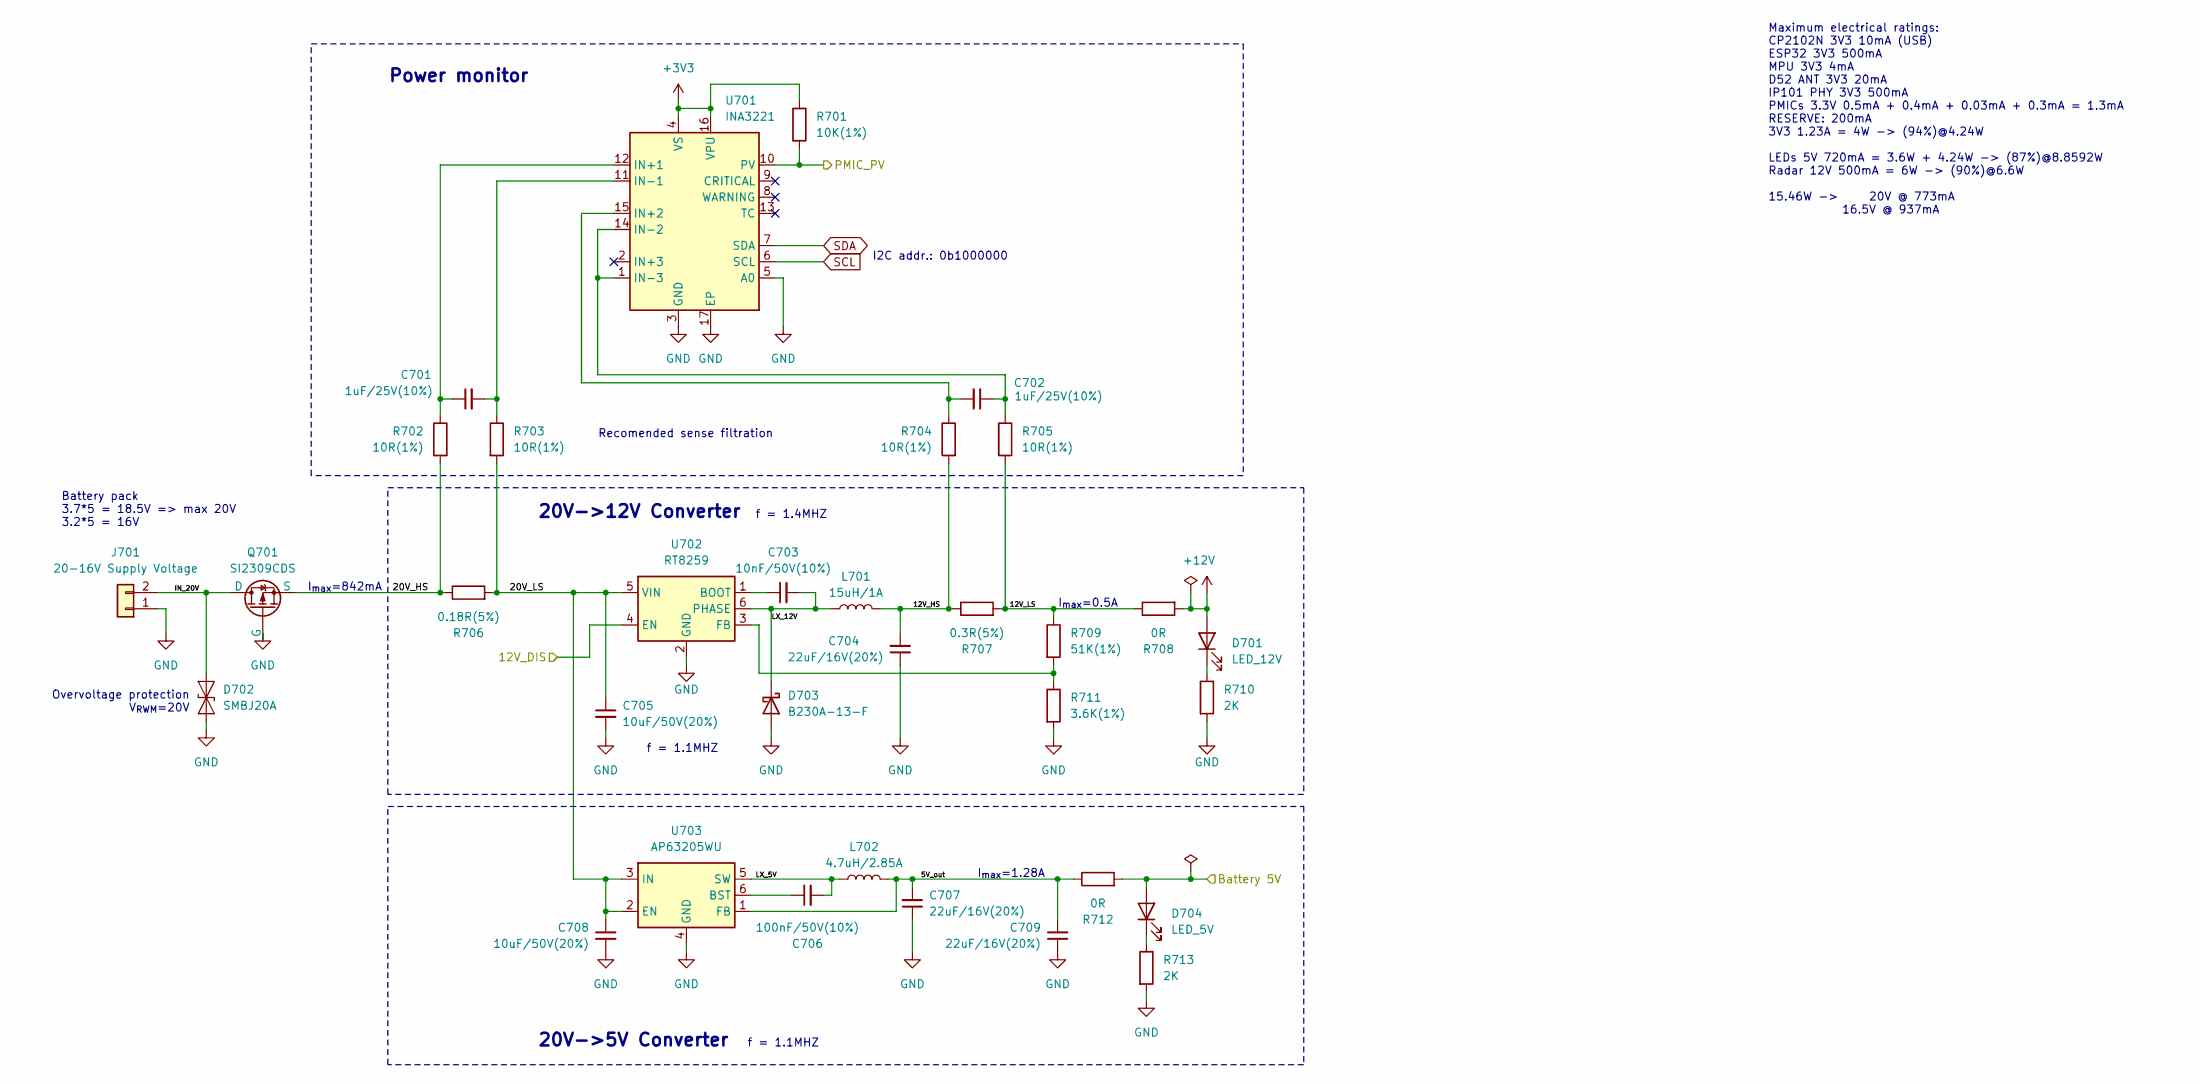
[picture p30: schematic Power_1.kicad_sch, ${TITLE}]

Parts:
C701, C702: 1uF/25V(10%); C_0402_1005Metric; LCSC C52923
C703: 10nF/50V(10%); C_0603_1608Metric; LCSC C57112
C704, C707, C709: 22uF/16V(20%); C_1206_3216Metric; LCSC C12891
C705, C708: 10uF/50V(20%); C_1206_3216Metric; LCSC C13585
C706: 100nF/50V(10%); C_0603_1608Metric; LCSC C14663
D701: LED_12V; LED_0603_1608Metric; LCSC C284922
D702: SMBJ20A; D_SMB; LCSC C3001979
D703: B230A-13-F; D_SMA; LCSC C12889
D704: LED_5V; LED_0603_1608Metric; LCSC C87326
J701: 20-16V Supply Voltage; Molex_39521-1002; Mouser 538-39521-1002
L701: 15uH/1A; L_Changjiang_FNR4018S; LCSC C167809
L702: 4.7uH/2.85A; L_Sunlord_SWPA4020S; LCSC C98363
Q701: SI2309CDS; SOT-23; LCSC C3021112
R701: 10K(1%); R_0603_1608Metric; LCSC C25804
R702, R703, R704, R705: 10R(1%); C_0603_1608Metric; LCSC C22859
R706: 0.18R(5%); R_Shunt_LTR10EVHJLR18; LCSC C253348
R707: 0.3R(5%); R_1210_3225Metric; LCSC C188102
R708, R712: 0R; R_0805_2012Metric; LCSC C17477
R709: 51K(1%); R_0603_1608Metric; LCSC C23196
R710, R713: 2K; R_0603_1608Metric; LCSC C22975
R711: 3.6K(1%); R_0603_1608Metric; LCSC C22980
U701: INA3221; Texas_RGV_S-PVQFN-N16_EP2.1x2.1mm; LCSC C181255
U702: RT8259; TSOT-23-6; LCSC C425775
U703: AP63205WU; TSOT-23-6; LCSC C2071056

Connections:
+3V3: R701.1, U701.4 (VS), U701.16 (VPU); also elsewhere on the board
+12V: D701.2 (A), R708.2; also elsewhere on the board
/20V + 12V/5V_out: C707.2, C709.2, L702.2, R712.1, U703.1 (FB)
/20V + 12V/12V_HS: C704.2, L701.2, R704.2, R707.1
/20V + 12V/12V_LS: R705.2, R707.2, R708.1, R709.1
/20V + 12V/20V_HS: Q701.3 (S), R702.2, R706.1
/20V + 12V/20V_LS: C705.1, C708.1, R703.2, R706.2, U702.5 (VIN), U703.2 (EN), U703.3 (IN)
/20V + 12V/Battery 5V: D704.2 (A), R712.2; also elsewhere on the board
/20V + 12V/IN_20V: D702.2 (A2), J701.2, Q701.1 (D)
/20V + 12V/LX_5V: C706.2, L702.1, U703.5 (SW)
/20V + 12V/LX_12V: C703.2, D703.1 (K), L701.1, U702.6 (PHASE)
/ESP32/12V_DIS: U702.4 (EN); also elsewhere on the board
/ESP32/PMIC_INT: R701.2, U701.10 (PV); also elsewhere on the board
GND: C704.1, C705.2, C707.1, C708.2, C709.1, D702.1 (A1), D703.2 (A), J701.1, Q701.2 (G), R710.2, R711.2, R713.2, U701.3 (GND), U701.5 (A0), U701.17 (EP), U702.2 (GND), U703.4 (GND); also elsewhere on the board
unnamed: D701.1 (K), R710.1
unnamed: D704.1 (K), R713.1
unnamed: C701.1, R702.1, U701.12 (IN+1)
unnamed: C702.2, R704.1, U701.15 (IN+2)
unnamed: C701.2, R703.1, U701.11 (IN-1)
unnamed: C702.1, R705.1, U701.1 (IN-3), U701.14 (IN-2)
unnamed: C703.1, U702.1 (BOOT)
unnamed: R709.2, R711.1, U702.3 (FB)
unnamed: C706.1, U703.6 (BST)
SCL: U701.6 (SCL); also elsewhere on the board
SDA: U701.7 (SDA); also elsewhere on the board

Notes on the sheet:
20V->5V Converter
20V->12V Converter
Overvoltage protection V_{RWM}=20V
f = 1.4MHZ
Maximum electrical ratings: CP2102N 3V3 10mA (USB) ESP32 3V3 500mA MPU 3V3 4mA D52 ANT 3V3 20mA IP101 PHY 3V3 500mA PMICs 3.3V 0.5mA + 0.4mA + 0.03mA + 0.3mA = 1.3mA RESERVE: 200mA 3V3 1.23A = 4W -> (94%)@4.24W LEDs 5V 720mA = 3.6W + 4.24W -> (87%)@8.8592W Radar 12V 500mA = 6W -> (90%)@6.6W 15.46W 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
I_{max}=842mA
I2C addr.: 0b1000000
Battery pack 3.7*5 = 18.5V => max 20V 3.2*5 = 16V
I_{max}=1.28A
Power monitor
f = 1.1MHZ
Recomended sense filtration
I_{max}=0.5A

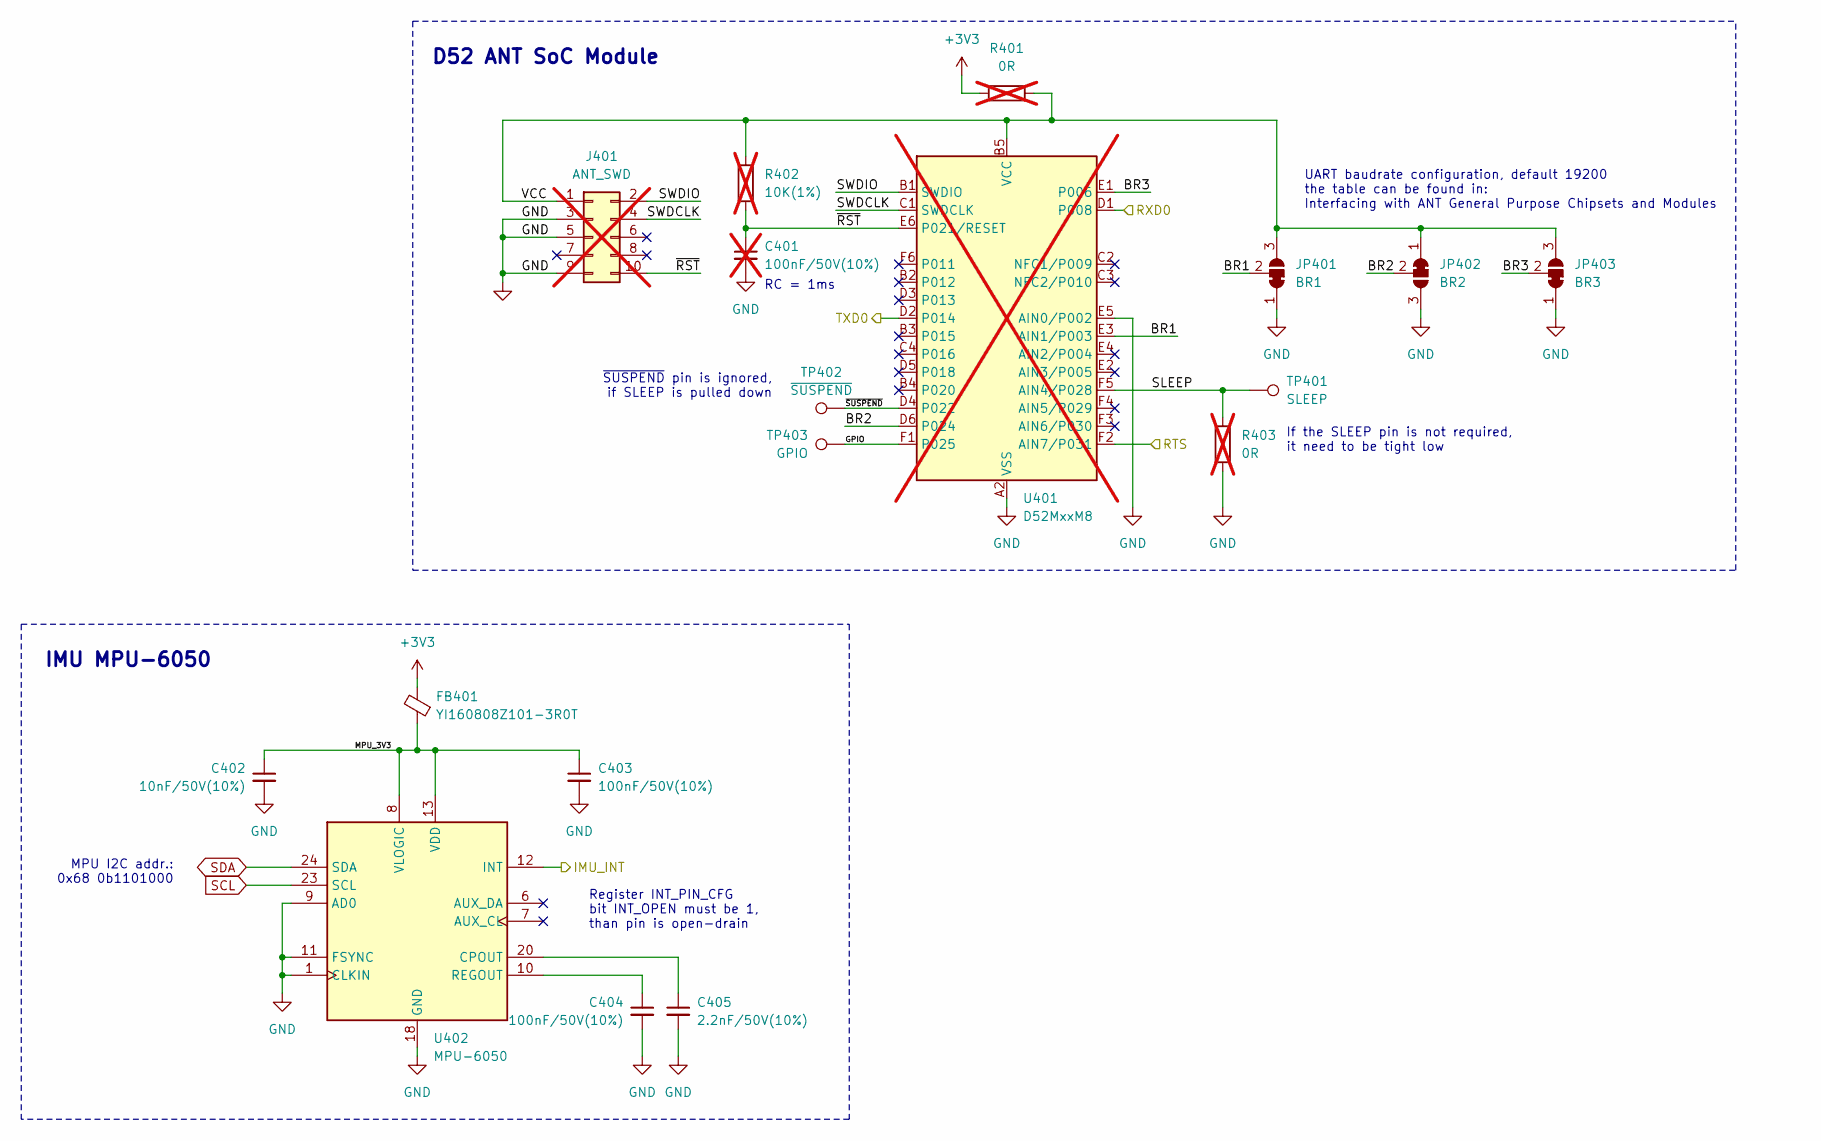
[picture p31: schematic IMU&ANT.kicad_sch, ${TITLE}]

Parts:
C401: 100nF/50V(10%); C_0603_1608Metric; not fitted
C402: 10nF/50V(10%); C_0402_1005Metric; LCSC C15195
C403, C404: 100nF/50V(10%); C_0603_1608Metric; LCSC C14663
C405: 2.2nF/50V(10%); C_0603_1608Metric; LCSC C1604
FB401: YI160808Z101-3R0T; R_0603_1608Metric; LCSC C3011210
J401: ANT_SWD; PinHeader_2x05_P1.27mm_Vertical_SMD; not fitted
JP401: BR1; SolderJumper-3_P1.3mm_Bridged12_RoundedPad1.0x1.5mm_NumberL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
JP402: BR2; SolderJumper-3_P1.3mm_Bridged12_RoundedPad1.0x1.5mm_NumberL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
JP403: BR3; SolderJumper-3_P1.3mm_Bridged12_RoundedPad1.0x1.5mm_NumberL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
R401, R403: 0R; R_0805_2012Metric; LCSC C17477; not fitted
R402: 10K(1%); R_0603_1608Metric; LCSC C25804; not fitted
TP401: SLEEP; TestPoint_Pad_D1.0mm
TP402: ~{SUSPEND}; TestPoint_Pad_D1.0mm
TP403: GPIO; TestPoint_Pad_D1.0mm
U401: D52MxxM8; Garmin_M8-35_9.8x14.0mm_Layout6x6_P1.5mm; DigiKey 1094-1028-ND; not fitted
U402: MPU-6050; InvenSense_QFN-24_4x4mm_P0.5mm; LCSC C24112

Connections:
+3V3: FB401.2, R401.1; also elsewhere on the board
/ESP32/U1RTS: U401.F2 (AIN7/P031); also elsewhere on the board
/ESP32/U1RXD: U401.D2 (P014); also elsewhere on the board
/ESP32/U1TXD: U401.D1 (P008); also elsewhere on the board
/IMU + ANT/BR1: JP401.2 (C), U401.E3 (AIN1/P003)
/IMU + ANT/BR2: JP402.2 (C), U401.D6 (P024)
/IMU + ANT/BR3: JP403.2 (C), U401.E1 (P006)
/IMU + ANT/GPIO: TP403.1, U401.F1 (P025)
/IMU + ANT/MPU_3V3: C402.1, C403.1, FB401.1, U402.8 (VLOGIC), U402.13 (VDD)
/IMU + ANT/SLEEP: R403.1, TP401.1, U401.F5 (AIN4/P028)
/IMU + ANT/SWDCLK: J401.4, U401.C1 (SWDCLK)
/IMU + ANT/SWDIO: J401.2, U401.B1 (SWDIO)
/IMU + ANT/VCC: J401.1, JP401.3 (B), JP402.1 (A), JP403.3 (B), R401.2, R402.2, U401.B5 (VCC), U401.B6 (VCC), U401.C5 (VCC), U401.C6 (VCC)
/IMU + ANT/~RST: C401.1, J401.10, R402.1, U401.E6 (P021/RESET)
/IMU + ANT/~SUSPEND: TP402.1, U401.D4 (P022)
/IMU_INT: U402.12 (INT); also elsewhere on the board
GND: C401.2, C402.2, C403.2, C404.2, C405.2, J401.3, J401.5, J401.9, JP401.1 (A), JP402.3 (B), JP403.1 (A), R403.2, U401.A2 (VSS), U401.A3 (VSS), U401.A4 (VSS), U401.A5 (VSS), U401.A6 (VSS), U401.E5 (AIN0/P002), U402.1 (CLKIN), U402.9 (AD0), U402.11 (FSYNC), U402.18 (GND); also elsewhere on the board
unnamed: C405.1, U402.20 (CPOUT)
unnamed: C404.1, U402.10 (REGOUT)
SCL: U402.23 (SCL); also elsewhere on the board
SDA: U402.24 (SDA); also elsewhere on the board

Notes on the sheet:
UART baudrate configuration, default 19200 the table can be found in: Interfacing with ANT General Purpose Chipsets and Modules
MPU I2C addr.: 0x68 0b1101000
D52 ANT SoC Module
~{SUSPEND} pin is ignored, if SLEEP is pulled down
Register INT_PIN_CFG bit INT_OPEN must be 1, than pin is open-drain
IMU MPU-6050
RC = 1ms
If the SLEEP pin is not required, it need to be tight low

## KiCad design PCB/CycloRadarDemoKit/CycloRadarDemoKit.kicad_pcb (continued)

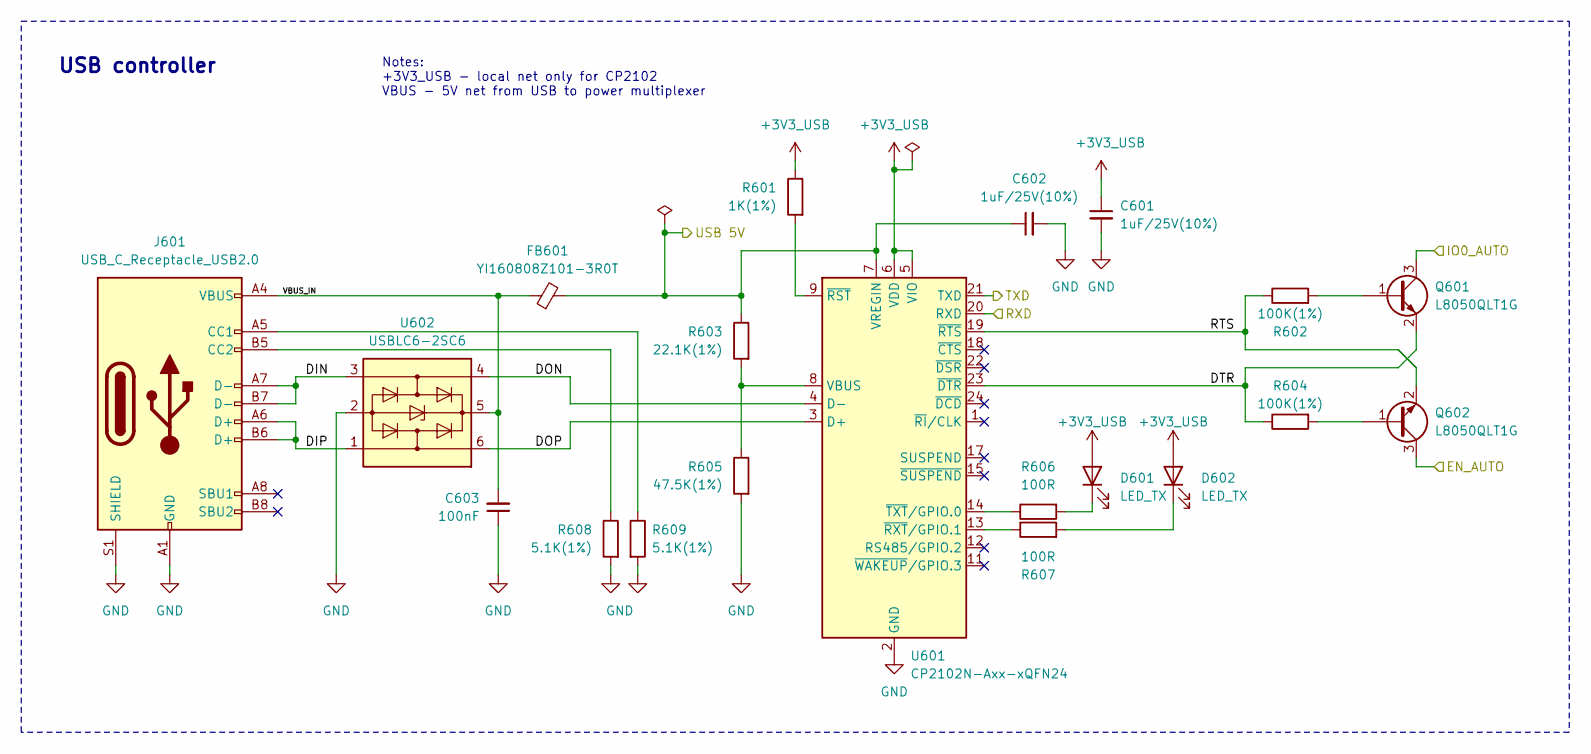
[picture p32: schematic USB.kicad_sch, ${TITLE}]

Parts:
C601, C602: 1uF/25V(10%); C_0402_1005Metric; LCSC C52923
C603: 100nF; C_0402_1005Metric
D601, D602: LED_TX; LED_0603_1608Metric; LCSC C3028830
FB601: YI160808Z101-3R0T; R_0603_1608Metric; LCSC C3011210
J601: USB_C_Receptacle_USB2.0; TYPE-C-SMD_YIYUAN_YTC-TC16-273A1; LCSC C5260486
Q601, Q602: L8050QLT1G; SOT-23; LCSC C49581
R601: 1K(1%); R_0603_1608Metric; LCSC C21190
R602, R604: 100K(1%); R_0603_1608Metric; LCSC C25803
R603: 22.1K(1%); R_0603_1608Metric; LCSC C25961
R605: 47.5K(1%); R_0603_1608Metric; LCSC C23061
R606, R607: 100R; R_0603_1608Metric; LCSC C22775
R608, R609: 5.1K(1%); R_0603_1608Metric; LCSC C23186
U601: CP2102N-Axx-xQFN24; QFN-24-1EP_4x4mm_P0.5mm_EP2.6x2.6mm; LCSC C969151
U602: USBLC6-2SC6; SOT-23-6; LCSC C7519

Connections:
+3V3_USB: C601.1, D601.2 (A), D602.2 (A), R601.1, U601.5 (VIO), U601.6 (VDD)
/5V + 3V3/USB 5V: C602.1, FB601.2, R603.1, U601.7 (VREGIN); also elsewhere on the board
/ESP32/EN_AUTO: Q602.3 (C); also elsewhere on the board
/ESP32/IO0_AUTO: Q601.3 (C); also elsewhere on the board
/USB/DIN: J601.A7 (D-), J601.B7 (D-), U602.3 (I/O2)
/USB/DIP: J601.A6 (D+), J601.B6 (D+), U602.1 (I/O1)
/USB/DON: U601.4 (D-), U602.4 (I/O2)
/USB/DOP: U601.3 (D+), U602.6 (I/O1)
/USB/DTR: Q601.2 (E), R604.1, U601.23 (~DTR)
/USB/RTS: Q602.2 (E), R602.1, U601.19 (~RTS)
/USB/RXD: U601.20 (RXD); also elsewhere on the board
/USB/TXD: U601.21 (TXD); also elsewhere on the board
/USB/VBUS_IN: C603.2, FB601.1, J601.A4 (VBUS), J601.A9 (VBUS), J601.B4 (VBUS), J601.B9 (VBUS), U602.5 (VBUS)
GND: C601.2, C602.2, C603.1, J601.A1 (GND), J601.A12 (GND), J601.B1 (GND), J601.B12 (GND), J601.S1 (SHIELD), R605.2, R608.2, R609.2, U601.2 (GND), U601.25 (GND), U602.2 (GND); also elsewhere on the board
unnamed: D601.1 (K), R606.2
unnamed: D602.1 (K), R607.2
unnamed: J601.A5 (CC1), R609.1
unnamed: J601.B5 (CC2), R608.1
unnamed: Q601.1 (B), R602.2
unnamed: Q602.1 (B), R604.2
unnamed: R603.2, R605.1, U601.8 (VBUS)
unnamed: R601.2, U601.9 (~RST)
unnamed: R607.1, U601.13 (~RXT/GPIO.1)
unnamed: R606.1, U601.14 (~TXT/GPIO.0)

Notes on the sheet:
Notes: +3V3_USB - local net only for CP2102 VBUS - 5V net from USB to power multiplexer
USB controller

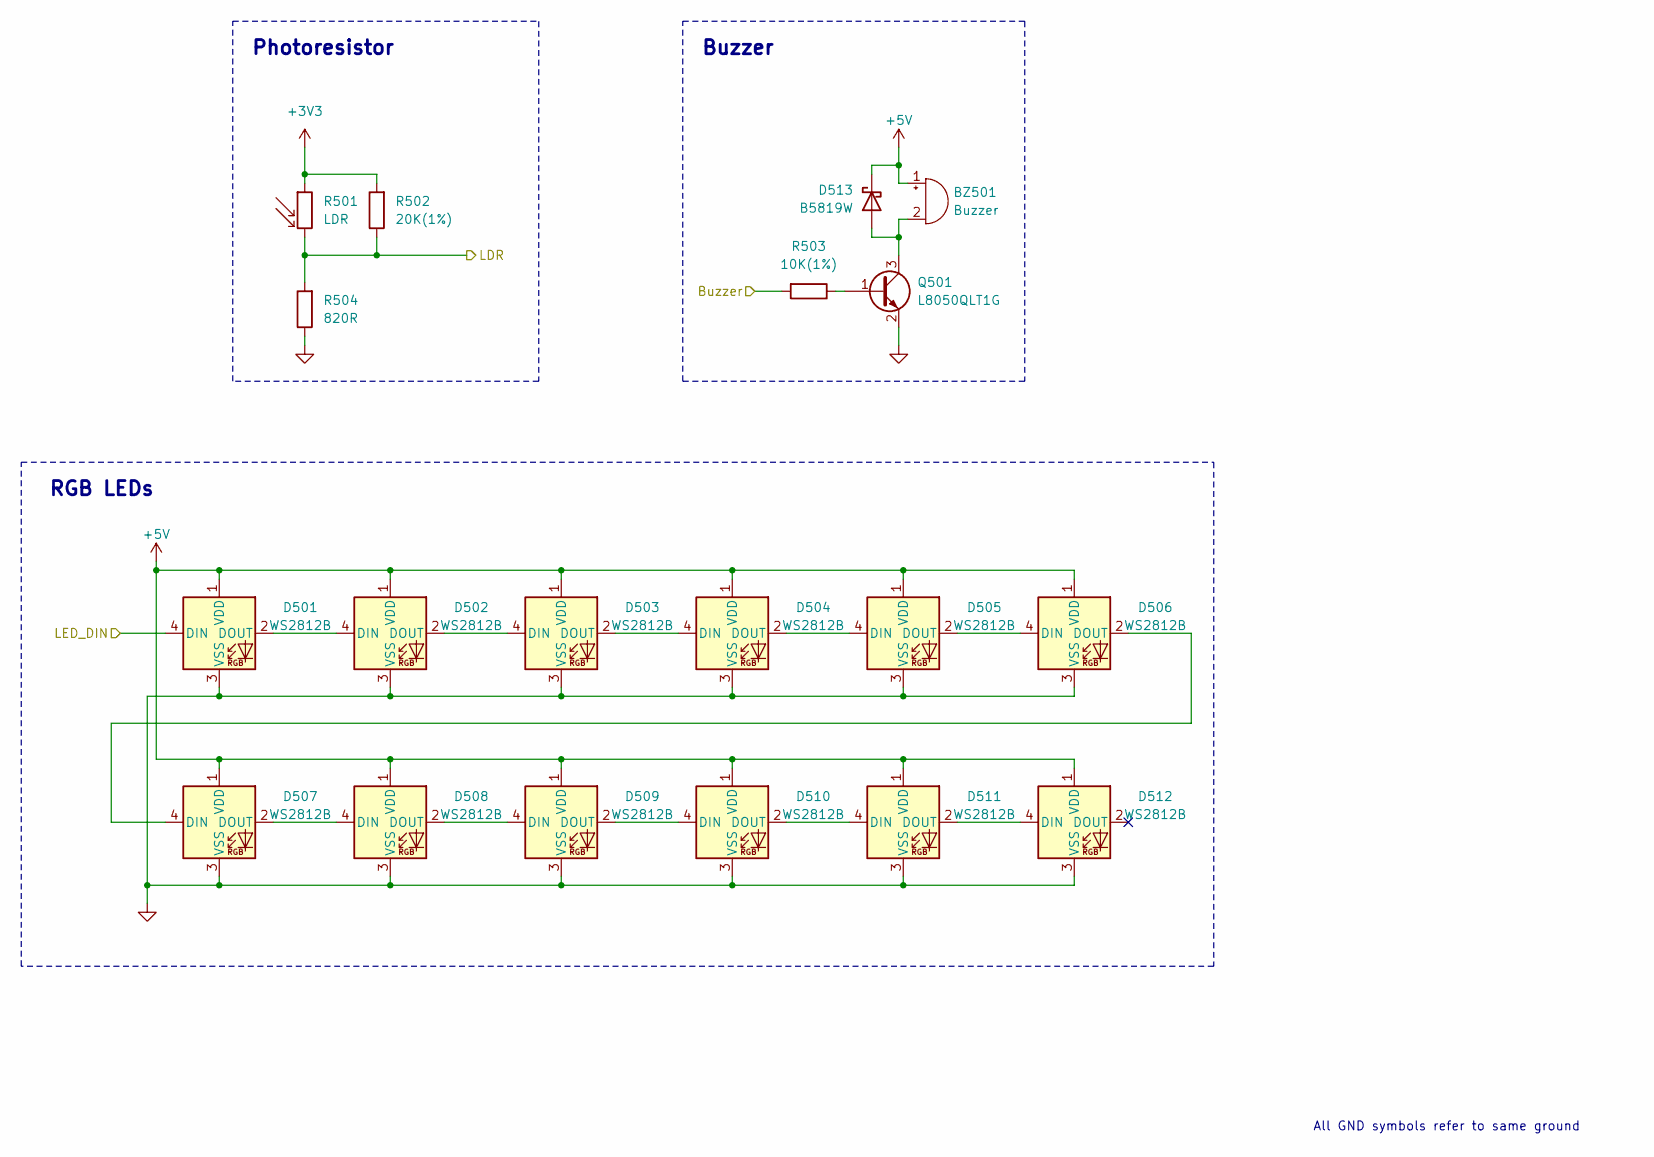
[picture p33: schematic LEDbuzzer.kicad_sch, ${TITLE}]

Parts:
BZ501: Buzzer; Buzzer_D9mm_P5mm; Mouser 253-AX905P3
D501, D502, D503, D504, D505, D506, D507, D508, D509, D510, D511, D512: WS2812B; LED_SK6812MINI_PLCC4_3.5x3.5mm_P1.75mm; LCSC C527089
D513: B5819W; D_SOD-123; LCSC C8598
Q501: L8050QLT1G; SOT-23; LCSC C49581
R501: LDR; R_LDR_5.1x4.3mm_P3.4mm_Vertical
R502: 20K(1%); R_0603_1608Metric; LCSC C4184
R503: 10K(1%); R_0603_1608Metric; LCSC C25804
R504: 820R; R_0603_1608Metric; LCSC C23253

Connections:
+3V3: R501.1, R502.2; also elsewhere on the board
+5V: BZ501.1 (-), D501.1 (VDD), D502.1 (VDD), D503.1 (VDD), D504.1 (VDD), D505.1 (VDD), D506.1 (VDD), D507.1 (VDD), D508.1 (VDD), D509.1 (VDD), D510.1 (VDD), D511.1 (VDD), D512.1 (VDD), D513.1 (K); also elsewhere on the board
/ESP32/Buzzer: R503.2; also elsewhere on the board
/ESP32/LED: D501.4 (DIN); also elsewhere on the board
/ESP32/Photo_res: R501.2, R502.1, R504.2; also elsewhere on the board
GND: D501.3 (VSS), D502.3 (VSS), D503.3 (VSS), D504.3 (VSS), D505.3 (VSS), D506.3 (VSS), D507.3 (VSS), D508.3 (VSS), D509.3 (VSS), D510.3 (VSS), D511.3 (VSS), D512.3 (VSS), Q501.2 (E), R504.1; also elsewhere on the board
unnamed: BZ501.2 (+), D513.2 (A), Q501.3 (C)
unnamed: D501.2 (DOUT), D502.4 (DIN)
unnamed: D502.2 (DOUT), D503.4 (DIN)
unnamed: D503.2 (DOUT), D504.4 (DIN)
unnamed: D504.2 (DOUT), D505.4 (DIN)
unnamed: D505.2 (DOUT), D506.4 (DIN)
unnamed: D506.2 (DOUT), D507.4 (DIN)
unnamed: D507.2 (DOUT), D508.4 (DIN)
unnamed: D508.2 (DOUT), D509.4 (DIN)
unnamed: D509.2 (DOUT), D510.4 (DIN)
unnamed: D510.2 (DOUT), D511.4 (DIN)
unnamed: D511.2 (DOUT), D512.4 (DIN)
unnamed: Q501.1 (B), R503.1

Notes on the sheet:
RGB LEDs
All GND symbols refer to same ground
Photoresistor
Buzzer

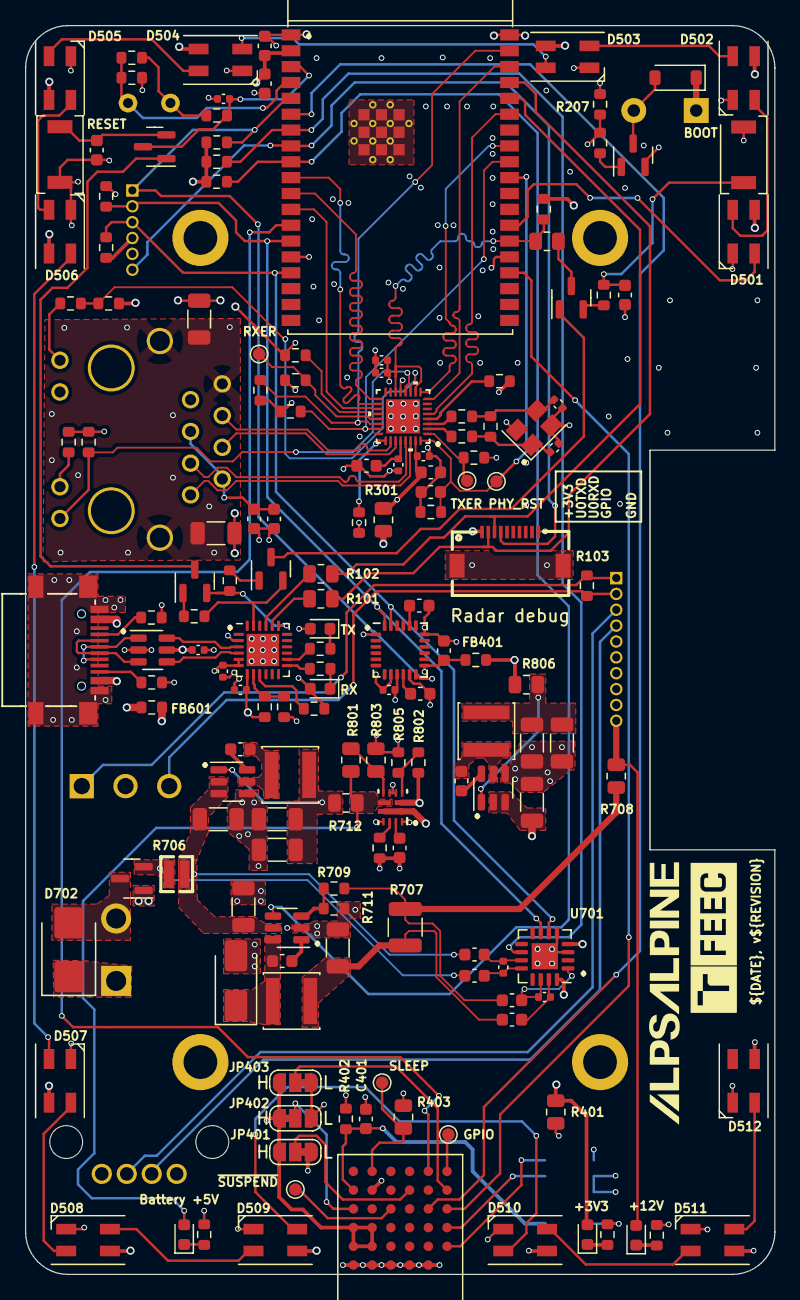
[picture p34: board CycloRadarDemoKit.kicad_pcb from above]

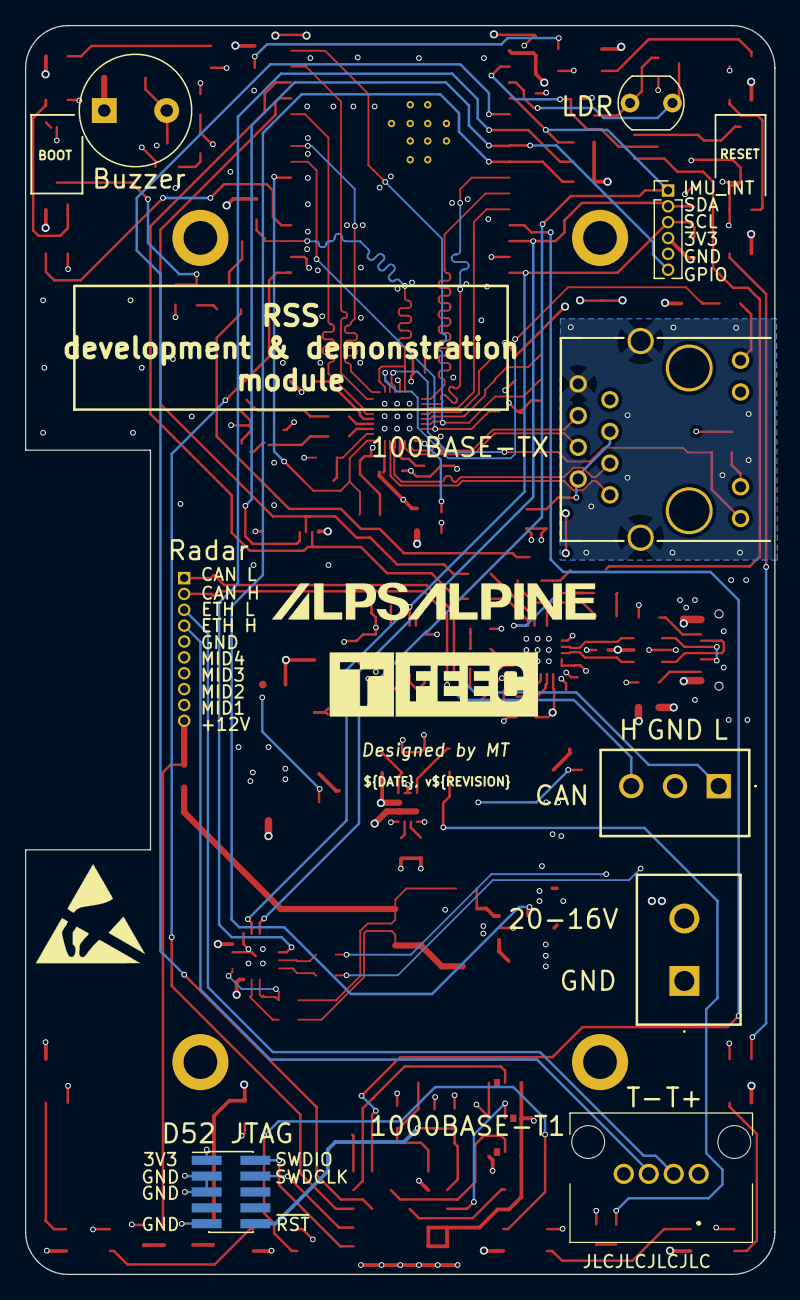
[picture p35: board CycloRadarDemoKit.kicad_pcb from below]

Board: 4 copper layers, 60.0 x 100.0 mm, 173 parts (9 on the bottom side), 133 nets.

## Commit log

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2023-11-14 reorganization of folder
    [CycloRadarDemoKit.kicad_pcb, CycloRadarDemoKit.kicad_sch]
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2023-11-16 PM ICs choosed
    [CycloRadarDemoKit.kicad_pcb, ESP32.kicad_sch, PHY.kicad_sch]
2023-11-16 PCB PHY WIP_1
    [PHY.kicad_sch]
2023-11-18 PCB WIP Started working on CP2102
    [CycloRadarDemoKit.kicad_sch, IMU&ANT.kicad_sch, PHY.kicad_sch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]
2023-11-19 USB designed with TODOs, ESP part changed
    [CycloRadarDemoKit.kicad_pcb, CycloRadarDemoKit.kicad_sch, PM.kicad_sch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]
2023-11-20 Readme, PCB new symbol routed
    [CycloRadarDemoKit.kicad_sch, PHY.kicad_sch, PM.kicad_sch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]
2023-11-21 PCB power manag. WIP
    [CycloRadarDemoKit.kicad_pcb, CycloRadarDemoKit.kicad_sch, PHY.kicad_sch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]
2023-11-23 Power management almost done
    5V/3.3V changed to AP63203
    [CycloRadarDemoKit.kicad_pcb, CycloRadarDemoKit.kicad_sch, PHY.kicad_sch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]
2023-11-24 RJ45 chose, leds connected
    [CycloRadarDemoKit.kicad_pcb, CycloRadarDemoKit.kicad_sch, PHY.kicad_sch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]
2023-11-27 RJ45 footprint added
    [CycloRadarDemoKit.kicad_pcb, CycloRadarDemoKit.kicad_sch, PHY.kicad_sch]
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2023-11-28 MCU routed, two GPIO tested
    [CycloRadarDemoKit.kicad_sch, PM.kicad_sch, USB.kicad_sch]
2023-12-01 MPU added, power managemennt updated
    [CycloRadarDemoKit.kicad_pcb, CycloRadarDemoKit.kicad_sch, IMU&ANT.kicad_sch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]
2023-12-03 added buzzer and pins for Radar
    [CycloRadarDemoKit.kicad_pcb, CycloRadarDemoKit.kicad_sch, IMU&ANT.kicad_sch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]
2023-12-03 more components fthprnt added
    [CycloRadarDemoKit.kicad_pcb, CycloRadarDemoKit.kicad_sch, IMU&ANT.kicad_sch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]
2023-12-03 added more LCSC parts
    [CycloRadarDemoKit.kicad_pcb, CycloRadarDemoKit.kicad_sch, IMU&ANT.kicad_sch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]
2023-12-04 PCB ready for review
    [CycloRadarDemoKit.kicad_pcb, CycloRadarDemoKit.kicad_sch, IMU&ANT.kicad_sch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]
2023-12-05 PCB after review
    [CycloRadarDemoKit.kicad_pcb, CycloRadarDemoKit.kicad_sch, ESP32.kicad_sch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]
2023-12-17 schematic cosmetics, power management diagram upgrated
    [PM.kicad_sch, USB.kicad_sch]
2023-12-19 Schematic edited, split sheets
    improved PM diagram
    [CycloRadarDemoKit.kicad_pcb, CycloRadarDemoKit.kicad_sch, ESP32.kicad_sch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]
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2023-12-19 PCB mockup, grid repaired
    [CycloRadarDemoKit.kicad_pcb]
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2023-12-20 PCB, 3Dmodel
    mockup PCB version done, schcematic exported to latex, 3D model generated and exported to latex
    [CycloRadarDemoKit.kicad_pcb, CycloRadarDemoKit.kicad_sch, ESP32.kicad_sch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]
2023-12-27 sortingAbbr, cosmetics schematic, export schematic to thesis
    [CycloRadarDemoKit.kicad_sch, ESP32.kicad_sch, IMU&ANT.kicad_sch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]
2024-01-04 PCB small updates, schemtatic cosmetics, SEP FINAL
    [CycloRadarDemoKit.kicad_pcb, CycloRadarDemoKit.kicad_sch, ESP32.kicad_sch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]
2024-01-04 buzzer 3D repaired
    [CycloRadarDemoKit.kicad_pcb]
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2024-01-10 All peripherals checked, changed ESP32 pinout
    [CycloRadarDemoKit.kicad_pcb, CycloRadarDemoKit.kicad_sch, ESP32.kicad_sch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]
2024-01-10 PCB holes moved, PCB rounded, 3d model mock-up
    [CycloRadarDemoKit.kicad_pcb]
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2024-01-17 PCB edited, 3D case mock-up
    [CycloRadarDemoKit.kicad_pcb, CycloRadarDemoKit.kicad_sch]
2024-01-17 reanotated schematic, routing started
    [CycloRadarDemoKit.kicad_pcb, CycloRadarDemoKit.kicad_sch, ESP32.kicad_sch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]
2024-01-18 LEDs reodered, connectors moved
    [CycloRadarDemoKit.kicad_pcb, LEDbuzzer.kicad_sch]
2024-01-18 Parts ordered on PCB, 1206->0803 10uF, 0803->0402 1uF
    [CycloRadarDemoKit.kicad_pcb, ESP32.kicad_sch, PHY.kicad_sch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]
2024-01-18 RMII routed, first try
    [CycloRadarDemoKit.kicad_pcb, ESP32.kicad_sch]
2024-01-18 PCB upper part almost routed
    [CycloRadarDemoKit.kicad_pcb]
2024-01-19 PCB upper part ready for review
    [CycloRadarDemoKit.kicad_pcb]
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2024-01-19 PCB grid origin repaired
    [CycloRadarDemoKit.kicad_pcb]
2024-01-19 USB layout, long traces from upper prepaired
    [CycloRadarDemoKit.kicad_pcb, IMU&ANT.kicad_sch, PHY.kicad_sch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]
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2024-01-20 DC/DC routed, stuckup properties changed
    ready for PCB resize
    [CycloRadarDemoKit.kicad_pcb, IMU&ANT.kicad_sch, Power_1.kicad_sch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]
2024-01-20 parts moved, ready to move
    [CycloRadarDemoKit.kicad_pcb]
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2024-01-21 DC/DC placement, conn-s swaped
    [CycloRadarDemoKit.kicad_pcb, USB.kicad_sch]
2024-01-21 Creo 3D design upload (backup)
    [2006-4-15-20-75-14-11-0.stp, Molex_39500-0003.stp, Molex_39520-0002.stp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]
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2024-01-22 PCB and 3D ready for review
    [CycloRadarDemoKit.kicad_pcb]
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2024-01-23 start of repair after review
    [CycloRadarDemoKit.kicad_pcb, CycloRadarDemoKit.kicad_sch, ESP32.kicad_sch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]
2024-01-24 Review changes WIP, USB ESD changed, MDIC pullup added
    [CycloRadarDemoKit.kicad_pcb, CycloRadarDemoKit.kicad_sch, PHY.kicad_sch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]
2024-01-25 ready for 2. review
    [CycloRadarDemoKit.kicad_pcb, PHY.kicad_sch]
2024-01-28 PCB finished and reviewed
    [CycloRadarDemoKit.kicad_pcb, CycloRadarDemoKit.kicad_sch, Power_1.kicad_sch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]
2024-01-29 JLCPCB mistakes repaired, cosmetics on PCB
    [CycloRadarDemoKit.kicad_pcb, CycloRadarDemoKit.kicad_sch, ESP32.kicad_sch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]
2024-01-29 Sematic Versioning implemented, whish list added
    [CycloRadarDemoKit.kicad_pcb, CycloRadarDemoKit.kicad_sch, ESP32.kicad_sch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]
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2024-02-28 plug conn added to Wishlist.xlsx
    [Wishlist_Tavoda.xlsx]
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2024-03-07 photos added, readme rewrited
    [CycloRadarDemoKit.kicad_sch, ESP32.kicad_sch, IMU&ANT.kicad_sch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]
2024-03-09 reverted kicad_pro, the frame was corrupted
2024-03-09 KiCad project updated to KiCad v8.0.0
    [CycloRadarDemoKit.kicad_pcb]
2024-03-09 sensitive files removed 2
    [2006-4-15-20-75-14-11-0.stp, Molex_39500-0003.stp, Molex_39520-0002.stp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]
